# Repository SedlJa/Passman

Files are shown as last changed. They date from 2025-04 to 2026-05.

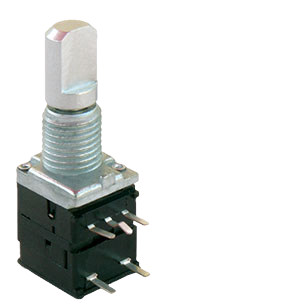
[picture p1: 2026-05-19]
_docs/pec09.png

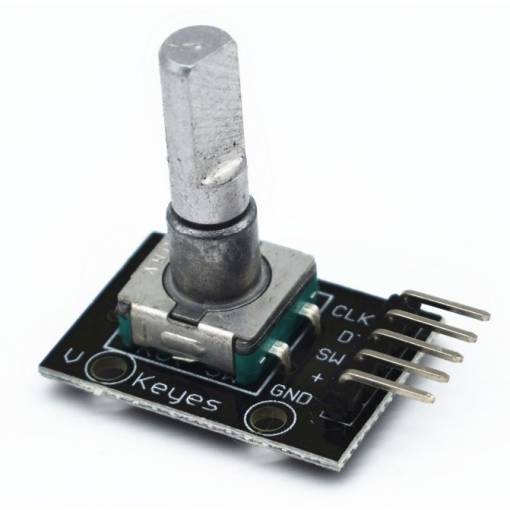
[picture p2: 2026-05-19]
_docs/ky040.jpg

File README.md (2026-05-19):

# Passman

Passman is an embedded password manager with a custom hardware device and a desktop companion application. The project is developed as part of a master's thesis at CTU FEE and combines an ESP32-S3 based device, biometric authentication, local password storage, USB serial communication, and a Python desktop GUI.

The goal is to create a portable hardware password manager that stores credentials locally on the device and allows the user to view, edit, upload, and download the password database through a dedicated desktop application.

## Repository Structure

```text
HW/                 Hardware design files
  pcb/              KiCad PCB project, schematics, BOM and assembly outputs
  Fusion/           3D enclosure models and exported STL files
  block_diagram.svg System block diagram
  PassMan_schematic_v2.1.pdf
  pcb_v2.png
  pcb_2v1.png

SW/
  firmware/         ESP32-S3 firmware built with PlatformIO
  app/              Python / PySide6 desktop application

_docs/              Project documentation and supporting materials
```

## Hardware

The hardware part contains the custom PCB and enclosure design for the Passman device.

Main components:

- ESP32-S3-WROOM-1 module
- 128x64 OLED display with SH1106 controller
- Fingerprint sensor connected over UART
- Rotary encoder with push button
- USB-C connector for power, flashing, and serial communication
- Li-Po battery input and charging circuit
- MCP73831 Li-Po charger
- STBB1-APUR voltage regulator
- User LEDs and reset / boot buttons

Hardware files include:

- KiCad schematic and PCB project
- PDF schematic export
- BOM
- Assembly output
- PCB preview images
- Fusion 360 enclosure exports
- STL files for 3D printing

## Firmware

Firmware is located in `SW/firmware` and is built with PlatformIO.

Target board:

```ini
esp32-s3-devkitm-1
```

Framework:

```ini
Arduino
```

Main firmware features:

- Fingerprint based unlock
- PIN fallback after failed fingerprint attempts
- OLED menu system
- Rotary encoder navigation
- Local password database stored in SPIFFS
- USB serial communication with the desktop app
- Device information reporting
- Password database load, upload, save, and delete actions

Used libraries:

- Ai Esp32 Rotary Encoder
- Adafruit SH110X
- Adafruit GFX
- Adafruit Fingerprint Sensor Library
- ArduinoJson

### Build and Upload Firmware

```bash
cd SW/firmware
pio run
pio run -t upload
pio run -t uploadfs
```

Serial monitor:

```bash
pio device monitor -b 115200
```

## Desktop Application

The desktop app is located in `SW/app`. It is written in Python using PySide6 and communicates with the Passman device over a serial port.

Main app features:

- COM port search and connection handling
- Device information display
- Load password database from device
- Add, edit, and delete password entries
- Upload database back to device
- Password visibility toggle
- Password generator
- Local clearing of displayed data after disconnect

### Run the App

```bash
cd SW/app
python3 -m venv env
source env/bin/activate
pip install -r requirements.txt
python app.py
```

Python dependencies are listed in `SW/app/requirements.txt`.

## Communication

The desktop application and firmware communicate over USB serial at `115200 baud`.

Supported commands include:

- `info` - read device information
- `load` - load database from the device
- `download` - send updated database to the device
- `disconnect` - close the app-device session

## Security Notice

This project is currently a prototype / thesis implementation. Before using it for real credentials, the security model should be reviewed and hardened.

## Author

- Author: Bc. Jan Sedlak
- Supervisor: Ing. Ondrej Nentvich, Ph.D.
- University: Czech Technical University in Prague
- Faculty: Faculty of Electrical Engineering
- Field: Internet of Things Technology
- Department: Department of Radioelectronics

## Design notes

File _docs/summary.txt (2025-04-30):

Diplomová práce 

Microcontroller 
- ESP32-C5 (nejspis tento)
- Nordic - nRF52 
- Raspberry Pi zero w

Memory
- SD karta
- Flash
- EEPROM

Security
- šifrování dat a komunikace
- otisk prstu - optional

Software
- webové UI
- desktop app (Qt?)

Realizace
Samostatné zařízení, které by sloužilo jako „trezor“ pro databázi hesel,
která bude na zařízení zároveň uložena. Uživatelská data budou uložena v zašifrované podobě.
Zařízení se bude dát připojit k PC, ve kterém poběží uživatelksé prostředí. 
To bude sloužit pro správu samotné databáze. 
Databáze bude ve soubor formátu sql, json nebo txt.
Ovládání menu v zařízení bude realizováno pomocí tlačítek/enkodéru.

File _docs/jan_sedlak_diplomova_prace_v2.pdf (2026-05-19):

### České

### vysoké

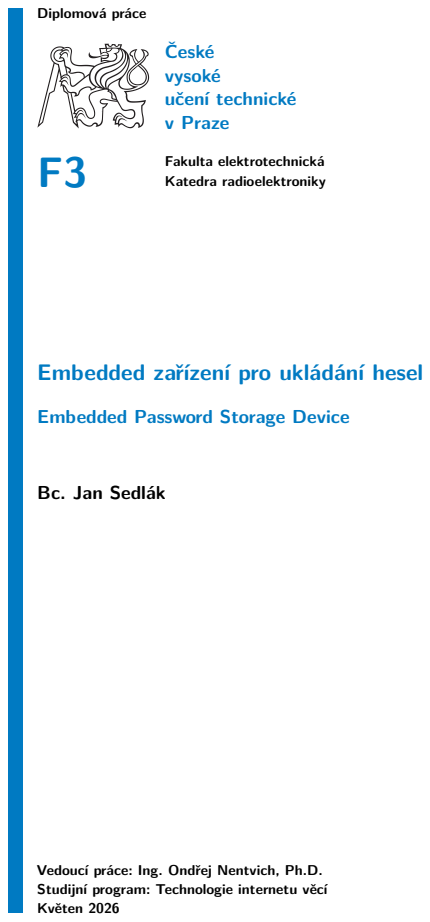
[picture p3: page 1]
Diplomová práce; učení technické v Praze; Fakulta elektrotechnická; Katedra radioelektroniky

Embedded zařízení pro ukládání hesel

Embedded Password Storage Device

Bc. Jan Sedlák

Vedoucí práce: Ing. Ondřej Nentvich, Ph.D.
Studijní program: Technologie internetu věcí
Květen 2026

ii

# ZADÁNÍ BAKALÁŘSKÉ PRÁCE

I. OSOBNÍ A STUDIJNÍ ÚDAJE
Příjmení: | Sedlák | Jméno: | Jan | Osobní číslo: | 507277
Fakulta/ústav: | Fakulta elektrotechnická

Zadávající katedra/ústav: Katedra radioelektroniky

Studijní program: Elektronika a komunikace

II. ÚDAJE K BAKALÁŘSKÉ PRÁCI

Název bakalářské práce:

Embedded zařízení pro ukládání hesel

Název bakalářské práce anglicky:

Embedded Password Storage Device

Pokyny pro vypracování:

Proveďte rešerši možných variant zařízení pro ukládání dat, zejména se poté orientujte na ukládání přístupových údajů a jejich šifrování. Následně navrhněte a realizujte elektronické zařízení pro správu hesel a klíčů s využitím mikrokontroléru. Pro autorizaci přístupu ke správě záznamů využijte zadání uživatelského přístupového hesla nebo otisk prstu. Zadávání a předávání hesel s mikrokontrolérem realizujte s pomocí grafické aplikace.

Seznam doporučené literatury:

[1] NOVIELLO, Carmine. Mastering STM32. 2nd. Leanpub, 2022.
[2] KLEIDERMACHER, David a Mike KLEIDERMACHER. Embedded Systems Security. Elsevier, 2012. ISBN 978-0-12-386886-2.
[3] MAREŠ, Martin a Tomáš VALLA. Průvodce labyrintem algoritmů. Praha: CZ.NIC, 2017. ISBN 978-80-88168-19-5.

Jméno a pracoviště vedoucí(ho) bakalářské práce:

Ing. Ondřej Nentvich, Ph.D. katedra radioelektroniky FEL

Jméno a pracoviště druhé(ho) vedoucí(ho) nebo konzultanta(ky) bakalářské práce:

Datum zadání bakalářské práce: 24.01.2024 | Termín odevzdání bakalářské práce: 24.05.2024

Platnost zadání bakalářské práce: 21.09.2025

___________________________ | ___________________________ | ___________________________ prof. Mgr. Petr Páta, Ph.D. podpis děkana(ky)
doc. Ing. Stanislav Vítek, Ph.D.
podpis vedoucí(ho) ústavu/katedry

Ing. Ondřej Nentvich, Ph.D.
podpis vedoucí(ho) práce
III. PŘEVZETÍ ZADÁNÍ

Student bere na vědomí, že je povinen vypracovat bakalářskou práci samostatně, bez cizí pomoci, s výjimkou poskytnutých konzultací. Seznam použité literatury, jiných pramenů a jmen konzultantů je třeba uvést v bakalářské práci.

Datum převzetí zadání | Podpis studenta
CVUT-CZ-ZBP-2015.1 | © VUT v Praze, Design: VUT v Praze, VIC

iv

## Poděkování

TBD

## Prohlášení

Prohlašuji, že jsem předloženou práci vypracoval samostatně a že jsem uvedl veškeré použité informační zdroje v souladu s Metodickým pokynem o dodržování etických principů při přípravě vysokoškolských závěrečných prací.

V Praze, 16. dubna 2026

v

## Abstrakt

TBD

Klíčová slova: embedded systém, heslo, otisk prstu, šifrování, mikrokontrolér, správce hesel

## Abstract

TBD

Keywords: embedded system, password, fingerprint, encryption, microcontroller, password manager

vi

## Obsah

Úvod | 1
1 Teoretická část | 3

1.1.2 Délka: První úroveň ochrany . 3

1.3 Problematika zabezpečení

1.3.2 HSM (Hardware Security Module) vs TPM (Trusted Platform

1.3.3 TEE (Trusted Execution

1.3.5 Ochrana paměti (MPU/MMU) 11 1.3.6 Bezpečné OTA aktualizace

1.6 Kybernetické útoky na embedded

2 Návrh hardwaru | 21

2.7 Konstrukční řešení a návrh

3 Firmware | 31

3.2.1 Návrh komunikačního

3.3 Bezpečnostní modul a ochrana dat 33

3.3.3 Distribuce a správa

3.5 Optimalizace a specifická

4 Desktopová aplikace | 39
4.1 Architektura a datový model . . . 39
5 Ověření funkčnosti | 45
6 Závěr | 47
Zkratky | 49
Literatura | 51

vii

## Obrázky

1.1 Mooltipass [22] | 7
1.2 Trust Zone diagram [9] | 10
2.1 Blokové schéma zapojení | 21
2.2 Vybraný kontrolér ESP32 S3
WROOM 1 | 23
2.3 Zapojení kontroléru ESP32 S3 . . 23 2.4 Vstupní část power managementu 25 2.5 Nabíjecí obvod Li-Pol baterie . . . 25 2.6 Navržený Buck-Boost zdroj . . . . 26
2.7 Vybrané komponenty | 28
2.8 Layout navrženého PCB | 29
2.9 Pohled shora | 30
3.1 Master-Slave architektura | 32
3.2 Otisk prstu | 34
3.3 UI: Přidání nového otisku prstu 34
3.4 UI: Database | 35
3.5 UI: Connect to Device | 36
3.6 UI: Save Database | 36
3.7 UI: Delete Database | 36
3.8 UI: Device Info | 37
3.9 Diagram logiky firmwaru | 37
4.1 Strktura aplikace | 40
4.2 Připojovací sekce aplikace | 41
4.3 Databáze hesel | 42
4.4 Nástroje | 43
4.5 Funkce generování hesla | 43
4.6 Uživatelské rozhraní aplikace . . . 44

## Tabulky

1.1 Příklady softwarových správců
hesel | 5
1.2 Přehled klíčových komponent
Secure bootu | 8
1.3 Porovnání HSM vs TPM | 10
1.4 Typické použítí TEE | 11
1.5 Porovnání MPU vs MMU | 13

2.1 Porovnání klíčových parametrů
jednotlivých kontrolérů | 24
2.2 Porovnání spínaného zdroje s
LDO | 26
2.3 Technické parametry vybraného
displeje | 27
2.4 Technické parametry senzoru
DY50 | 27
2.5 Technické parametry eknodéru
KY040 | 28
3.1 Placeholder Caption | 35

viii

## Úvod

Heslo. Pojem, který zná každý z nás. Dnes a denně jej používáme a vytváříme nové. Přesto často nedbáme na jeho dostatečnou sílu a způsob uložení. Stáváme se tak jednoduchým cílem kybernetických útoků, a to ve světě, kde je digitální identita naprosto klíčová, může mít často fatální následky. Jedním z řešení je využít správce hesel, tedy nástroj, který umožňuje vytvářet silná hesla, bezpečně je ukládat a minimalizovat šanci na jejich odcizení.

Práce zkoumá jak možnosti bezpečného ukládání hesel, šifrování i hardwarové zabezpečení, tak i vybrané způsoby autentizace uživatele. Cílem této práce je provést rešerši aktuální nabídky nástrojů pro správu hesel a jejich šifrování a následně zrealizovat elektronické zařízení pro správu přístupových údajů s desktopovou aplikací.

Tato práce přináší nejen vhled do problematiky dnešní digitální bezpečnosti, ale také praktickou implementaci v podobě samotného zařízení. Jejím cílem je přispět k lepší ochraně digitální identity prostřednictvím uživatelsky přívětivých nástrojů pro správu hesel.

1

2

## Kapitola 1

## Teoretická část

V úvodu teoretické části se zaměřím, jak by mělo vypadat kvalitní, silné a neprolomitelné heslo, které má parametry odpovídající dnešní době. Tyto informace využiji pro porovnání jednotlivých řešení správců hesel. Následně rozeberu závažnost správného výběru šifrování, které podrobně analyzuji. V poslední části se zaměřím na autentizaci uživatele, kde na základě provedené rešerše přiblízím čtenáři nejbezpečnější způsoby ověření uživatele.

### 1.1 Heslo

Heslo je řetězec znaků, který slouží k ověření identity uživatele během jeho autentizace. Hesla se obvykle používají společně s dalším bezpečnostním prvkem, uživatelským jménem; jsou navržena tak, aby je znal pouze uživatel, kterému umožňují získat přístup k zařízení, aplikaci nebo webové stránce [?].

### 1.1.1 Anatomie hesla

Vytvoření neprolomitelného hesla vyžaduje mnohem více než jen kombinaci písmen a číslic. Pokud k jeho tvorbě chceme přistoupit zodpovědně, musíme brát v úvahu několik faktorů, které definují jeho sílu. Mezi hlavní faktory patří délka, komplexnost a unikátnost.

### 1.1.2 Délka: První úroveň ochrany

V době, kdy procesory dosahují neuvěřitelných rychlostí, hraje délka hesla klíčovou roli při určování jeho síly. Čím delší heslo, tím více existuje možných kombinací, což hackerům výrazně snižuje šanci na jeho prolomení. Minimální bezpečná délka je dnes uváděna jako 12 znaků, za předpokladu, že jsou použita malá a velká písmena, číslice a speciální symboly [1].

### 1.1.3 Komplexnost

Komplexnost je dalším, neméně důležitým faktorem, který dokáže ovlivnit sílu hesla a učinit z něj doslova neprolomitelný klíč. Uživatel by se měl vyvarovat čemukoliv, co ho s heslem byť jen nepatrně spojuje, jako jsou jména, oblíbené

3

# 1. Teoretická část |

sportovní týmy, důležitá a snadno dohledatelná data. Místo toho je vhodné
použít zcela náhodná slova v kombinaci s čísly a symboly. Teprve tímto způsobem jsme schopni vytvořit neprolomitelné heslo [16].

### 1.1.4 Unikátnost

Používání stejného hesla pro několik různých přístupů je dnes nejčastější chybou, kterou dělá prakticky každý. Pramení z toho riziko, že pokud se útočníkovi podaří prolomit jedno vaše heslo, automaticky získá přístup i do ostatních účtů "chráněných"stejným heslem. Mít unikátní heslo pro každý jednotlivý účet se zdá být nemožným úkolem; přesto je však zásadním prvkem pro vaši bezpečnost. Přesně z tohoto důvodu je doporučeno používat správce hesel. Na trhu je jich nepřeberné množství a je tak pouze na uživateli, aby si vybral takového, který mu bude nejvíce vyhovovat [16].
PŘIDAT NĚJAKOU ZMÍNKU Z PRŮZKUMŮ, JAK LIDI PO-UŽÍVAJÍ HESLA KOLIK JICH MAJI ATD

### 1.2 Správci hesel

Správce hesel je softwarový nebo hardwarový nástroj primárně navržený ke generování, uchovávání a správě přístupových údajů. Základním bezpečnostním principem většiny správců hesel je šifrování databáze s využitím silných symetrických šifer (standardně AES-256). K odemčení této databáze používá uživatel hlavní heslo.

Hlavní heslo se nikdy neukládá v prostém textu; místo toho se z něj pomocí funkcí pro derivaci klíče (KDF – Key Derivation Function, typicky PBKDF2, Argon2 nebo bcrypt) vygeneruje šifrovací klíč. Národní institut standardů a technologie (NIST) ve svém doporučení SP 800-63B výslovně podporuje používání správců hesel, neboť eliminují nutnost pamatovat si velké množství komplexních hesel a minimalizují riziko jejich recyklace [6].

Moderní správci hesel se z prostých šifrovaných databází vyvinuli v komplexní nástroje pro správu digitální identity. Kromě samotného bezpečného uložení přihlašovacích údajů nabízejí sadu funkcí, které zvyšují jak bezpečnost, tak uživatelskou přívětivost:

. Generování kryptograficky silných hesel - Schopnost automaticky

vytvářet hesla s vysokou entropií.
. Automatické vyplňování - Nástroj detekuje doménu webové stránky

a automaticky vyplní přihlašovací údaje. Kromě pohodlí jde o klíčovou ochranu proti phishingu – pokud uživatel klikne na podvodný odkaz (např. g00gle.com), správce hesel pole nevyplní, protože doména neodpovídá uloženému záznamu.
. Bezpečné sdílení - Možnost asymetricky zašifrovat konkrétní záznam a

bezpečně jej sdílet s jiným uživatelem (např. v rámci rodiny nebo firmy),

4

# | 1.2. Správci hesel

aniž by heslo bylo odesláno přes nezabezpečené kanály, jako je e-mail nebo chat.
. Podpora vícefaktorové autentizace (MFA) a správa TOTP -

Většina správců hesel dnes umí generovat jednorázová hesla (Time-based One-Time Password), čímž nahrazuje dedikované aplikace jako Google Authenticator.
. Monitoring kompromitovaných hesel a Dark Webu - Nástroje

automaticky porovnávají hashe uložených hesel s databázemi uniklých přihlašovacích údajů (např. služba Have I Been Pwned) a aktivně uživatele upozorňují na nutnost změny.
. Nouzový přístup - Funkce umožňující delegovat přístup do trezoru

pověřené osobě po uplynutí předem stanovené čekací doby (např. v případě nehody či úmrtí).

### 1.2.1 Rozdělení Správců hesel

Správce hesel lze rozdělit z hlediska samotné implementace a způsobu úložení dat na dvě hlavní kategorie - softwarová a hardwarová řešení.

Softwarová řešení

Softwaroví správci hesel existují nejčastěji jako samostatné aplikace pro operační systémy nebo jako rozšíření pro webové prohlížeče. Dále se dělí na cloudové (data jsou synchronizována přes servery poskytovatele, např. Bitwarden, 1Password), lokální (data neopouštějí zařízení, např. KeePass) a správce v rámci prohlížečů (Google Chrome, Mozilla Firefox a další).

Typ | Název
Lokální Lokální Lokální Cloudový Cloudový Cloudový | KeePassXC Valutwarden Enpass Bitwarden Dashline Proton Pass

Tabulka 1.1: Příklady softwarových správců hesel

Lokální správci hesel
U lokálních správců (např. KeePassXC, Password Safe) je zašifrovaná databáze uložena výhradně na fyzickém úložišti uživatele a nikdy není automaticky přenášena přes internet. Mezi hlavní výhody patří naprostá kontrola nad daty. Tím, že data neopouštějí zařízení, útočník bez fyzického přístupu k zařízení nebo bez infikování stroje malwarem je nemůže získat. Nic není dokonalé a i lokální řešení přináší svá rizika:

5

# 1. Teoretická část |

. Ztráta a fragmentace dat - Pokud uživatel nebude svá data průběžně

zálohovat a dojde k selhání hardwaru, je ztráta dat nevratná. Synchronizace napříč zařízeními (např. přes USB nebo sdílený disk) často vede ke kolizím verzí databáze.
. Forenzní a paměťová zranitelnost - Jak ve své studii prokázali Gray

et al. (2016), lokální správci hesel mohou být zranitelní vůči analýze operační paměti (RAM). Výzkum ukázal, že po odemčení databáze nebo dokonce po uzavření aplikace mohou fragmenty hlavního hesla či dešifrovaných dat zůstat v paměťových stránkách, odkládacích souborech (pagefile) nebo dočasných složkách, odkud je může sofistikovaný malware extrahovat [7].

Cloudoví správci hesel
Tato řešení (např. Bitwarden, 1Password) ukládají zašifrované trezory na centrálních serverech poskytovatele. Využívají tzv. architekturu nulové znalosti (Zero-Knowledge architecture), což znamená, že veškeré šifrování a dešifrování probíhá lokálně na koncovém zařízení uživatele a na server se odesílá pouze zašifrovaný řetězec dat. Hlavní výhodou je dokonalá a okamžitá synchronizace napříč všemi platformami, na kterých je uživatel přihlášen, a automatické zálohování zajištěné poskytovatelem. Stejně jako lokální řešení, ani cloudoví správci se neobejdou bez rizik:
. Hromadné úniky dat ze strany poskytovatele - Servery poskytova-

telů představují vysoce atraktivní cíl (tzv. honeypot) pro kyberzločince. Pokud útočníci prolomí infrastrukturu poskytovatele, mohou zkopírovat zašifrované trezory všech uživatelů. Zde vzniká riziko offline dictionary útoku: pokud má uživatel slabé hlavní heslo, útočník jej může na vlastním výkonném hardwaru bez omezení počtu pokusů prolomit.
. Závislost na infrastruktuře třetí strany - Výpadek serverů může

dočasně zamezit přidávání či synchronizaci nových hesel.
. Útoky na dodavatelský řetězec (Supply Chain) - Zneužití aktuali-

začního mechanismu nebo zkompromitování webového klienta může vést k podvržení škodlivého kódu (např. JavaScriptu), který by hlavní heslo zachytil dříve, než dojde k lokálnímu zašifrování.

Správci hesel v prohlížečích
Prohlížeče jako Google Chrome, Mozilla Firefox nebo Microsoft Edge dnes obsahují nativní správce hesel. Jsou hluboce integrovány do webového rozhraní a spjaty s uživatelským profilem prohlížeče. Hlavní výhodou je jednoduchost vstupu pro běžného uživatele. Nevyžadují instalaci žádného dodatečného softwaru a fungují plynule z pohledu uživatelského zážitku (UX). Je tedy zcela na uživateli, zda se pro jeho užívání rozhodne. Oproti předchozím řešením mívají tito správci omezené funkce. Velkým rizikem použití mohou být podvržené webové stránky s neviditelným formulářem, který zneužívá funkci automatického vyplnění údajů.

6

| 1.3. Problematika zabezpečení embedded zařízení

### 1.2.2 Hardwarové řešení

Fyzická řešení představují oddělená hardwarová zařízení navržená tak, aby chránila šifrovací klíče a hesla mimo běžný operační systém. Patří sem specializovaní hardwaroví správci hesel a bezpečnostní tokeny (např. YubiKey, Trezor), které k autentizaci využívají protokoly FIDO2, WebAuthn nebo UWB (Ultra-Wideband) lokalizaci pro potvrzení fyzické přítomnosti [3]. Na trhu již existovalo několik typů embedded správců hesel, žádný z nich se však neuchytil v běžném každodenním používání.

Za zmínku stojí například PasswordFast a PasswordSafe, obě zařízení disponovala klávesnicí a displejem, nicméně pro každodenní používání byla nepraktická. Nejkomplexnějším řešením bylo zařízení Mooltipass, které bylo zabezpečeno hlavním heslem a šifrováním AES-256. Umožňovalo připojení k libovolnému zařízení pomocí bluetooth a následné doplňování údajů do přihlašovacích formulářů. Pozdější verze disponovala i rozšířením do prohlížeče.

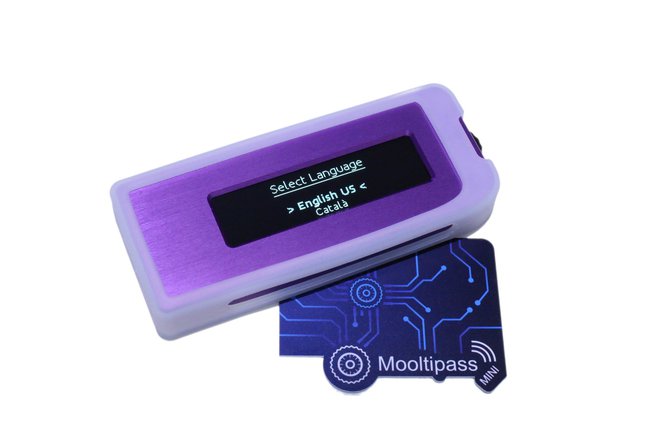
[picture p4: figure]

Obrázek 1.1: Mooltipass [22]

### 1.3 Problematika zabezpečení embedded zařízení

Zabezpečení embedded zařízení se v posledních letech stalo kritickou disciplínou, především kvůli masivnímu rozvoji Internetu věcí (IoT). Na rozdíl od běžných počítačů jsou embedded systémy často nasazeny v nekontrolovaném prostředí, což je vystavuje nejen síťovým, ale i přímým fyzickým útokům. Z tohoto důvodu je třeba myslet na zabezpečení systému již v samotném počátku jeho návrhu. V této sekci bude rozebráno několik softwarových i hardwarových způsobů ochrany, které se používají pro embedded systémy.

### 1.3.1 Secure boot

Secure Boot je kritický bezpečnostní mechanismus, který zajišťuje, aby se v zařízení spustil pouze software, který je autentický a nebyl nijak pozměněn. V prostředí embedded systémů se jedná o nejdůležitější prvek ochrany, protože tvoří tzv. Root of Trust, na kterém stojí veškeré další zabezpečení [11].

7

# 1. Teoretická část |

Princip Rooot of trust

Základní myšlenkou Secure Bootu je, že každá komponenta softwaru před svým spuštěním ověří integritu a autenticitu následující komponenty. Pokud je řetězec v kterémkoli bodě přerušen, nesedí podpis, systém se zastaví a odmítne pokračovat v bootování. Celkový řetězec může vypadat následovně:

.1. Hardware / Mask ROM - Neupravitelný kód vypálený přímo v

procesoru výrobcem. Obsahuje veřejný klíč výrobce.

.2. First Stage Bootloader (FSBL) - Kód ověřený pomocí Mask ROM.

.3. Main Bootloader - Ověřen předchozím bootloaderem.

.4. Operační systém (Kernel) - Ověřen bootloaderem.

.5. Aplikace / Souborový systém - Ověřeny kernelem.

Jak probíhá proces ověření?
Proces využívá asymetrickou kryptografii a hashovací funkce. Při výrobě výrobce vezme binární kód a vytvoří z něj hash, unikátní otisk. Tento hash poté zašifruje svým soukromým klíčem. Výsledkem je digitální podpis, který se přiloží k samotnému firmwaru. Při spuštění pak procesor vypočítá hash firmwaru a pomocí veřejného klíče, který je uložen v dedikované zabezpečené části hardwaru, dešifruje přiložený digitální podpis. Pokud se vypočítaný hash shoduje s dešifrovaným hashem z podpisu, je potvrzeno, že [17]:
. Kód pochází od držitele soukromého klíče - tím je dodržena Autenticita.

. Kód nebyl od okamžiku podpisu změněn ani o jediný bit - tím je zajištěna

Integrita.

Tabulka 1.2: Přehled klíčových komponent Secure bootu

Komponenta | Popis
Root of Trust (RoT) | Hardwarový základ (často ROM kód), který nelze změnit. Je to “první článek”, kterému systém věří implicitně.
Kryptografické klíče | Veřejné klíče jsou uloženy v zařízení (často v tzv. eFuses – jednorázově programovatelných pamětech), soukromé klíče má výrobce v přísně střeženém prostředí (HSM).
eFuses | Miniaturní elektronické pojistky v čipu. Jakmile se jednou “přepálí” (nastaví na 1), nelze je změnit zpět na 0. Slouží k trvalému uložení hashe veřejného klíče.
Revokační seznamy | Seznamy “zakázaných” klíčů nebo verzí softwaru. Pokud je zjištěna zranitelnost ve starší verzi, Secure Boot díky nim zabrání tzv. Rollback útoku (nucený návrat ke starší, zranitelné verzi).

Secure boot chrání před nasazením rootkitu a bootkitu, což jsou malware, které se snaží usadit v systému ještě před startem antiviru nebo samotného

8

| 1.3. Problematika zabezpečení embedded zařízení

operačního systému. Zároveň znemožňuje útočníkovi nahrát vlastní, upravený firmware či rovnou vyměnit flash paměť s kódem. V takovém případě by hash nesouhlasil.

Použití secure bootu přináší i svá úskalí v podobě ztráty klíčů. Pokud výrobce ztratí soukromé klíče, je nemožné vydat aktualizaci pro existující zařízení. V případě výskytu chyby v samotném RoT je chyba uložena v ROM paměti a daný hardware je tak trvale a neopravitelně kompromitován [21].

### 1.3.2 HSM (Hardware Security Module) vs TPM (Trusted

Platform Module)

Hardware Security Module

Zatímco TPM je zaměřen na integritu platformy, HSM je vysoce výkonné zařízení zaměřené na správu životního cyklu klíčů a masivní kryptografické operace. V embedded světě se často setkáváme s Hardware Security Engine (HSE) nebo Secure Hardware Extension (SHE), což jsou "lehčí"verze HSM integrované přímo v mikrokontrolérech (např. v automotive průmyslu) [14].

HSM jsou optimalizovány pro rychlé zpracování kryptografických operací, jako jsou AES, RSA nebo ECC, bez zatěžování hlavního procesoru.

Samotné HSM běží na vlastním kódu, který je zcela nezávislý na hlavním firmwaru zařízení. Při proniknutí útočníka do hlavního systému tak zůstává HSM neovládnut [4].

Trusted Platform Module

TPM je mezinárodní standard pro bezpečný kryptoprocesor. V embedded systémech se nejčastěji vyskytuje jako samostatný čip připojený přes sběrnici (SPI, I2C) nebo jako integrovaná součást SoC (System on Chip) [14].

TPM dokáže hashovat stav systému během bootování, a pokud dojde ke změně firmwaru nebo jeho konfigurace, hash v konfiguračních registrech nebude odpovídat a TPM odmítne vydat dešifrovací klíč.

Disponuje bezpečným uložištěm pro ukládání hesel, certifikátů a šifrovacích klíčů. Klíče jsou označeny jako neexportovatelné a nikdy neopustí čip v čitelné podobě. Pro dosažení silné kryptografie disponuje TPM také hardwarovým generátorem náhodných čísel [4].

### 1.3.3 TEE (Trusted Execution Environment)

Trusted Execution Environment (TEE) je bezpečné, izolované prostředí uvnitř hlavního procesoru, které běží paralelně s hlavním operačním systémem. Toto

9

# 1. Teoretická část |

Tabulka 1.3: Porovnání HSM vs TPM

Funkce | TPM (Trusted Platform Module) | HSM (Hardware Security Module)
Hlavní účel | Integrita zařízení a bezpečný boot. | Rychlá kryptografie a ochrana klíčů.
Výkon | Nižší (vhodné pro autentizaci). | Vysoký (vhodné pro šifrování streamů dat).
Typ klíčů | Často pevně vázané na hardware. | Flexibilní správa tisíců klíčů.
Standardy | TCG (Trusted Computing Group). | FIPS 140-2 (Level 3/4), Common Criteria.
Typické použití | Notebooky, průmyslová PC, brány. | Bankovní terminály, servery, řídicí jednotky aut.

prostředí je hardwarově odděleno od zbytku procesoru. Zatímco hlavní operační systém je optimalizován pro výkon a konektivitu, TEE je navržen s prioritou a optimalizací pro bezpečnost a integritu dat [15].

Nejrozšířenější implementací TEE je technologie ARM TrustZone. Ta rozděluje procesor na dvě virtuální domény:
. Normal World (Non-secure) - Zde běží běžný OS (např. Linux,

Android) a uživatelské aplikace. Přístup do Secure world je striktně omezen.
. Secure World - Zde běží veškerý Trusted OS a v něm izolované mikro-

aplikace, známé jako Trusted Applications.

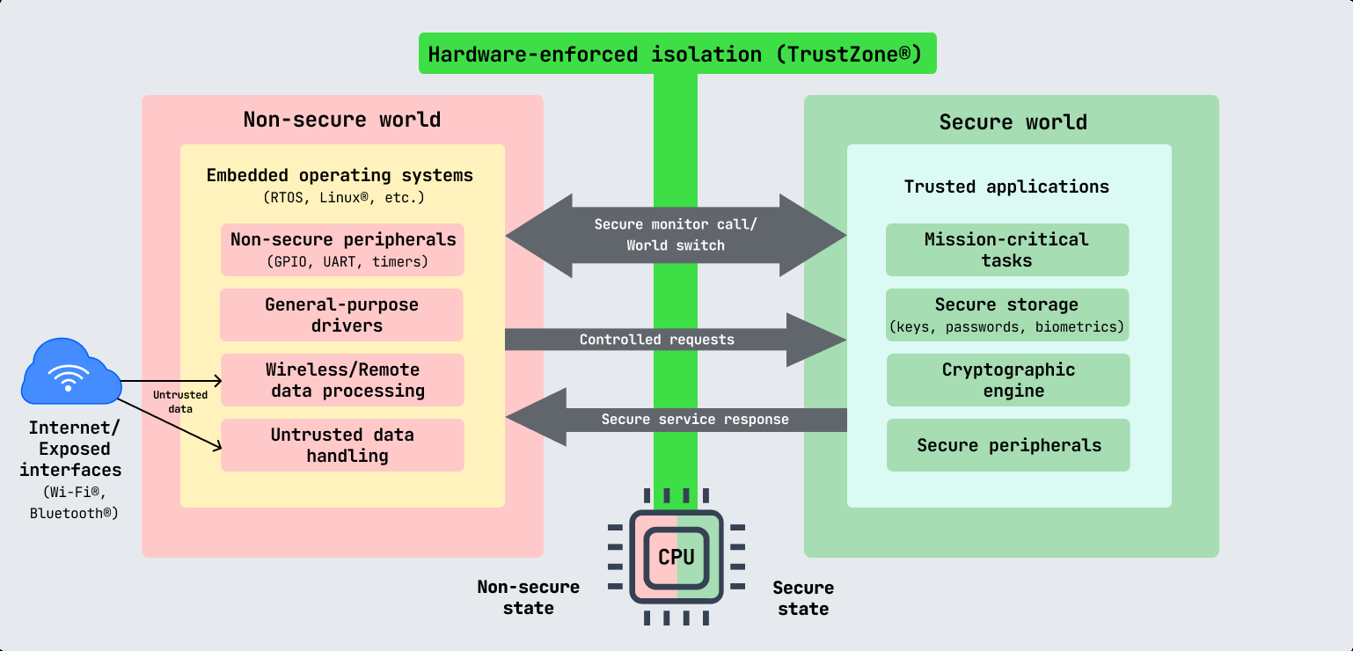
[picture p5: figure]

Obrázek 1.2: Trust Zone diagram [9]

Z obrázku 1.2 lze vidět, jakým způsobem probíhá komunikace mezi oběma částmi procesoru. Z nezabezpečeného světa vyšle operační systém kontrolo-

10

| 1.3. Problematika zabezpečení embedded zařízení

vaný dotaz, Controlled request, v tento okamžik je aktivován i Secure monitor, který dohlíží na veškerou komunikaci. Po zpracování požadavku odesílá Trusted aplikace odpověď, neboli Secure Service Response. S odesláním odpovědi se secure monitor opět vypíná.

TEE poskytuje tři základní pilíře ochrany. Prvním je izolace. Jak bylo již napsáno, hardwarová izolace v rámci samotného SoC zajistí, že ani při ovládnutí jádra operačního systému nemůže útočník číst paměť TEE nebo do ní zapisovat. Druhým pilířem je důvěryhodné uložiště, Trusted storage, kdy TEE má přístup do zašifrované části paměti, kam se ukládají citlivá data, jako jsou otisky prstů či privátní klíče. Posledním piliřem je vzdálená atestace, což je schopnost prokázat vzdálené protistraně, že zařízení běží v autentickém a bezpečném stavu. V následující tabulce 1.4 naleznete přehled typického použití TEE.

Tabulka 1.4: Typické použítí TEE

Oblast | Využití v TEE
Biometrika | Zpracování a porovnávání otisků prstů nebo skenů obličeje (data nikdy nevidí Android/Li-nux).
Finanční transakce | Bezpečné potvrzení platby a ochrana PINu při zadávání na obrazovce (Trusted UI).
DRM (Digital Rights Management) | Dešifrování prémiového obsahu (např. Netflix v 4K) přímo v bezpečném prostředí, aby nebylo možné stream zachytit.
Kryptografické ope-race | Podepisování transakcí pomocí klíčů, které nejsou přístupné hlavnímu procesoru.

### 1.3.4 Code Signing

Code Signing slouží v embedded systémech jako ochranná pečeť pro samotný zdrojový kód. Je používán jako nástroj pro samotný Secure Boot mechanismus zaručující autenticitu a integritu firmwaru [11].

### 1.3.5 Ochrana paměti (MPU/MMU)

V systémech s omezenými zdroji je paměť často sdíleným prostředkem. Bez hardwarové ochrany může jediná chyba v aplikaci vést ke zhroucení celého systému nebo jeho zneužití útočníkem pro injekci malwaru. Mezi nejčastější chyby patří například přetečení bufferu paměti nebo chybný ukazatel proměnné. K eliminaci těchto rizik slouží dedikované hardwarové jednotky integrované v procesoru.

11

# 1. Teoretická část |

Memory Protection unit (MPU)

Memory protection unit je zjednodušená verze ochrany paměti, která se nachází především v mikrokontrolérech, například ARM Cortex-M. MPU nepracuje s virtuální pamětí, ale přímo s fyzickými adresami.

Paměť je rozdělena do několika fixních částí, typicky 8 až 16. Každá část má programátorem definovanou počáteční adresu, velikost a přístupová práva. Každá část může disponovat různými režimy přístupu.
. Read-Only (RO)

. Read-Write (RW)

. Execute-Never (XN)

Režim Execute-Never je kritickým režimem pro zabezpečení paměti, jelikož zabraňuje procesoru vykonávat kód z datových oblastí, jako je zásobník/stack. Tento režim funguje jako primární obrana proti útokům typu Stack Overflow [23].

V případě, že se kód pokusí přistoupit do nepovoleného regionu paměti, MPU vyvolá hardwarovou výjimků, která okamžitě zastaví proces a umožní systému bezpečně zareagovat.

Memory Management Unit (MMU)

Memory Management Unit je pokročilejší jednotka využívaná v aplikačních procesorech, například ARM Cortex-A, které provozují komplexní operační systémy, jako jsou Linux nebo QNX.

Hlavním rozdílem oproti MPU je podpora virtuálního adresního prostoru. Každý proces má pocit, že vlastní celý paměťový prostor, zatímco MMU mapuje tyto virtuální adresy na reálné fyzické adresy pomocí stránkování (paging) [19]. Díky MMU jsou jednotlivé procesy dokonale izolované a jeden proces fyzicky nemůže vidět do paměti druhého procesu, pokud není nastavená sdílená paměť.

MMU úzce spolupracuje s úrovňemi oprávnění procesoru, user vs. kernel mode. To zajišťuje, že aplikace v uživatelském rozhraní nemohou měnit nastavení hardwaru nebo přistupovat k paměti jádra [11].

### 1.3.6 Bezpečné OTA aktualizace (Over-The-Air)

U moderních IoT zařízení je kritickou funkcí Over the Air (OTA) aktualizace. V praxi to znamená, že zařízení je možné bezpečně aktualizovat bez nutnosti fyzického připojení. Aktualizace je považována za bezpečnou, je-li zdrojový kód opatřen výše zmiňovaným Code signignem, v případě jeho absence by útočník mohl podvrhnout vlastní škodlivý firmware, například pomocí útoku

12

# | 1.4. Autentizace

Tabulka 1.5: Porovnání MPU vs MMU

Funkce | MPU | MMU
Typ zařízení | Mikrokontroléry (RTOS) | Aplikační procesory (Linux/Android)
Adresování | Pouze fyzické adresy | Virtuální adresování
Granularita | Velké regiony | Malé stránky (typicky 4 KB)
Hlavní přínos | Prevence chyb (Safety) | Plná izolace procesů (Security)

Man in the Middle, který by mu zajistil plnou kontrolu nad zařízením a volný přístup do celého systému. Standardy jako NIST SP 800-147 ¹ striktně
vyžadují, aby každý update prošel verifikací dříve, než dojde k jeho zápisu do flash paměti zařízení [5].

### 1.4 Autentizace

Autentizace je jedním ze základních pilířů informační bezpečnosti. Jedná se o proces ověření deklarované identity subjektu (typicky uživatele), který žádá o přístup k chráněným zdrojům nebo systémům. Na rozdíl od identifikace, která pouze určuje, o koho se jedná, autentizace prokazuje, že daný subjekt je skutečně tím, za koho se vydává[20].

V moderních informačních systémech se autentizační metody dělí primárně do tří kategorií (tzv. autentizačních faktorů)[13]:
. Znalostní faktor - Něco, co uživatel zná - heslo, pin.

. Faktor vlastnictví - Něco, co uživatel vlastní - hardwarový token,

čipová karta, mobilní telefon.
. Biometrický faktor - Něco, čím uživatel skutečně je - otisk prstu,

geometrie obličeje.

Tato kapitola se zaměřuje na detailní rozbor vybraných znalostních a biometrických metod, konkrétně na využití hlavního hesla, PIN kódu a na autentizaci pomocí otisku prstu, s důrazem na princip fungování optického senzoru, který byl využit pro zhotovení prototypu embedded správce hesel. Znalostní metody autentizace Znalostní faktory jsou historicky nejstarším a nejrozšířenějším způsobem ověřování identity. Jejich princip spočívá v tom, že autentizační systém i uživatel sdílejí určité tajemství.

Hlavní heslo

Heslo je řetězec znaků, který slouží k přístupu do systému. V kontextu centralizovaných nebo komplexních systémů se často využívá koncept tzv. hlavního hesla (Master Password), které odemyká přístup k dalším dílčím heslům nebo kryptografickým klíčům (např. u správců hesel)[2]. Jak se tvoří neprolomitelné

1https://nvlpubs.nist.gov/nistpubs/legacy/sp/nistspecialpublication800-147.pdf

13

# 1. Teoretická část |

heslo, bylo již popsáno v sekci 1.1.

Bezpečnost hesla závisí na jeho entropii (délce a složitosti) a na způsobu, jakým je uchováváno na straně serveru či zařízení. Z bezpečnostních důvodů se hesla nikdy nesmí ukládat v otevřené (plaintext) podobě. Standardem je využití jednosměrných kryptografických hašovacích funkcí (např. SHA-256, Argon2, bcrypt) v kombinaci s tzv. solí (salt) – náhodným řetězcem dat přidaným k heslu před hašováním. Tím se systém chrání proti útokům hrubou silou, slovníkovým útokům a využití předpočítaných duhových tabulek (rainbow tables)[18].

PIN (Personal Identification Number)

PIN plní podobnou funkci jako heslo, avšak s několika klíčovými rozdíly. Typicky se jedná o kratší, čistě numerický řetězec (nejčastěji 4 až 8 číslic). Vzhledem k výrazně nižší entropii ve srovnání s alfanumerickými hesly by byl PIN v online prostředí snadno překonatelný útokem hrubou silou.

Z tohoto důvodu je PIN zpravidla vázán na konkrétní fyzické zařízení (např. mobilní telefon, čipová karta, bankomat), čímž v podstatě vytváří dvoufaktorovou autentizaci (vlastnictví zařízení + znalost PINu). Zařízení samo pak implementuje ochranné mechanismy proti hádání, nejčastěji v podobě progresivního časového zpoždění nebo trvalého zablokování po určitém počtu neúspěšných pokusů (typicky třech).

Biometrická autentizace

Biometrie představuje moderní přístup k autentizaci, který eliminuje nutnost pamatovat si tajemství. Identifikace probíhá na základě jedinečných fyziologických nebo behaviorálních charakteristik uživatele[8].
newline

Autentizace otiskem prstu

Autentizace pomocí otisku prstu (daktyloskopie) je jednou z nejprozkoumanějších a komerčně nejúspěšnějších biometrických metod. Využívá jedinečnosti papilárních linií na bříškách prstů, které se formují již během fetálního vývoje a zůstávají neměnné po celý život.

Při digitalizaci otisku moderní systémy zpravidla neukládají kompletní obraz prstu. Místo toho algoritmy extrahují tzv. markanty (minutiae) – specifické body, jako jsou ukončení papilární linie, její rozdvojení (bifurkace), očka či háčky. Z těchto bodů se vytvoří matematická šablona (biometric template), která je zašifrována a uložena. Při každém dalším přiložení prstu senzor vytvoří novou šablonu a porovná ji s tou uloženou. Pokud míra shody (match score) překročí definovanou prahovou hodnotu, je uživatel autentizován[12].

14

# | 1.4. Autentizace

Princip fungování optického senzoru
Pro sejmutí obrazu otisku prstu se využívá několik technologií (kapacitní, ultrazvukové, optické). Optické senzory patří k nejstarším, avšak díky inovacím (např. integraci pod displeje mobilních telefonů) zůstávají stále velmi aktuálními technologiemi.

Optický senzor funguje v zásadě jako specializovaný digitální fotoaparát. Skládá se ze tří hlavních komponent:
. Zdroj světla, typicky pole LED diod.

. Dotyková plocha / hranol, kam se přikládá prst.

. Snímací čip

Fyzikální princip snímání (FTIR) Většina moderních optických senzorů využívá fyzikální jev zvaný narušený úplný vnitřní odraz (FTIR – Frustrated Total Internal Reflection). Když světlo ze zdroje vstoupí do skleněného hranolu pod určitým úhlem, dojde na rozhraní skla a vzduchu (kde není přiložen prst) k úplnému vnitřnímu odrazu. Světlo se odrazí zpět do nitra hranolu a dopadne na snímací čip.

Když uživatel přiloží prst na sklo, nedotýká se plochy celou kůží, ale pouze hřebeny papilárních linií. V místech, kde se hřebeny (ridges) dotýkají skla, se změní index lomu světla na rozhraní. Úplný vnitřní odraz je v těchto bodech "narušen"– světlo je absorbováno nebo rozptýleno do kůže prstu. Naopak v místech údolí (valleys) mezi papilárními liniemi zůstává mezi sklem a kůží mikroskopická vrstva vzduchu, a proto zde k úplnému vnitřnímu odrazu nadále dochází[12].

Výsledkem je, že snímací CMOS/CCD čip zaznamená vysoce kontrastní 2D obraz:
. Tmavé oblasti - Představují hřebeny papilárních linií (světlo se rozptý-

lilo do prstu).
. Světlé oblasti - Představují údolí a místa bez kontaktu (světlo se

odrazilo do senzoru).

Tento obraz je následně převeden do digitální podoby, vyčištěn od šumu, zvýrazněn a předán softwarovým algoritmům k extrakci výše zmíněných markantů. Nevýhodou základních optických senzorů je jejich náchylnost k oklamání pomocí kvalitních 2D fotografií nebo 3D odlitků prstů, proto jsou dnešní systémy často doplňovány o techniky detekce živosti (liveness detection), jako je měření pulsu nebo prokrvení tkáně.

15

# 1. Teoretická část |

### 1.5 Šifrování

### 1.6 Kybernetické útoky na embedded systémy

Dnešní svět je plný věstavěných systémů, od jednoduchých spotřebičů, jako jsou mikrovlnné trouby, až po chytrá auta. Embedded systémy do značné míry ulehčují naše životy; na druhou stranu však přidávají další možnosti pro útočníky, jak se zmocnit našeho soukromí.

Kybernetická bezpečnost je i v tomto odvětví velice důležitá. Valná většina chytrých systémů dnes generuje, přenáší a zpracovává signifikantní množství dat, která jsou pro hackery lákadlem.

Embedded systémy jsou náchylné na kybernetické útoky hned z několika důvodů. Prvním z nich je existence dvou zranitelných oblastí, a to jak na hardwarové, tak na softwarové úrovni. Dalším důvodem je, že přeplnění malého vestavěného systému mnoha funkcemi vede k nedostatečné bezpečnostní koncepci. Navíc integrace vestavěných systémů do internetu věcí (IoT) zvyšuje počet útočných vektorů, které by se mohly zaměřit právě na tyto systémy[10].

### 1.6.1 Softwarové útoky

.1. Útoky na paměť (Memory Corruption)

Většina embedded systémů je psána v jazycích C nebo C++, které poskytují přímý přístup k paměti, ale postrádají automatickou ochranu. . Buffer Overflow (Přetečení zásobníku/haldy) - Útočník odešle

více dat, než kolik dokáže přidělená paměť pojmout. Přetečená data mohou přepsat návratovou adresu funkce, čímž útočník získá kontrolu nad tokem programu.

. Arbitrary Code Execution (ACE) - Cíl útoku na paměť. Útoč-

ník do systému "podstrčí"vlastní kód (shellcode) a donutí procesor, aby jej vykonal.

. Return-Oriented Programming (ROP) - Moderní technika,

která obchází ochranu proti spuštění kódu v datových segmentech tím, že skládá útok z malých částí legitimního kódu (gadgets) již přítomného v paměti.

.2. Zranitelnost komunikačních protokolů

. Injekce (Injection Attacks) - Pokud systém nedostatečně filtruje

vstup, může útočník vložit škodlivé příkazy (např. SQL injection u bran, nebo Command Injection v CLI rozhraní).

16

| 1.6. Kybernetické útoky na embedded systémy

. Replay Attack (Útok opakováním) - Útočník zachytí legitimní

zprávu (např. signál k odemknutí chytrého zámku) a později ji znovu odešle bez nutnosti znát šifrovací klíč.

. Man-in-the-Middle (MitM) - Útočník se vloží mezi zařízení a

cloud/bránu. Pokud chybí autentizace certifikátů, může data číst i měnit.

.3. Útoky na firmware a bootloader

. Firmware Downgrade - Útočník donutí zařízení nainstalovat

starší verzi firmwaru, která obsahuje známé a již dříve opravené bezpečnostní chyby.

. Úprava Update balíčků - Pokud firmware není kryptograficky

podepsán, může útočník nahrát upravenou verzi (backdoor), která mu zajistí trvalý přístup.

. Secure Boot Bypass - Softwarová chyba v bootloaderu, která

umožní spustit nepodepsaný kód hned při startu systému.

Prevence a obrana
Obrana proti těmto útokům zahrnuje techniky, jako jsou Secure Boot, použití ASLR (Address Space Layout Randomization), pravidelné podepsané aktualizace (OTA) a statickou analýzu kódu během vývoje.

### 1.6.2 Síťové útoky

.1. Útoky na komunikační protokoly

Mnoho embedded zařízení používá protokoly, které byly navrženy pro efektivitu, nikoliv pro bezpečnost (např. MQTT, CoAP, Modbus).
. Replay Attack - Útočník zachytí platný síťový paket (např. příkaz

"odemknout zámek") a později jej odešle znovu. Pokud systém nemá implementované sekvenční číslování nebo časová razítka, příkaz provede znovu.

. Protocol Fuzzing - Odesílání neočekávaných nebo poškozených

datových paketů do síťového stacku zařízení s cílem vyvolat pád systému (DoS) nebo odhalit zranitelnosti typu přetečení zásobníku (buffer overflow)

.2. Denial of Service (DoS) a Resource Exhaustion

Embedded systémy mají často velmi limitovanou RAM a procesorový výkon.
. Flooding - I malý objem provozu (např. ICMP/Ping flood) může

zahltit síťové rozhraní mikrokontroléru, který nestíhá pakety zahazovat.

17

# 1. Teoretická část |

. Sleep Deprivation Attack - Cílí na bateriově napájená zařízení

(IoT). Útočník neustále posílá drobné síťové požadavky, které nutí zařízení zůstat v "probuzeném"stavu, čímž dojde k rychlému vybití baterie.

.3. Útoky na webová rozhraní a API

Většina moderních embedded zařízení nabízí webovou administraci pro snadnou konfiguraci.
. Default Credentials - Útočníci skenují síť a zkouší tovární hesla

(admin/admin). U embedded systémů uživatelé tato hesla mění mnohem méně často než u e-mailů.

. Command Injection - Pokud webové rozhraní špatně ošetřuje

vstupy, útočník může skrze formulář odeslat příkaz pro operační systém zařízení (např. spustit shell).

. Insecure Over-the-Air (OTA) Updates - Pokud se firmware

stahuje přes nešifrované HTTP bez digitálního podpisu, útočník může podvrhnout upravený, škodlivý firmware.

Bezpečnostní doporučení proti síťovým typům útoků
Pro dosažení robustnosti a odolnosti systému je vhodné implementovat: . Šifrování - pro veškerou externí komunikaci.

. Secure boot - Pro ověření integrity firmwaru při startu zařízení.

.Watchdog timer - Pro automatický restart zařízení pri zahlcení či pádu

po DoS útoku.
. Certifikace zařízení - Přiřadit unikátní klíč pro každé zařízení.

### 1.6.3 Útok postraními kanály

Zatímco moderní kryptografické algoritmy (jako AES nebo RSA) jsou matematicky vysoce odolné proti přímému prolomení, jejich fyzická implementace v hardwaru může unikat informace o probíhajících výpočtech. Útoky využívající tyto neúmyslné úniky informací se nazývají útoky postranními kanály (Side-Channel Attacks).

Na rozdíl od klasické kryptoanalýzy, která hledá slabiny v samotném matematickém návrhu algoritmu, útoky postranními kanály obcházejí teoretickou bezpečnost tím, že sledují fyzické projevy zařízení během kryptografických operací.

Klasifikace útoků postranními kanály
Tyto útoky lze rozdělit podle sledované veličiny, kterou útočník měří. Níže jsou vypsány nejčastější druhy útoků na vestavěné systémy.

18

| 1.6. Kybernetické útoky na embedded systémy

.1. Časová analýza

Časová analýza zkoumá dobu potřebnou k provedení určitých kryptografických operací. Pokud doba zpracování závisí na vstupních datech nebo na tajném klíči, může útočník tyto citlivé údaje odvodit.
. Příklad: Pokud algoritmus ověřující heslo (nebo PIN) kontroluje

znaky postupně a při první neshodě proces ukončí, zabere zamítnutí hesla s chybným prvním znakem méně času než zamítnutí hesla, kde je chyba až ve třetím znaku. Útočník tak může uhodnout správné heslo znak po znaku.

.2. Odběrová analýza (Power Analysis)

Každá operace prováděná mikroprocesorem nebo mikrokontrolérem spotřebovává určité množství elektrické energie. Spotřeba se mění v závislosti na tom, jaké instrukce se právě vykonávají a jaká data jsou zpracovávána (např. přepínání bitů z 0 na 1 vyžaduje více energie).
. Simple Power Analysis - Spočívá v přímém vizuálním zkoumání

grafu spotřeby energie v čase. Umožňuje identifikovat hrubé rysy algoritmu, například rozeznat podmíněné skoky, které závisí na hodnotách tajného klíče.

. Differential Power Analysis - Mnohem sofistikovanější a nebezpeč-

nější metoda. Využívá statistickou analýzu velkého množství měření (tisíce až miliony vzorků) spotřeby energie. DPA dokáže odhalit korelaci mezi spotřebovanou energií a manipulovanými daty, čímž útočník získá tajný klíč i v případě, že je signál silně zarušen.

.3. Elektromagnetická analýza (Electromagnetic Analysis)

Místo spotřeby elektrického proudu útočník měří elektromagnetické vyzařování, které zařízení generuje během provozu.
. Výhoda pro útočníka - Pomocí citlivých mikrosond může útočník

měřit vyzařování lokálně – přímo nad konkrétní částí čipu (například nad kryptografickým koprocesorem), čímž se vyhne šumu z ostatních komponent zařízení. Metody analýzy (SEMA, DEMA) jsou analogické k analýze spotřeby (SPA, DPA).

.4. Akustická a optická analýza

Ačkoliv jsou tyto útoky u běžných mikrokontrolérů vzácnější, některé elektronické součástky (např. kondenzátory nebo cívky) mohou při zátěži vydávat vysokofrekvenční zvuky. Měřením tohoto akustického signálu lze teoreticky odvodit informace o prováděných instrukcích. Podobně může vyzařování fotonů z polovodičových přechodů (optický kanál) prozradit stavy tranzistorů, to však vyžaduje speciální vybavení a odkrytý čip.

Obrana proti útokům postranními kanály
Návrh vestavěných systémů odolných proti SCA vyžaduje kombinaci hardwarových a softwarových protiopatření. Cílem je buď eliminovat závislost

19

# 1. Teoretická část |

fyzických projevů na zpracovávaných datech, nebo snížit odstup signálu od
šumu (SNR) natolik, aby útok přestal být proveditelný.
. Constant-time algoritmy - Zajišťují, že provádění kódu trvá vždy naprosto

stejně dlouho, bez ohledu na hodnotu klíče či vstupu. Striktně se vyhýbají instrukcím podmíněného skoku na základě tajných dat.
. Maskování - Citlivá data se před výpočtem logicky zkombinují (obvykle

operací XOR) s náhodně vygenerovanou hodnotou (maskou). Výpočet pak probíhá nad těmito náhodnými daty a maska je odstraněna až na samém konci.
. Hardwarová ochrana - Zařazení generátorů hardwarového šumu, které

ztěžují zjištění užitečného signálu. Náhodné vkládání prázdných cyklů (dummy instructions) nebo změn taktu hodin (clock jitter), což narušuje synchronizaci měření útočníka. Fyzické stínění čipu proti únikům elektromagnetického záření.

20

## Kapitola 2

## Návrh hardwaru

Tato kapitola se zabývá praktickým návrhem hardwarové části mé diplomové práce. Samotný návrh vychází z teoretických poznatků a specifikace požadavků, které byly definovány v teoretické části této práce 1. Cílem této části je vytvořit funkční prototyp, který bude splňovat požadavky na kompaktní rozměry, nízkou spotřebu a vlastní napájení.

Ještě před samotným návrhem jsem sestrojil funkční prototyp z jednotlivých vývojových kitů, které mi pomohly při prvotním návrhu.

### 2.1 Schéma zapojení

Na následujícím obrázku 2.1 je blokové schéma navrženého prototypu zařízení. Samotné schéma se skládá ze tří částí: kontrolér(žlutá), power management(modrá) a periferie(zelená).

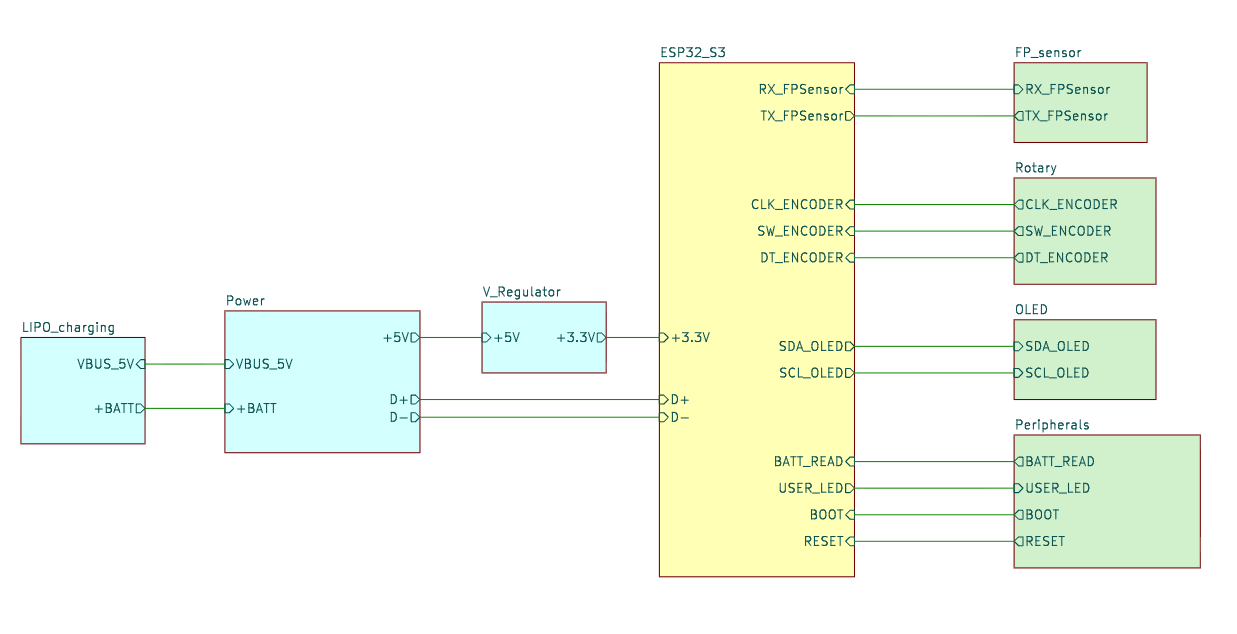
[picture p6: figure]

Obrázek 2.1: Blokové schéma zapojení

21

# 2. Návrh hardwaru |

### 2.2 Výběr kontroléru

Při výběru se rozhodovalo mezi třemi mikrokontroléry od různých výrobců. Prvním byl ESP32 S3 od společnosti Espressif Systems, druhým nRF52840 od společnosti Nordic a STM32H5xx od společnosti STMicroelectronics. Před samotným výběrem byly definovány požadavky:
. Nízká spotřeba

. Dostatečný grafický výkon

. Hardwarové zabezpečení

. Dostatečná frekvence mikrokontroléru,

Tabulka 2.1 poskytuje srovnání klíčových technických parametrů vybraných kontrolérů. Ačkoliv všechny analyzované mikrokontroléry disponují nativním rozhraním USB 2.0 Full Speed, dedikovanými kryptografickými akcelerátory a mechanismy ochrany paměti, pro finální realizaci byl zvolen modul ESP32-S3-WROOM-1U od společnosti Espressif Systems.

Hlavním argumentem pro volbu tohoto čipu je jeho vysoká taktovací frekvence až 240 MHz v kombinaci s dostačujícím grafickým výkonem. To umožňuje plynulou obsluhu zvoleného zobrazovacího modulu a responzivní uživatelské rozhraní. Významným benefitem je rovněž integrovaná podpora bezdrátových standardů Wi-Fi a Bluetooth 5 (Low Energy), které rozšiřují budoucí modularitu konektivity k aplikaci.

Z hlediska bezpečnosti představuje použití externí Flash paměti určitou nevýhodu. Toto řešení je náchylnější k útokům na fyzické vrstvě (např. odposlech sběrnice).

Vyšší proudový odběr v aktivním režimu je v kontextu aplikace přípustný, neboť zařízení je primárně napájeno z USB sběrnice uživatelského PC. Rozhodujícími faktory pro finální výběr byly kromě příznivých nákladů také široká nativní podpora periferií a existence robustních softwarových knihoven. Zapojení mikrokontroléru je znázorněno na obrázku 2.3.

### 2.3 Power management

Druhou částí, modře podbarvenou na schématu 2.1, je řízení napájení. Celý napájecí systém byl navržen tak, aby umožnil plynulý přechod mezi napájením z USB-C a interní Li-Pol baterie s kapacitou 650 mAh. Díky navrženému zdroji je poskytováno stabilní napětí pro celou digitální část zařízení.

22

# | 2.3. Power management

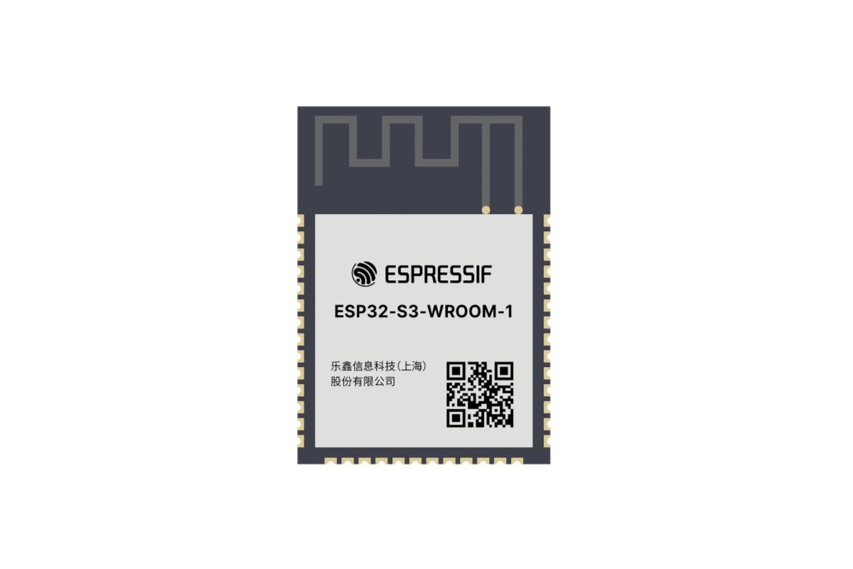
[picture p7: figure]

Obrázek 2.2: Vybraný kontrolér ESP32 S3 WROOM 1

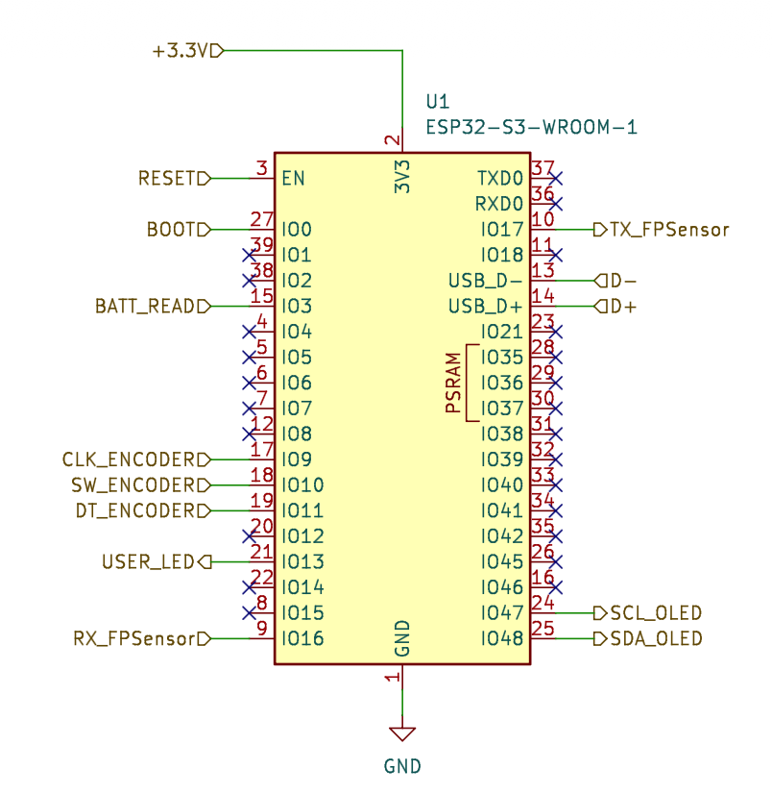
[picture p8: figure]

Obrázek 2.3: Zapojení kontroléru ESP32 S3

### 2.3.1 Vstupní část

Vstupní napájecí rozhraní tvoří konektor USB-C 2.0. Pro identifikaci napájecího zdroje jsou na pinech CC1 a CC2 připojeny rezistory 5,1 kΩ. Automatická volba zdroje je zaručena použitím P-kanálového MOSFET tranzistoru (Q1) v kombinaci se Schottkyho diodou(D3).
. USB: Napětí na hradle uzavře tranzistor Q1, čímž odpojí baterii a napájí

se přes diodu D3.
. Baterie: Po odpojení USB rezistor R14 stáhne hradlo k zemi, tranzistor

Q1 se otevře a zařízení se začne napájet z baterie.

### 2.3.2 Nabíjení baterie

Pro správu nabíjení bateriového článku byl zvolen specializovaný lineární kontrolér MCP73831T-2ACI/OT. Obvod zajišťuje nabíjecí cyklus typu CC/CV (Constant Current / Constant Voltage). Nabíjecí proud je definován hodnotou odporu R16 = 4, 7kΩ pripojeného k pinu PROG. Hodnota proudu odpovídá

23

# 2. Návrh hardwaru |

Tabulka 2.1: Porovnání klíčových parametrů jednotlivých kontrolérů

Parameter | Espressif ESP32-S3 | Nordic Semi nRF52840 | STMicro STM32H3 (např. H563)
Frekvence | 240 MHz | 64 MHz | 250 MHz
Paměť Flash | Externí (SPI/QSPI) | Interní | Interní
USB Rozhraní | Nativní USB Serial/JTAG + OTG | Nativní USB 2.0 (Full Speed) | Nativní USB 2.0 (Full Speed)
Bezpečnostní HW | AES-XTS (Flash Encl.), RSA, HMAC, Digital Signature | ARM CryptoCell-310 (AES, ECC, SHA) | TRUSTZone, AES, PKA, Hash, True RNG
Ochrana paměti | Secure Boot v2, Flash Encryption | Readback Protection | TrustZone
Grafický výkon | Vysoký (LCD rozhraní) | Nízký (SPI displeje, pomalé GUI) | Vysoký (Chrom-ART akcelerátor, paralelní LCD)
Bezdrátové služby | Wi-Fi + Bluetooth 5 (LE/Mesh) | Bluetooth 5 (LE/Mesh, NFC, Thread) | Žádná (Air-gapped device)
Spotřeba | Vysoká (<100 mA) | Velmi nízká ( 5 mA) | Střední/vyšší (dle modelu)
Cena čipu (USD) | $2 – $3 | $4 – $6 | $6 – $9

212 mA, což zajišťuje šetrné nabíjení zvoleného článku. Stav nabíjení je indikován červenou LED diodou (D4) připojenou na pin STAT. Při dosažení plného nabití dioda zhasne.

### 2.3.3 Návrh zdroje

Při návrhu zdroje bylo zapotřebí vyřešit změnu úrovně napětí z původních 5 V USB konektoru na pracovní úroveň mikrokontroléru ESP32 (3,3 V ). To lze vyřešit dvěma způsoby, použitím LDO regulátoru nebo spínaným zdrojem.

24

# | 2.3. Power management

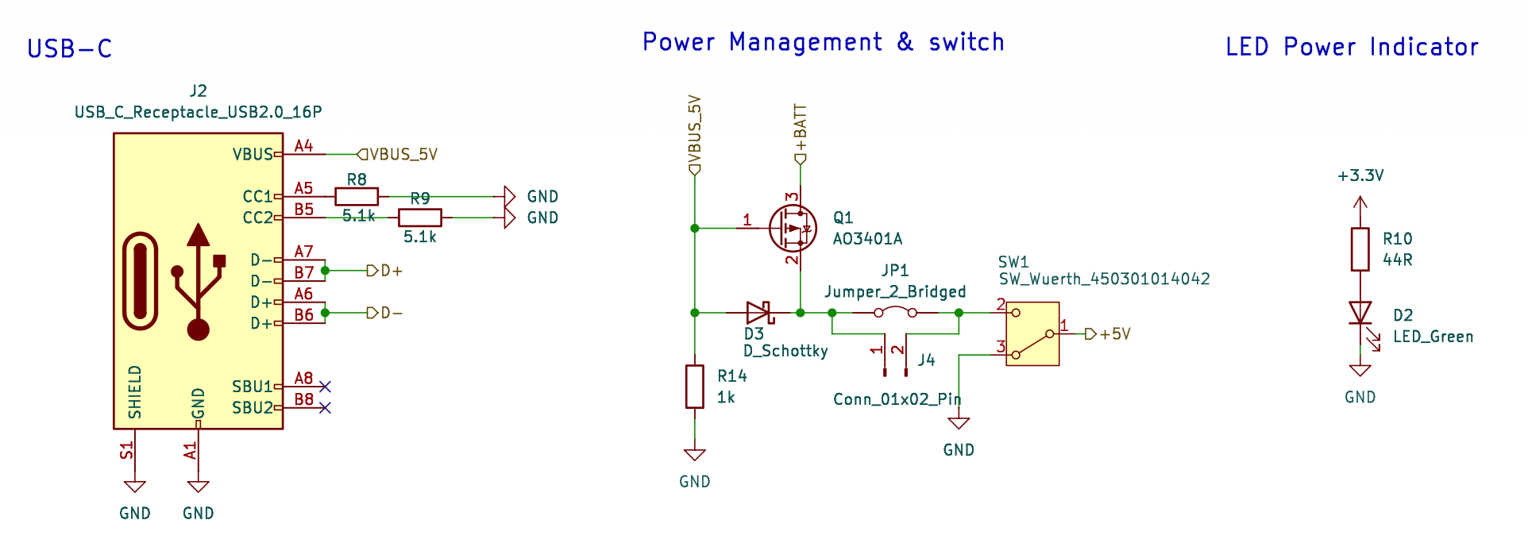
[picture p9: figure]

Obrázek 2.4: Vstupní část power managementu

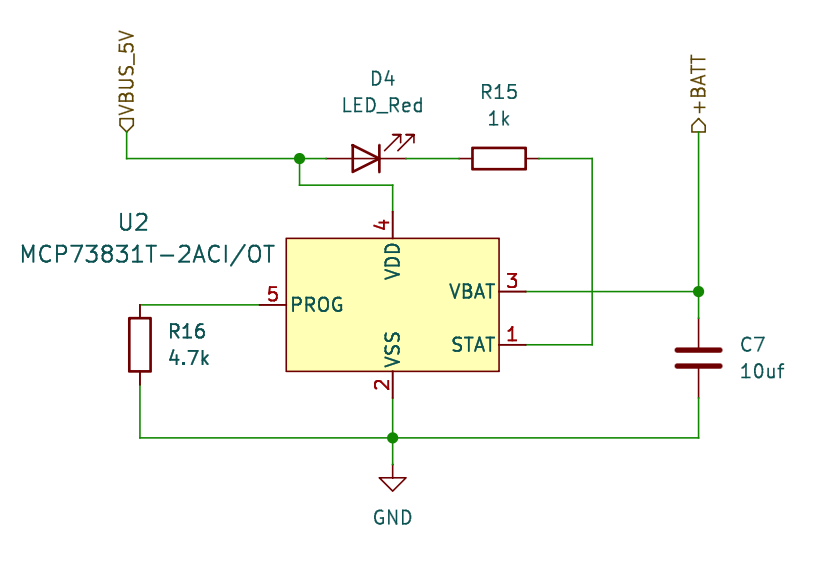
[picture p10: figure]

Obrázek 2.5: Nabíjecí obvod Li-Pol baterie

Low-dropout regulátor

LDO je lineární stabilizátor napětí, který dokáže udržovat konstantní úroveň napětí i v případě, že je vstupní napětí pouze velmi mírně vyšší než výstupní. LDO mění přebytečnou energii na teplo, tím se snižuje i celková výsledná účinnost regulátoru. Výhodou tohoto zdroje je jeho jednoduchost, základními komponenty jsou vstupní a výstupní kondenzátory spolu s integrovaným obvodem.

Spínaný zdroj

Na rozdíl od LDO regulátoru spínaný zdroj funguje na principu rychlého přepínání výkonového prvku, MOSFET tranzistoru. Spínaný zdroj tranzistor spíná v řádech desítek kHz až MHz, proto se doporučuje jeho umístění do oddělené části PCB, aby se zabránílo rušení. Spínaný zdroj doshauje oproti LDO vyšší účinnosti. Nevýhodou spínaného zdroje je jeho robustnost. Vyžaduje více základních komponentů a stává se tak dražší volbou.

V následující tabulce 2.2 je porovnání mezi vybraným zdrojem STBB1 od společnosti STMicroelectronics a LDO regulátorem AMS1117, který se velmi často používá pro návrh mikrokontrolérů ESP32.

25

# 2. Návrh hardwaru |

Tabulka 2.2: Porovnání spínaného zdroje s LDO

Vlastnost | Spínaný zdroj (STBB1) | Lineární regulátor (AMS1117)
Účinnost | Vysoká (typ. 85–95 %) | Nízká (66 %)
Tepelné ztráty | Minimální | Vysoké
Využití baterie | Úplné | Částečné
Šum a rušení | Vyšší | Velmi nízké

Z výše uvedených informací je zdánlivé, že použití spínaného zdroje bude výhodnější.

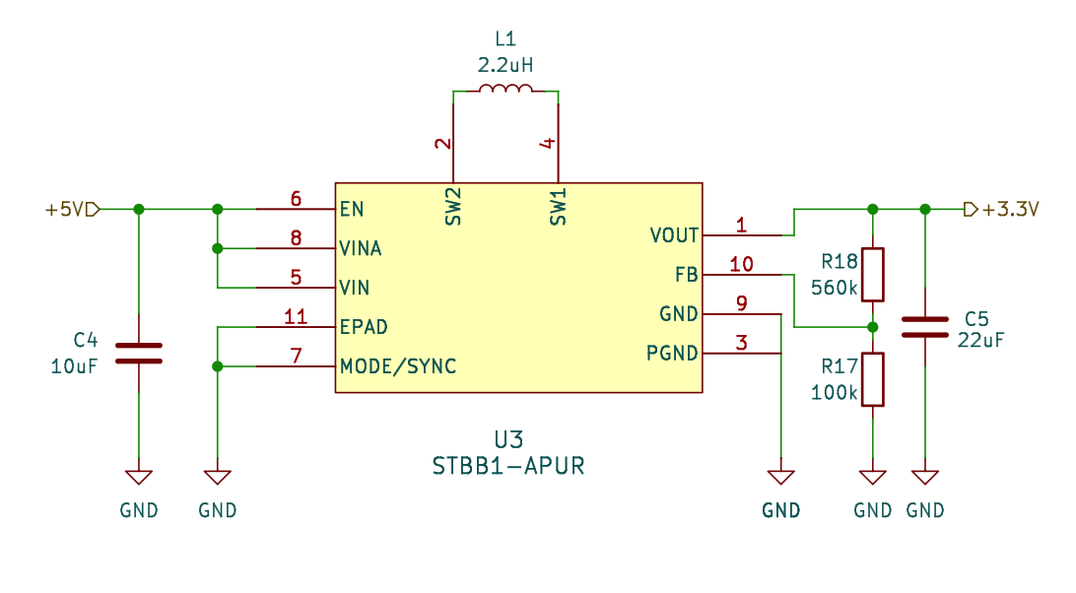
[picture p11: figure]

Obrázek 2.6: Navržený Buck-Boost zdroj

### 2.4 Výběr periferií

Na základě sestavení prvotního prototypu a výběru mikrokontroléru ESP32-S3 se tato sekce věnuje výběru jednotlivých hardwarových periferií. Hlavním kritériem při procesu selekce byla vzájemná napěťová kompatibilita na úrovni 3,3 V logiky a kompatibilita s dostupnými softwarovými knihovnami.

V následujících podsekcích jsou detailně popsány klíčové periferie, včetně odůvodnění jejich volby.

### 2.4.1 Displej

Pro uživatelské rozhraní byl zvolen OLED displej s úhlopříčkou 1,3"a rozlišením 128 × 64 pixelů, který je založen na řadiči SH1106. Hlavním důvodem volby technologie OLED je jeho vysoký kontrastní poměr. Jelikož displej nevyžaduje podsvícení, výrazně se tak snižuje jeho energetická náročnost.

26

# | 2.4. Výběr periferií

Komunikace s mikrokontrolérem probíhá přes sběrnici I2C, což minimalizuje počet potřebných pinů kontroléru a zjednodušuje návrh plošného spoje.

Tabulka 2.3: Technické parametry vybraného displeje

Parametr | Hodnota
Typ displeje | OLED
Řadič (Driver) | SH1106
Rozlišení | 128 × 64 px
Úhlopříčka | 1,3” (33,02 mm)
Vnitřní RAM řadiče | 132 × 64 bit
Komunikační rozhraní | I2C
Napájecí napětí | 3,3 – 5,0 V DC

### 2.4.2 Senzor otisků prstů

Jako biometrický bezpečnostní prvek byl vybrán otisk prstu. Pro jednoduchost byl vybrán senzor DY50, který je jedním z mála dostupných modelů za přijatelnou cenu. Jedná se o senzor s integrovaným optickým snímacím prvkem s pamětí až na 162 otisků. Přestože může být napájen až 5 V, datové piny jsou na 3,3V logice a jsou tak plně kompatibilní s mikrokontrolérem, se kterým komunikuje pomocí sběrnice UART.

Bezpečnostní parametr False Acceptance Rate (FAR) se vyjadřuje jako poměr počtu falešných akceptací k počtu pokusů o identifikaci, což udává podíl ověřovacích transakcí, při nichž jsou omylem potvrzeny nesprávné údaje totožnosti. FAR je klíčovým měřítkem pro hodnocení přesnosti a účinnosti biometrických bezpečnostních systémů, jako je software pro rozpoznávání obličeje nebo skenery otisků prstů. Nižší hodnota FAR znamená spolehlivější systém, zatímco vyšší hodnota FAR naznačuje vyšší riziko neoprávněného přístupu. Vybraný senzor DY50 dosahuje hodnoty < 0.001 %, díky této hodnotě lze senzor považovat za bezpečný.

Tabulka 2.4: Technické parametry senzoru DY50

Parametr | Hodnota
Napájecí napětí | 3,6 – 6,0 V DC
Provozní proud | 120 mA (max. 150 mA)
Komunikační rozhraní | UART
Kapacita úložiště | 162 šablon
Doba snímání | < 1,0 s
Chybovost (FAR) | < 0,001 %
Pracovní teploty | -20 °C až +50 °C

27

# 2. Návrh hardwaru |

### 2.4.3 Rotační eknodér

Pro interakci uživatele s grafickým rozhraním byl zvolen inkrementální rotační enkoder typu KY-040. Tento mechanický senzor převádí rotační pohyb hřídele na sérii digitálních pulsů, které jsou následně dekódovány mikrokontrolérem.

Princip funkce a zapojení

Modul KY-040 pracuje na principu kvadraturního kódování. Obsahuje dva spínače, které při otáčení generují dva fázově posunuté signály (označované jako CLK a DT). Sledováním fázového posuvu lze určit směr otáčení, zatímco počet pulzů určuje velikost úhlového posunutí. Enkodér také disponuje spínacím tlačítkem v ose hřídele. Toto umožňuje ovládat zařízení pomocí jednoho ovládacího prvku.

Tabulka 2.5: Technické parametry eknodéru KY040

Parametr | Hodnota
Pracovní napětí | 3,6 – 5,25 V DC
Počet pulzů na otáčku | 20
Životnost | 30 000 otáček

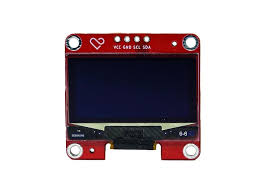
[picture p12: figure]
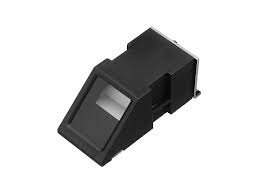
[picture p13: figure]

(a) : OLED displej 1,3" | (b) : Senzor otisků prstů DY50


(c) : Rotační enkodér s integrovaným tlačítkem KY-040

Obrázek 2.7: Vybrané komponenty

28

# | 2.5. Návrh layoutu

### 2.5 Návrh layoutu

Po vytvoření schématu zapojení, výběru vhodných komponent a ověření funkčnosti obvodu pomocí prototypu sestaveného z evaluačních desek bylo přistoupeno k návrhu vlastní desky plošných spojů (PCB). Tento krok umožnil optimalizovat výsledné řešení z hlediska rozměrů, elektrických vlastností i mechanické integrace do finálního zařízení.

Při návrhu layoutu byl kladen důraz na dosažení kompaktních rozměrů desky, které vycházely z požadavku na snadnou manipulaci se zařízením a jeho ovládání. Návrh obrysu desky byl proveden s ohledem na umístění hlavních funkčních bloků, přičemž byly respektovány technologické limity výroby plošných spojů.

Mikrokontrolér s anténou byl umístěn na opačném konci oproti spínanému zdroji, aby se předešlo rušení spínanou frekvencí zdroje. Zároveň byla snaha, aby všechny napájecí komponenty byly v blízkosti a nebylo nutné vést napájecí cesty přes celé PCB. Rotační enkodér spolu s posuvným spínačem byl umístěn na pravé straně, aby odpovídal přirozenému úchopu zařízení a umožnil intuitivní ovládání bez nutnosti změny polohy ruky.

Zvláštní důraz byl kladen na umístění poměrně rozměrného senzoru otisků prstů. Jeho konektor byl umístěn na spodní straně desky vedle USB konektoru, avšak pro samotný senzor byl určen výkus PCB v horní části. Toto umístění zaručuje ergonomičnost a usnadňuje jeho používání. Samotné usazení je vidět v sekci 2.7.

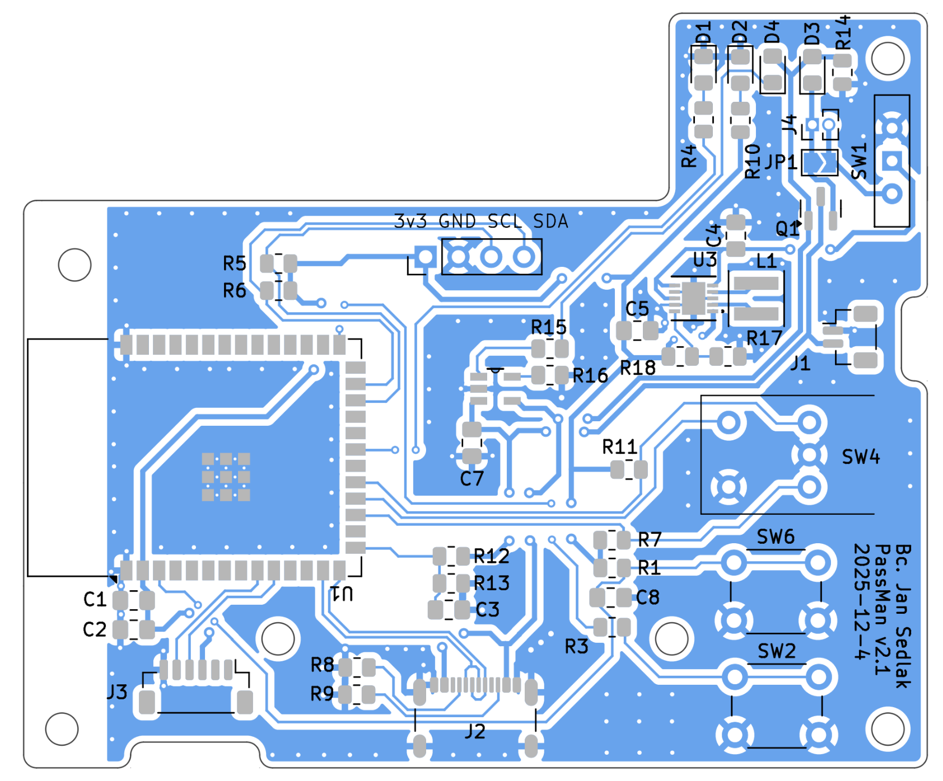
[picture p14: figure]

Obrázek 2.8: Layout navrženého PCB

29

# 2. Návrh hardwaru |

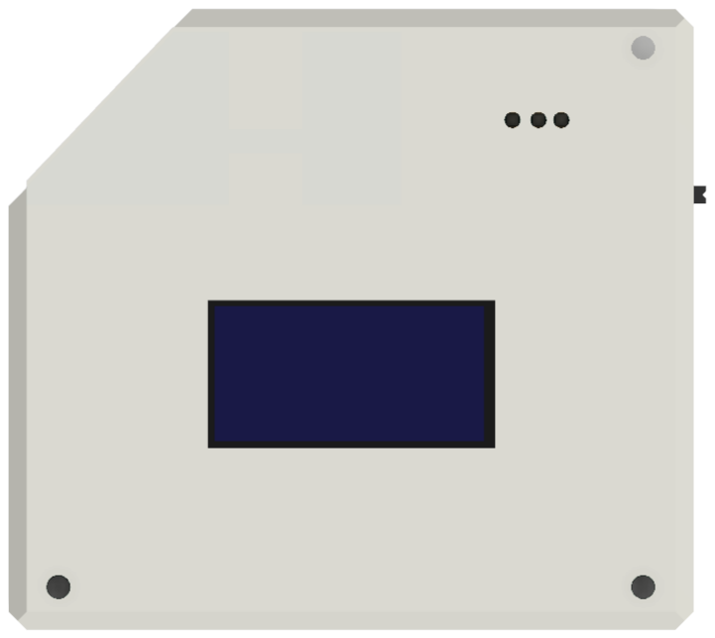
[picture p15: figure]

Obrázek 2.9: Pohled shora

### 2.6 Výpočet spotřeby zařízení

### 2.7 Konstrukční řešení a návrh krabičky

Cílem mechanického návrhu bylo vytvořit kompaktní a ergonomické řešení, které zajistí ochranu vnitřní elektroniky, fixaci komponent a komfortní ovládání zařízení jednou rukou. Jako výrobní technologie byl zvolen 3D tisk.

### 2.7.1 Postup návrhu

Samotné řešení vycházelo z navrženého PCB popsaného v sekci 2.5.

### 2.7.2 Vizualizace

30

## Kapitola 3

## Firmware

Tato kapitola se detailně věnuje návrhu a samotné implementaci firmwaru pro vyvinutého hardwarového správce hesel. Cílem bylo vytvořit stabilní a bezpečné prostředí, které zajišťuje veškerou logiku zařízení, od základní obsluhy databáze až po komunikaci s desktopovou aplikací.

Zvolený mikrokontrolér ESP32-S3 WROOM-1 disponuje vysokým výkonem a dostatečnou kapacitou paměti (SRAM i Flash) a integrovaným hardwarovým šifrovacím akcelerátorem, který byl pro vývoj bezpečnostního zařízení klíčový.

Vývoj firmwaru probíhal v programovacím jazyce C++. Využití tohoto jazyka umožnilo aplikovat objektivně orientovaný přístup (OOP), což přispělo k modularitě, čitelnosti a snadnější údržbě vysledného kódu. Projekt byl kompilován a spravován s využitím ekosystému PlatformIO pro MacOS.

Architektura firmwaru
Z hlediska softwarové architektury je firmware rozdělen do čtyř hlavních, na sobě nezávislých částí, což usnadňuje možnost úpravy a testování systému. Architektura se skládá z vrstvy správy dat, bezpečnostní vrstvy, komunikační vrstvy a uživatelského rozhraní.

### 3.1 Modul správy databáze

Jádrem firmwaru je systém obsluhující databázi hesel. Tento modul je zodpovědný za formátování dat, jejich bezpečné uložení do flash paměti zařízení a jejich následné načtení. Primárními operacemi jsou:
. Načtení databáze - Vždy po zapnutí zařízení automaticky, v rámci pr-

votního nastavení, načte databázi z flash paměti do operační paměti kontroléru pro potřeby zobrazení na displeji nebo pro odeslání do desktopové aplikace.
. Uložení databáze - Databáze je uložena pomocí souborového systému

SPIFFS do flash paměti kontroléru.

31

# 3. Firmware |

. Smazání databáze - Funkce pro bezpečné odstranění celé databáze ze

zařízení.

### 3.2 Komunikační rozhraní

Pro zajištění komunikace mezi hardwarovým správcem a desktopovou aplikací byl implementován vlastní komunikační protokol, viz sekce ??. Ke komunikaci je využíván sériový COM port.

Komunikační modul běží ve smyčce, kdy naslouchá příkazům z aplikace. Tyto požadavky jsou parsovány a na základě instrukcí (např. požadavek na načtení databáze ze zařízení, příkaz load) firmware provede příslušnou operaci v databázovém modulu a odešle zpět odpověď v podobě dat ze zařízení.

### 3.2.1 Návrh komunikačního protokolu

Komunikační protokol byl navržen pro zajištění komunikace mezi hardwarovým zařízením a desktopovou aplikací. Jedná se o textově orientovaný protokol fungující nad sériovým rozhraním. Po připojení k hostitelskému počítači se zařízení enumeruje jako sériový port (COM port). Komunikace probíhá asynchronně s přenosovou rychlostí 115200 baudů.

Inicializace relace (Handshake)
Protokol je navržen tak, aby po připojení obou komunikujících stran navázal spojení a přenesl informace o připojeném zařízení, jako je název zařízení, firmwarová verze, verze hardwaru a sériové číslo.

Tento krok slouží jako handshake, díky němu dokáže aplikace poznat, zda na komunikačním portu opravdu komunikuje kompatibilní zařízení.

Řízení toku dat
Po inicializačním procesu se z aplikace stává řídící uzel (Master) a zařízení pasivně naslouchá na sériové lince a čeká na příchozí instrukce. V rámci naslouchání byla definována již výše zmíněná sada instrukcí.

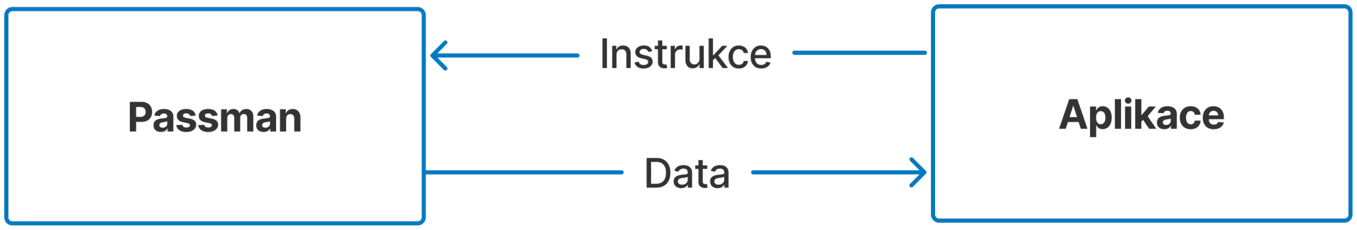
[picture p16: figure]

Obrázek 3.1: Master-Slave architektura

Instrukce: info
Tok dat: Zařízení → Aplikace
Popis operace: Identifikace zařízení: Zařízení opětovně vyšle své identifikační informace.

32

| 3.3. Bezpečnostní modul a ochrana dat

Instrukce: load
Tok dat: Zařízení → Aplikace
Popis operace: Export databáze: Zařízení vyšle zašifrovanou databázi hesel.

Instrukce: download
Tok dat: Aplikace → Zařízení
Popis operace: Import databáze: Aplikace vyšle databázi do zařízení, které na základě instrukcí ukládá dešifrovaná data.

Instrukce: end
Tok dat: lokální akce
Popis operace: Ukončení relace: Přijetím této instrukce se aplikace odpojí z komunikačního portu zařízení a zařízení se vrátí do hlavní nabídky.

### 3.3 Bezpečnostní modul a ochrana dat

Bezpečnostní modul, vzhledem k primárnímu účelu zařízení, je gró celého firmwaru. Tento modul nese zodpovědnost za autorizaci uživatele a integritu dat. Bezpečnostní systém je rozdělen na dvě hlavní oblasti: autentizaci uživatele a kryptografické operace.

### 3.3.1 Autentizace uživatele

Zařízení je zabezpečeno dvěma způsoby autentizace: otiskem prstu a čtyřmístným číselným pinem. Ihned po spuštění zařízení je uživatel požádán o přiložení otisku prstu. V případě třetího zamítnutí přístupu má uživatel možnost provést autentifikaci pomocí pinu, na který jsou další dva pokusy. Proti útokům hrubou silou (Brute-force) je systém chráněn zablokováním po pátem, respektive druhém neúspěšném pokusu o zadání PIN kódu. V tomto případě se zařízení zablokuje na dobu třiceti sekund.

Proces odemknutí zařízení je implementován jako stavový automat sledující unlockHandler. Výchozí hodnota po spuštění je nastavena na 0, tedy uzamčený stav. Přechod do odemčeného stavu je podmíněn úspěšnou validací uživatele otiskem prstu či zadáním správného pin kódu. Po úspěšné autentizaci je zařízení uživateli odemčeno.

V rámci autentizace uživatele byla implementována podpora uložení až 10 unikátních otisků prstů v rámci jednoho zařízení. Tato možnost zvyšuje komfort i flexibilitu používání zařízení. Databáze otisků prsů je uložena v paměti samotného senzoru.

. Obouruční ovládání - Umožňuje odemknout zařízení palcem i uka-

zováčkem obou rukou, což oceníte v situacích, kdy máte jednu ruku plnou.

33

# 3. Firmware |

Obrázek 3.2: Otisk prstu

Obrázek 3.3: UI: Přidání nového otisku prstu . Sdílený přístup - V rámci rodinného nebo firemního použití lze udělit

přístup více důvěryhodným osobám bez nutnosti sdílet PIN kód.

### 3.3.2 Šifrování

K ochraně samotné databáze hesel ve flash paměti byla použita symetrická kryptografie AES-128. Použití vybraného kontroléru v tomto ohledu přínáší významnou výhodu ve formě hardwarové akcelerace kryptografických funkcí. Díky tomu šifrování a dešifrování nezatěžuje hlavní procesor a je sníženo riziko úniku či ztráty citlivých dat přes postranní kanály (side-channel attacks). Klíč pro šifrování je uložen v paměti eFuse, která je dedikovaná k ukládání šifrovacích klíčů.

### 3.3.3 Distribuce a správa bezpečnostního klíče

Vzhledem k implementaci symetrického šifrování je zapotřebí přenést symetrický šifrovací klíč mezi aplikací a zařízením. Přenos klíče probíhá při prvotní inicializaci zařízení. Níže je popsán celý proces od generování symetrického klíče až po jeho přenos do zařízení.

Generování šifrovacího klíče

Celý proces začíná v terminálu počítače. Uživatel si vygeneruje symetrický klíč, který si uloží do svého počítače. Pro generování lze využít například program openssl a příkaz openssl rand 128 > symkeyfile.key.

34

# | 3.4. Řídící algoritmus

Načtení klíče do aplikace a jeho přenos

Při každém spuštění aplikace je klíč nahrán z uživatelského počítače do proměnné secretKey v aplikaci. V rámci prvotní inicializace zařízení je klíč přenesen do zařízení, kde je následně uložen do dedikované paměti eFuse. V tuto chvíli disponují obě strany stejným klíčem a komunikace může probíhat šifrovaně.

Tabulka 3.1: Placeholder Caption

Fáze | Entita | Akce
Generování Terminál (PC) | Vygenerování Ks (Secret Key) a
| | uložení na disk.
Inicializace | Aplikace → Zařízení Jednorázový export klíče do paměti
| | zařízení.
Provoz | Zařízení | Trvalé uložení v bezpečné oblasti
| | paměti.
Runtime | Obě strany | Použití klíče pro šifrování relace (AES-GCM/CBC).

### 3.4 Řídící algoritmus

Hlavní řídící logika programu je strukturována jako stavový automat (FSM). Tato implementace zajišťuje deterministické chování a zaručuje, že se zařízení nedostane do nedefinovaného stavu. Přechody mezi jednotlivými stavy jsou iniciovány na základě stavu ovládacího prvku, rotačního enkodéru. Díky stavovému automatu je možné snáze rozšířit chování v případě potřeby o další stav.

Po úspěšné autentizaci uživatele přivítá hlavní nabídka. Hlavní menu slouží jako rozcestník stavového automatu, na základě kterého zařízení přechází do následujících operačních režimů:
. Database - Zobrazí databázi hesel uložených na zařízení.

Obrázek 3.4: UI: Database
. Connect to App - Po úspěšné inicializaci relace s aplikací se přepne

do režimu slave a naslouchá instrukcím z aplikace.

35

# 3. Firmware |

Obrázek 3.5: UI: Connect to Device . Save Database - Uloží aktuální stav databáze do paměti zařízení.

Obrázek 3.6: UI: Save Database . Delete Database - Vymaže databázi z paměti zařízení.

Obrázek 3.7: UI: Delete Database . Device Info - Zobrazí základní informace o zařízení a jeho verzi.

Celou logiku programu lze vidět na obrázku 3.9.

### 3.5 Optimalizace a specifická řešení???

36

| 3.5. Optimalizace a specifická řešení???

Obrázek 3.8: UI: Device Info

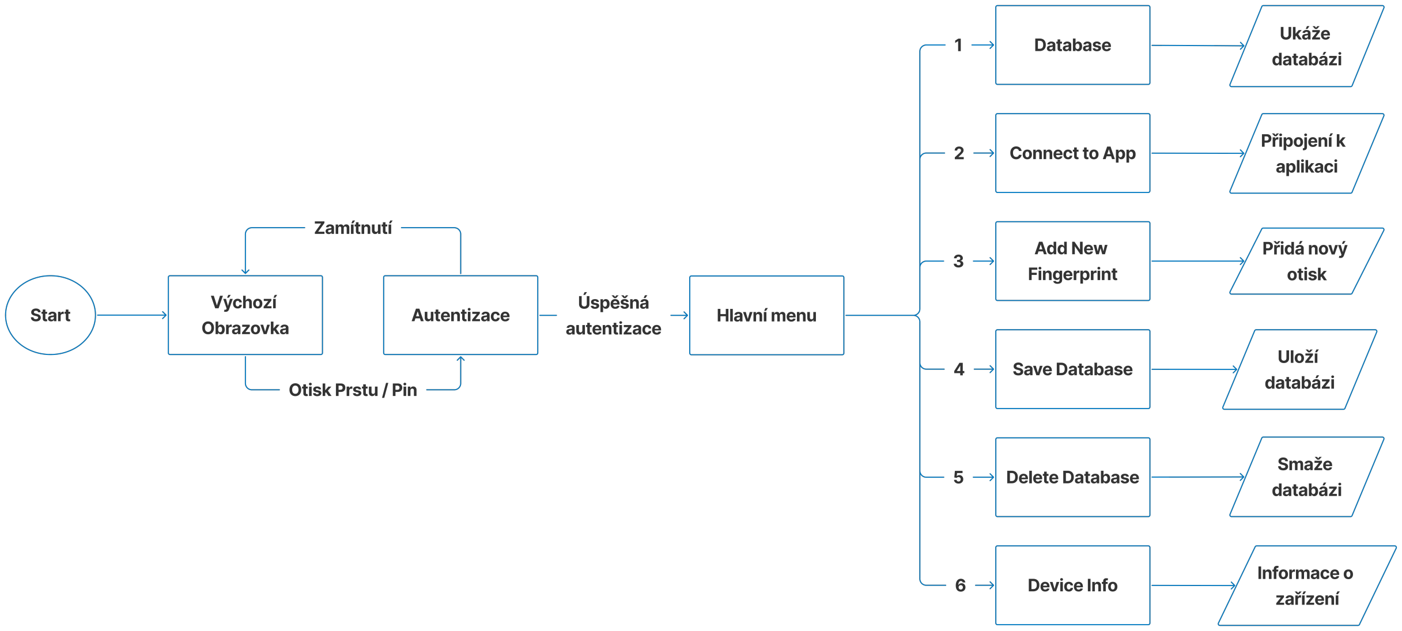
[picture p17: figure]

Obrázek 3.9: Diagram logiky firmwaru

37

38

## Kapitola 4

## Desktopová aplikace

Tato kapitola se zabývá vývojem desktopové aplikace, která slouží jako rozhraní mezi zařízením a uživatelem. Jejím hlavním účelem je zprostředkovat bezpečnou komunikaci se zařízením a umožnit správu uložených dat na zařízení.

Před samotným návrhem byly definovány základní pilíře, na kterých byl postaven vývoj aplikace. Jedná se o následující body:
. Bezpečnost - Komunikace mezi zařízením a aplikací musí být šifrovaná.

. Jednoduchost - Aplikace by měla být přehledná a jednoduchá na použí-

vání.
. Kompatibilita - Program je přenosný na operační systémy MacOS, Linux

a Windows.

Aplikace byla implementována v jazyce Python s využitím frameworku PySide6. Cílovou platformou je operační systém MacOS (Tahoe 26.2), na kterém byla aplikace vyvíjena.

### 4.1 Architektura a datový model

Aplikace je postavena na monolitické architektuře bez separace do vrstev. Řešení uživatelského rozhraní, logiky aplikace, vstupy a výstupy jsou převážně řešeny v jedné třídě MainWindow v hlavním souboru app.py. Na obrázku 4.1 je znázorněna struktura projektu pro aplikaci.
Jak lze vidět na obrázku struktury, aplikace se skládá ze dvou skriptů: hlavního app.py, který řeší veškerou vizuální a funkční stránku aplikace, kromě šifrování, kdy encryption.py zajišťuje veškerou problematiku týkající se kryptografie.

Datový model pro ukládání bezpečnostních údajů z připojeného zařízení je řešen za pomocí tří paralelních seznamů (entryID, entryUSRNAME, entryPSW). Zobrazení je realizováno třemi widgety QListWidget, které korespondují s

39

# 4. Desktopová aplikace |

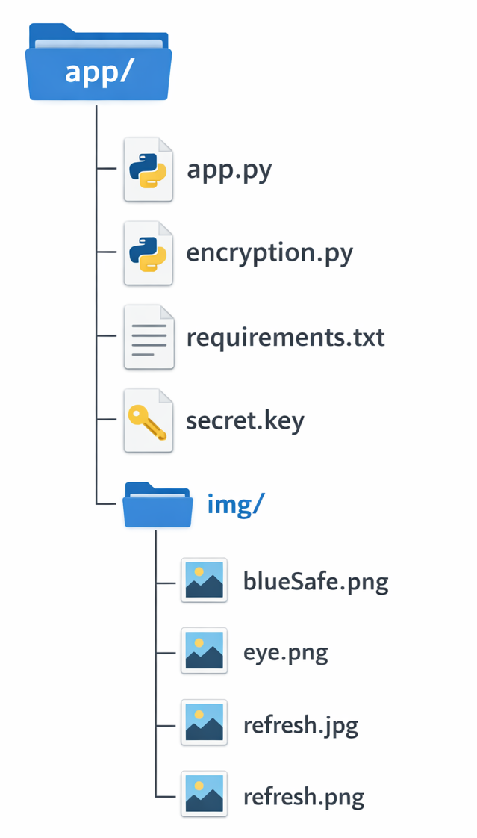
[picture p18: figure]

Obrázek 4.1: Strktura aplikace

názvy seznamů, tedy ID, username a password. Synchronizace je indexová, tj. položky jsou svázány stejnou pozicí v jednotlivých seznamech. Tento přístup je jednoduchý a odpadá nutnost vytvářet externí databázi; je však citlivý na desynchronizaci při chybných operacích. Před nahráním jednotlivých seznamů do zařízení je databáze přeindexována počínaje ID = 1 až ID = DBlen, aby indexy korespondovaly s indexy v zařízení.

Informace o připojeném zařízení jsou ukládány ve formě stringu(deviceName, fwVersion, hwVersion, serialNumber). Údaje jsou následně zobrazovány ve widgetu s informacemi o připojeném zařízení.

### 4.2 Kybernetická bezpečnost

Přenos citlivých uživatelských dat je šifrován pomocí AES-128 v režimu CBC se samostatným IV (16 B). IV je prependovaný k šifrovanému textu a výsledek je ve formátu Base64. Šifrování je detailně popsáno v sekci 1.5 teoretické části.
Vzhledem k principu použité komunikace se dešifrování provádi při načítání databáze ze zařízení; v opačném případě aplikace provádí šifrování. Pro

40

# | 4.3. Uživatelské rozhraní

vytvoření obou funkcí byl použit modul Crypto.Cipher, ze kterého bylo importováno AES. Implementaci funkcí pro zašifrování a dešifrování lze najít ve skriptu encryption.py.

### 4.3 Uživatelské rozhraní

Jak již bylo zmíněno v úvodu této kapitoly, k vytvoření aplikace byl použit framework PySide6, díky kterému je možné vytvořit uživatelsky přívětivé rozhraní.

Hlavní okno je v aktuální verzi fixováno na velikost 1050 x 520 pixelů a je rozděleno do tří hlavních bloků:

### 4.3.1 Connection tab

První sekcí uživatelského rozhraní je connection tab, který slouží k obsluze připojení zařízení k aplikaci pomocí COM portu. Uživatel má k dispozici seznam dostupných portů. Pokud je aplikace spuštěna dříve, než je fyzicky připojeno externí zařízení, je možné pomocí tlačítka Search COMs znovu vyhledat nově dostupné porty, které se objeví na konci seznamu. Pro připojení a odpojení slouží tlačítko Connect, resp. Disconnect. Baud rate pro komunikaci je nastaven na 115200 Bd. Posledním elementem je tlačítko s ikonou oka, které slouží pro zakrytí nebo odkrytí hesel v databázi.

(a) : Připojovací sekce - nepřipojené zařízení
(b) : Připojovací sekce - připojené zařízení

Obrázek 4.2: Připojovací sekce aplikace

### 4.3.2 Databáze

Hlavním prvkem celé aplikace je samotná databáze, která zabírá většinu okna. Databáze je v aplikaci uložena, jak již bylo zmíněno v sekci 4.1, do tří seznamů: id, username, password. Pro každý seznam je v aplikaci samostatný widget, jehož název koresponduje s názvy seznamů. Stejně jako databáze je řazena podle ID, je i zobrazení řazeno vzestupně od nejmenšího dostupného ID. Identifikátor není možné libovolně přepisovat.

### 4.3.3 Database tools tab

Poslední sekcí aplikace jsou dostupné uživatelské nástroje pro správu databáze. Widget Device information zobrazuje načtené informace o připojeném

41

# 4. Desktopová aplikace |

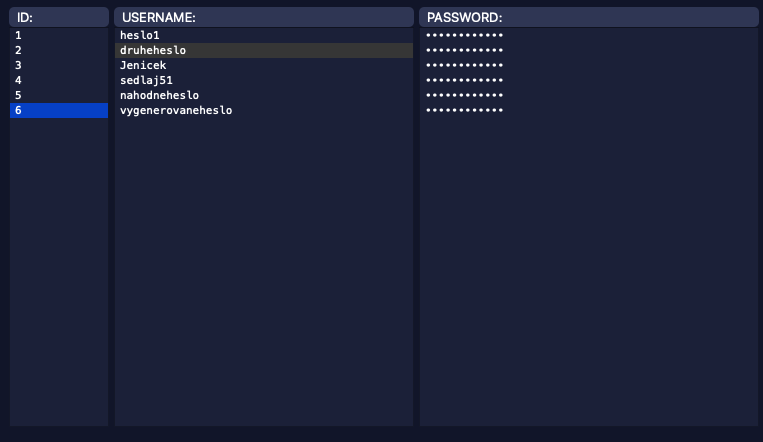
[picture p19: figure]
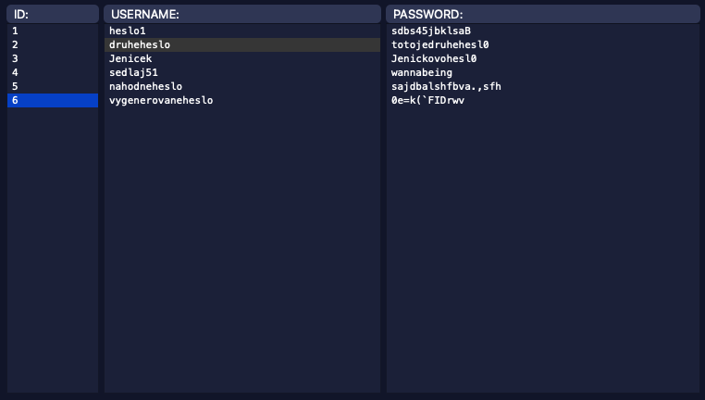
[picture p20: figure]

(a) : Odkrytá hesla | (b) : Skrytá hesla

Obrázek 4.3: Databáze hesel

zařízení, které jsou přenášeny při inicializaci spojení se zařízením. Jedná se o informace, jako jsou název zařízení, verze firmwaru a hardwaru, jeho sériové číslo a status připojení - connected/disconnected. V případě potřeby lze informace o zařízení aktualizovat pomocí příslušného tlačítka se šipkami.

V sekci Database jsou k dispozici následující nástroje:
. Add Entry – Slouží k přidání nového hesla do databáze.

. Load DB – Dvojklikem načte data ze zařízení do databáze v aplikaci.

. Upload DB – Slouží k nahrání upravené databáze do zařízení.

. Edit Entry – Po vybrání záznamu z databáze umožní změnit username

a password.
. Generate PSW – Generátor náhodného hesla.

Posledním widgetem je Danger Zone, který obsahuje dvě tlačítka: Delete Entry pro smazání vybraného záznamu a Delete ALL, které smaže celou databázi. Po smazání celé databáze se hesla smaží pouze v aplikaci. Nahrát je zpět do aplikace lze použitím tlačítka Load DB. Pro definitivní smazání databáze i ze zařízení je třeba nahrát prázdnou databázi nebo provést smazání přímo v zařízení.

Generate PSW

Databáze má vlastní nástroj pro generování náhodného hesla, který je nastaven dle zásad pro generování neprolomitelného hesla, viz sekce 1.1. Po kliknutí je uživatel vyzván k zadání délky generovaného hesla, poté nástroj heslo vygeneruje a v rámci pop-up zprávy zobrazí výsledek. Uživatel má možnost heslo zkopírovat do schránky nebo vygenerovat nové.

42

# | 4.3. Uživatelské rozhraní

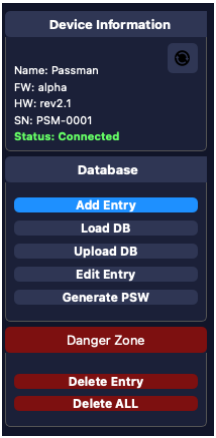
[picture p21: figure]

Obrázek 4.4: Nástroje

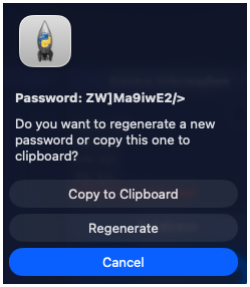
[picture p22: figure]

Obrázek 4.5: Funkce generování hesla

43

# 4. Desktopová aplikace |

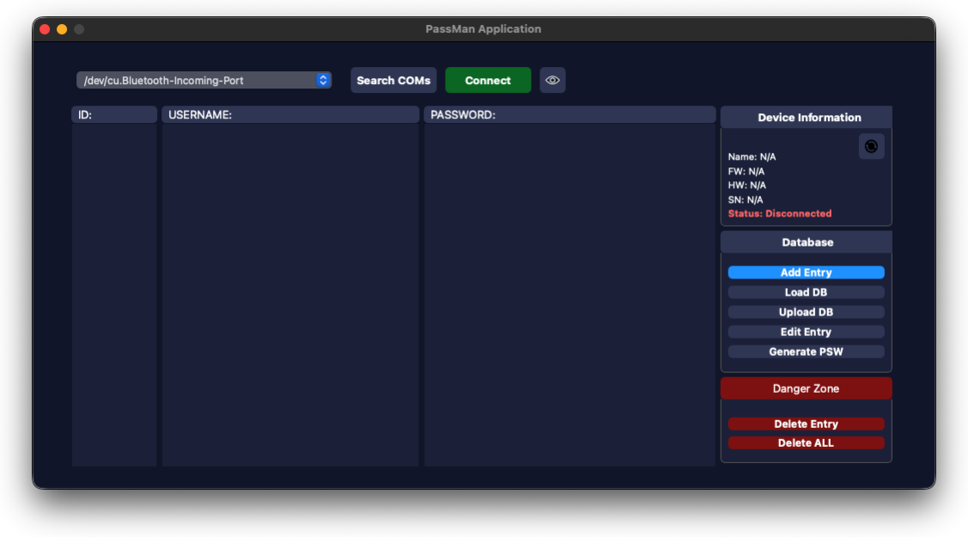
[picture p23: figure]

Obrázek 4.6: Uživatelské rozhraní aplikace

44

## Kapitola 5

## Ověření funkčnosti

45

46

## Kapitola 6

## Závěr

47

48

## Zkratky

AES Advanced Encryption Standard. 9

ECC Error Checking and Correcting. 9

FAR False Acceptance Rate. 27

FSM Finite State Machine. 35

HSM Hardware Security Module. viii, 9, 10

I2C Inter-Integrated Circuit. 27

IoT Internet of Things. 12, 16

LDO Low Dropout Regulator. 24, 25

MFA Multi-Factor Authentication. 5

MMU Memory Management Unit. 12

MPU Memory Protection Unit. 12

OOP Object-Oriented Programming. 31

OTA Over the Air. 12

PCB Printed Circuit Board. 25, 29, 30

ROM Read-Only Memory. 9

RoT Root of Trust. 9

RSA Rivest–Shamir–Adleman. 9

SoC System on Chip. 11

TEE Trusted Execution Environment. viii, 10, 11

49

# 6. Závěr |

TOTP Time-based One-Time Password. 5

TPM Trusted Platform Module. viii, 9, 10

UART Universal Asynchronous Receiver-Transmitter. 27

USB Universal Serial Bus. 22, 23, 29

UX User Experience. 6

50

## Literatura

[1] How secure is my password?
[2] Ross Anderson. Security Engineering: A Guide to Building Dependable Distributed Systems. John Wiley & Sons, 3rd edition, 2020.
[3] Yifeng Cao, Ashutosh Dhekne, and Mostafa Ammar. Uwb-auth: A uwb-based two factor authentication platform. In Proceedings of the 17th ACM Conference on Security and Privacy in Wireless and Mobile Networks (WiSec ’24), pages 27–38. ACM, 2024.
[4] David Challener, Kent Yoder, Ryan Catherman, David Safford, and Leendert Van Doorn. A Practical Guide to Trusted Computing. IBM Press, 2008. Detailní rozbor TPM architektury.
[5] David Cooper, William Polk, Andrew Regenscheid, and Murugiah Souppaya. Bios integrity measurement guidelines. Technical Report NIST SP 800-147, National Institute of Standards and Technology (NIST), 2011.
[6] Paul A Grassi, Michael E Garcia, and James L Fenton. Digital identity guidelines: Authentication and lifecycle management. Technical Report Special Publication (SP) 800-63B, National Institute of Standards and Technology (NIST), 2017.
[7] Joshua Gray, Virginia NL Franqueira, and Yijun Yu. Forensicallysound analysis of security risks of using local password managers. In 2016 IEEE 24th International Requirements Engineering Conference Workshops (REW), pages 114–121. IEEE, 2016.
[8] Anil K Jain, Karthik Nandakumar, and Arun Ross. 50 years of biometric research: Accomplishments, challenges, and opportunities. Pattern Recognition Letters, 79:80–105, 2016.
[9] JetBrains. Working with STM32 ARM TrustZone in CLion. JetBrains Blog, March 2026. [Online; navštíveno 10. 4. 2026].
[10] Praveen Joshi. Common attacks on embedded systems and how to prevent them.

51

# 6. Závěr |

[11] David Kleidermacher and Mark Kleidermacher. Embedded Systems Security: Practical Methods for Safe and Secure Software and Communication Development. Elsevier Science, Amsterdam, 2012.
[12] Davide Maltoni, Dario Maio, Anil K Jain, and Salil Prabhakar. Handbook of Fingerprint Recognition. Springer Science & Business Media, 2nd edition, 2009.
[13] National Institute of Standards and Technology. Digital identity guidelines: Authentication and lifecycle management. Technical report, NIST Special Publication 800-63B, Gaithersburg, MD, 2017.
[14] National Institute of Standards and Technology. Fips pub 140-3: Security requirements for cryptographic modules. Technical report, U.S. Department of Commerce, 2019. Standard pro ochranu klíčů v HSM.
[15] Sandro Pinto and Nuno Oliveira. Demystifying arm trustzone: A comprehensive survey. ACM Computing Surveys (CSUR), 51(6):1–36, 2019.
[16] Ariel Piper. Unbreakable passwords hackers can’t crack.
[17] Srivaths Ravi, Anand Raghunathan, Paul Kocher, and Sunil Hattangady. Security in embedded systems: Design challenges. In ACM Transactions on Embedded Computing Systems (TECS), volume 3, pages 461–491. ACM, 2004.
[18] Bruce Schneier. Applied Cryptography: Protocols, Algorithms, and Source Code in C. John Wiley & Sons, 20th anniversary edition edition, 2015.
[19] Abraham Silberschatz, Peter B. Galvin, and Greg Gagne. Operating System Concepts. John Wiley & Sons, 10th edition, 2018. Teoretický základ pro MMU a virtuální paměť.
[20] William Stallings. Cryptography and Network Security: Principles and Practice. Pearson, 7th edition, 2017.
[21] William Stallings and Lawrie Brown. Computer Security: Principles and Practice. Pearson, 4th edition, 2018. Kapitoly zaměřené na Hardware Security a Trusted Computing.
[22] Stephan Electronics. Tindie: Mooltipass mini ble authenticator, 2024. Online; citováno 2024-05-01.
[23] Joseph Yiu. The Definitive Guide to ARM Cortex-M3 and Cortex-M4 Processors. Newnes, 3rd edition, 2013. Klíčový zdroj pro pochopení mechanismů MPU u ARM procesorů.

52

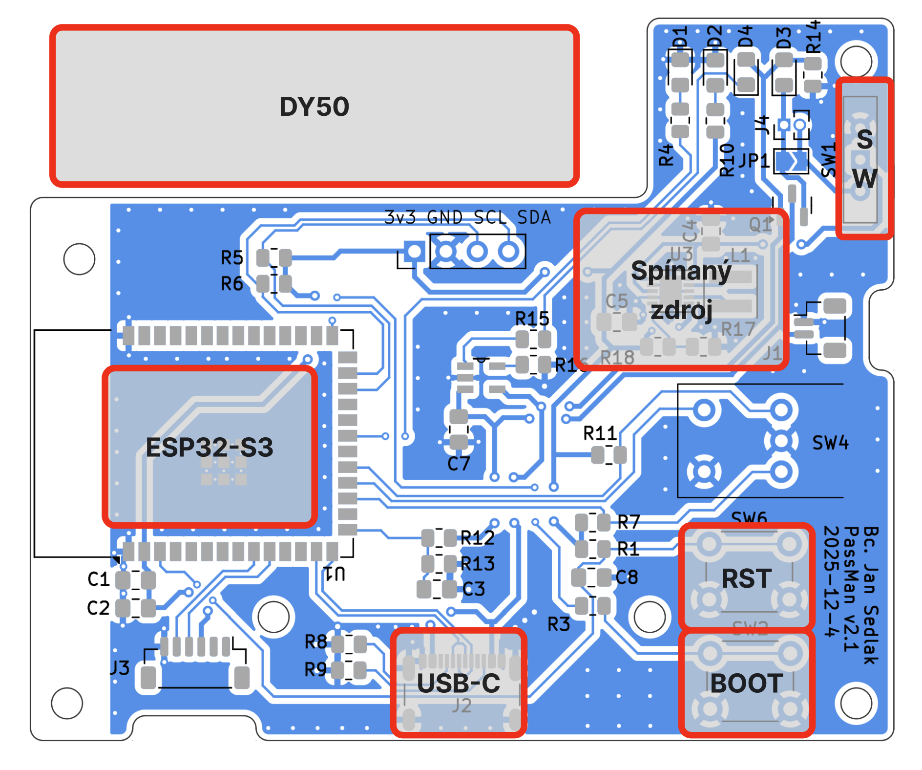
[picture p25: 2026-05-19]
_docs/layout_v2.png

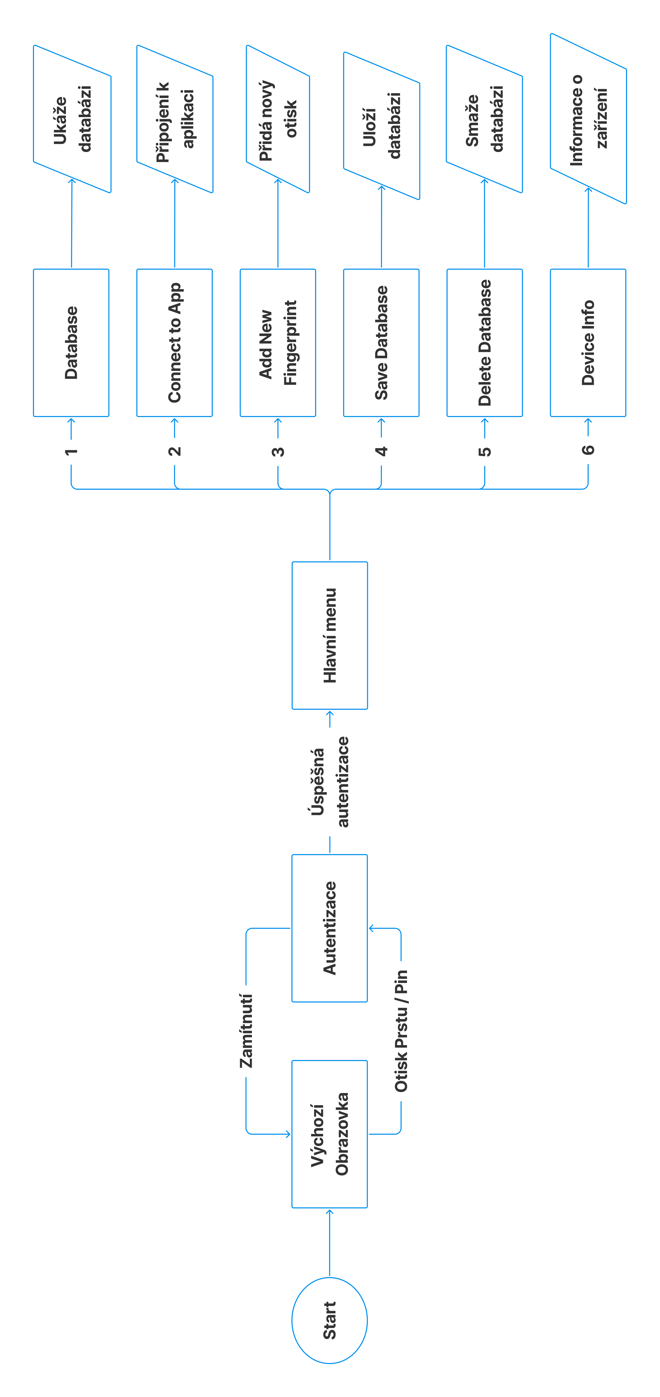
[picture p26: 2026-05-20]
_docs/fw_diagram_extra_bold.png

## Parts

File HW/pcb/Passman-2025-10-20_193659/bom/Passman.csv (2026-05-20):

Id | Designator | Footprint | Quantity | Designation | Supplier and ref
1 | J1 | JST_SH_BM02B-SRSS-TB_1x02-1MP_P1.00mm_Vertical | 1 | Conn_01x02_Pin
2 | SW2 | SW_PUSH_6mm_H5mm | 1 | SW_Boot
3 | R1,R11,R7 | R_0805_2012Metric | 3 | 10k
4 | C1 | C_0805_2012Metric_Pad1.18x1.45mm_HandSolder | 1 | 22uf
5 | D4 | LED_0805_2012Metric_Pad1.15x1.40mm_HandSolder | 1 | LED_Red
6 | SW6 | SW_PUSH_6mm_H5mm | 1 | SW_Reset
7 | D2 | LED_0805_2012Metric_Pad1.15x1.40mm_HandSolder | 1 | LED_Green
8 | R4 | R_0805_2012Metric | 1 | 12R
9 | L1 | L_Coilcraft_XxL4020 | 1 | 2.2uH
10 | R3 | R_0805_2012Metric | 1 | 100R
11 | JP1 | SolderJumper-2_P1.3mm_Open_TrianglePad1.0x1.5mm | 1 | Jumper_2_Bridged
12 | R17 | R_0805_2012Metric | 1 | 100k
13 | C8,C2,C3 | C_0805_2012Metric_Pad1.18x1.45mm_HandSolder | 3 | 100nf
14 | R18 | R_0805_2012Metric | 1 | 560k
15 | C5 | C_0805_2012Metric_Pad1.18x1.45mm_HandSolder | 1 | 22uF
16 | SW1 | SW_Slide-03_Wuerth-WS-SLTV_10x2.5x6.4_P2.54mm | 1 | SW_Wuerth_450301014042
17 | J3 | JST_SH_BM06B-SRSS-TB_1x06-1MP_P1.00mm_Vertical | 1 | Conn_01x06_Pin
18 | R6,R5 | R_0805_2012Metric | 2 | 4k7
19 | Q1 | SOT-23 | 1 | AO3401A
20 | R15,R14 | R_0805_2012Metric | 2 | 1k
21 | R12,R13 | R_0805_2012Metric | 2 | 1M
22 | SW4 | RotaryEncoder_Bourns_Horizontal_PEC09-2xxxF-Sxxxx | 1 | RotaryEncoder_Switch
23 | U2 | SOT95P280X145-5N | 1 | MCP73831T-2ACI/OT
24 | D3 | D_0805_2012Metric_Pad1.15x1.40mm_HandSolder | 1 | D_Schottky
25 | D1 | LED_0805_2012Metric_Pad1.15x1.40mm_HandSolder | 1 | LED_Blue
26 | R16 | R_0805_2012Metric | 1 | 4.7k
27 | J2 | USB_C_Receptacle_GCT_USB4105-xx-A_16P_TopMnt_Horizontal | 1 | USB_C_Receptacle_USB2.0_16P
28 | U1 | ESP32-S3-WROOM-1 | 1 | ESP32-S3-WROOM-1
29 | R8,R9 | R_0805_2012Metric | 2 | 5.1k
30 | J4 | PinHeader_1x02_P1.27mm_Vertical | 1 | Conn_01x02_Pin
31 | 128x64_OLED_pins2 | PinHeader_1x04_P2.54mm_Vertical | 1 | ~
32 | R10 | R_0805_2012Metric | 1 | 44R
33 | U3 | SON_B1-APUR_STM | 1 | STBB1-APUR
34 | C4 | C_0805_2012Metric_Pad1.18x1.45mm_HandSolder | 1 | 10uF
35 | C7 | C_0805_2012Metric_Pad1.18x1.45mm_HandSolder | 1 | 10uf

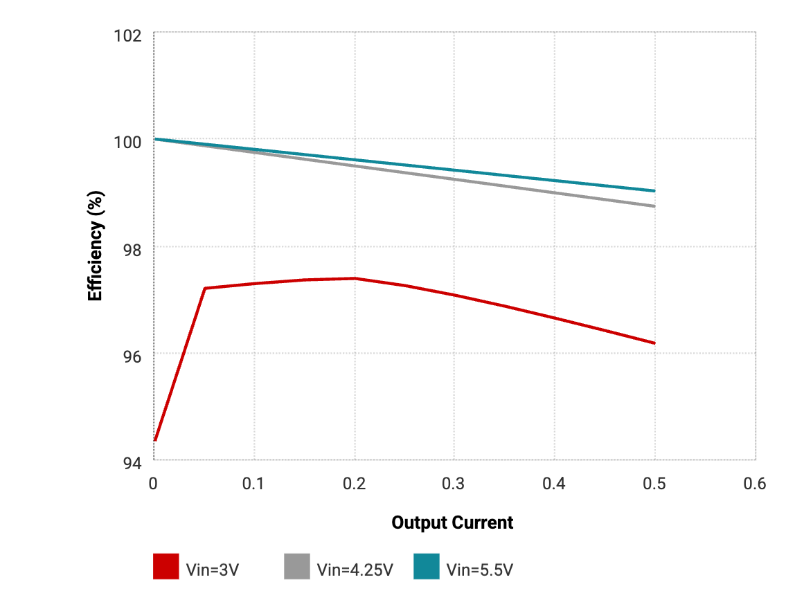
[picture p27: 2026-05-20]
HW/pcb/Components/switching_regulator/efficiency.png

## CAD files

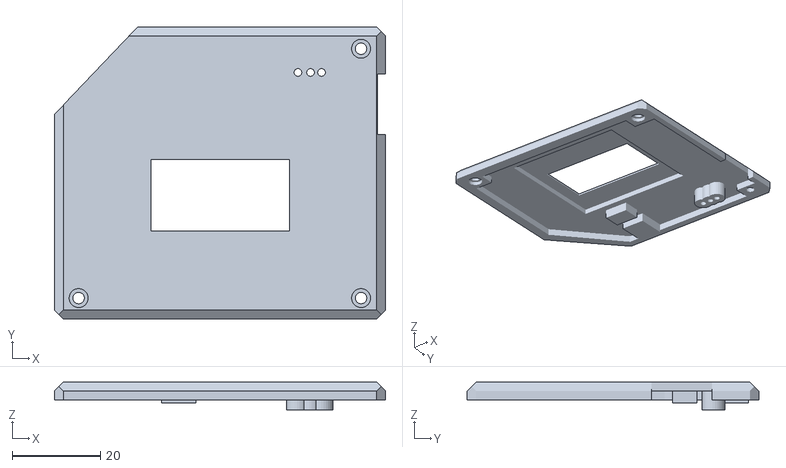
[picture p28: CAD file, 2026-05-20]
HW/Fusion/vrchni_v5.stl
75.0 x 66.1 x 6.30

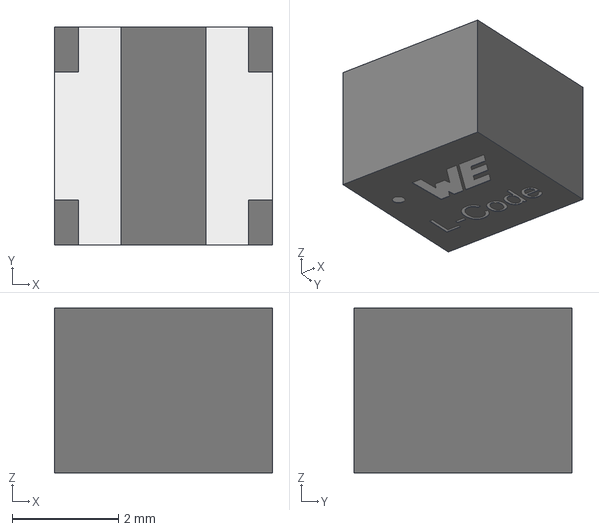
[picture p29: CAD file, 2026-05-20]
HW/pcb/Components/L_wurthE_74438357010/74438357010/WE-MAPI_4030.step
4.10 x 4.10 x 3.10 mm
body_SSMC_4030
land_pattern_SSMC_4020 x 2

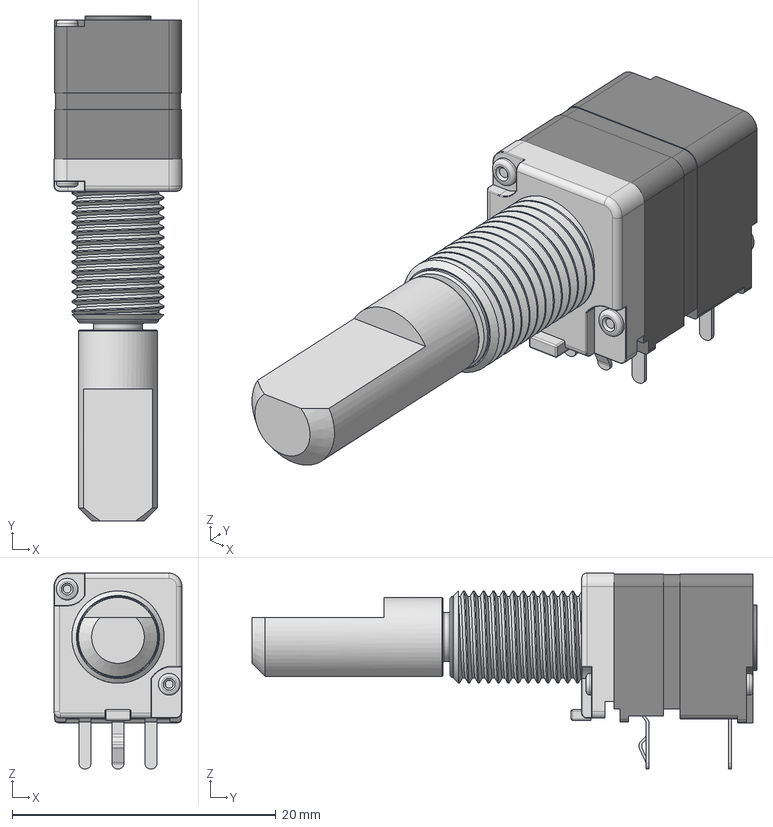
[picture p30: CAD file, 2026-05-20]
HW/pcb/Components/LIB_PEC09-2325F-S0015/PEC09-2325F-S0015/3D/PEC09-2325F-S0015.stp
9.70 x 38.3 x 14.9 mm

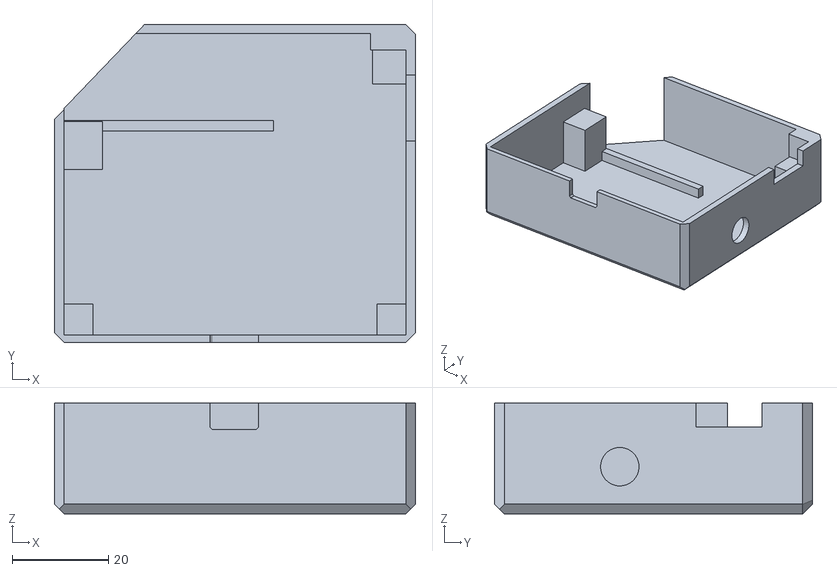
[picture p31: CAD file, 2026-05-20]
HW/Fusion/spodni_v5.stl
75.0 x 66.0 x 23.0

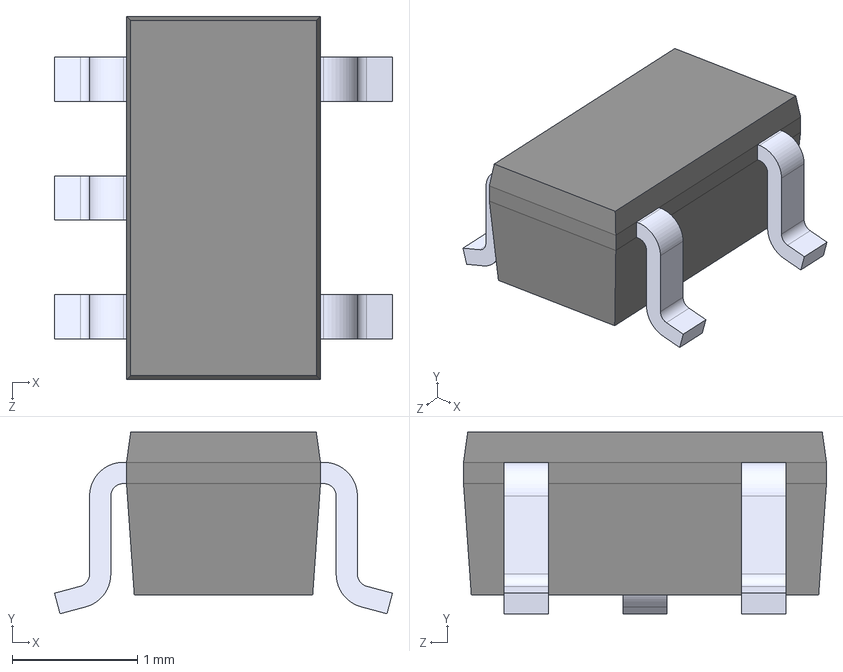
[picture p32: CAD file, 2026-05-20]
HW/pcb/Components/MCP73831T_2ACI_OT/MCP73831T-2ACI_OT.step
2.70 x 1.45 x 2.90 mm

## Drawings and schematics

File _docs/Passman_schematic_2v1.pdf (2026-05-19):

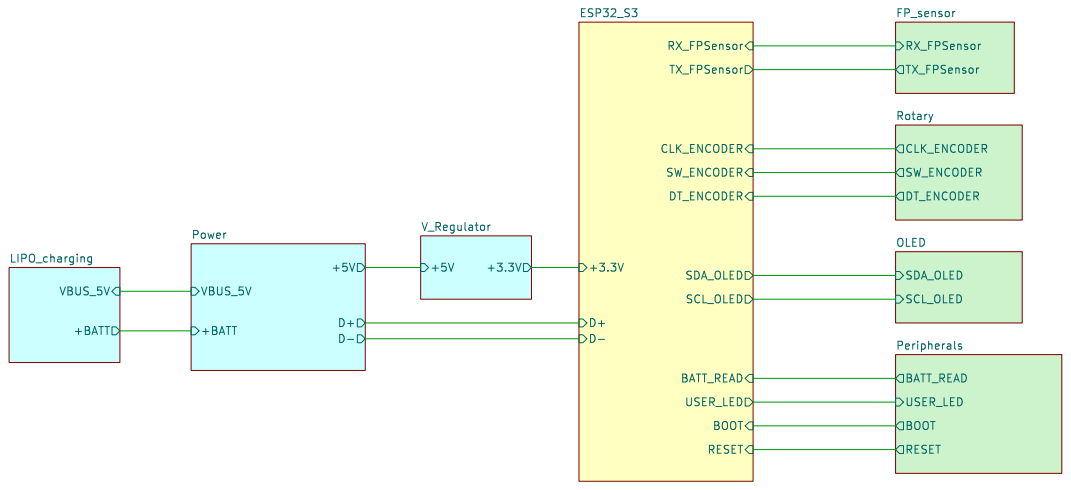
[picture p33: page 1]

File: Passman.kicad_sch Sheet: /
Id: 1/9 Title: PassMan - BLOCK DIAGRAM

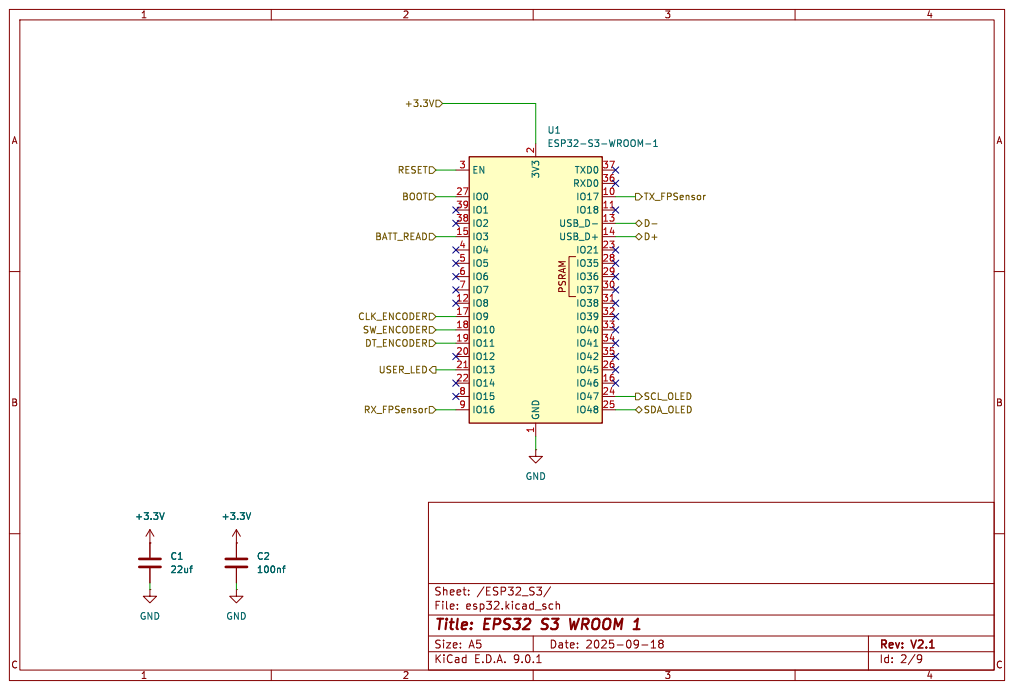
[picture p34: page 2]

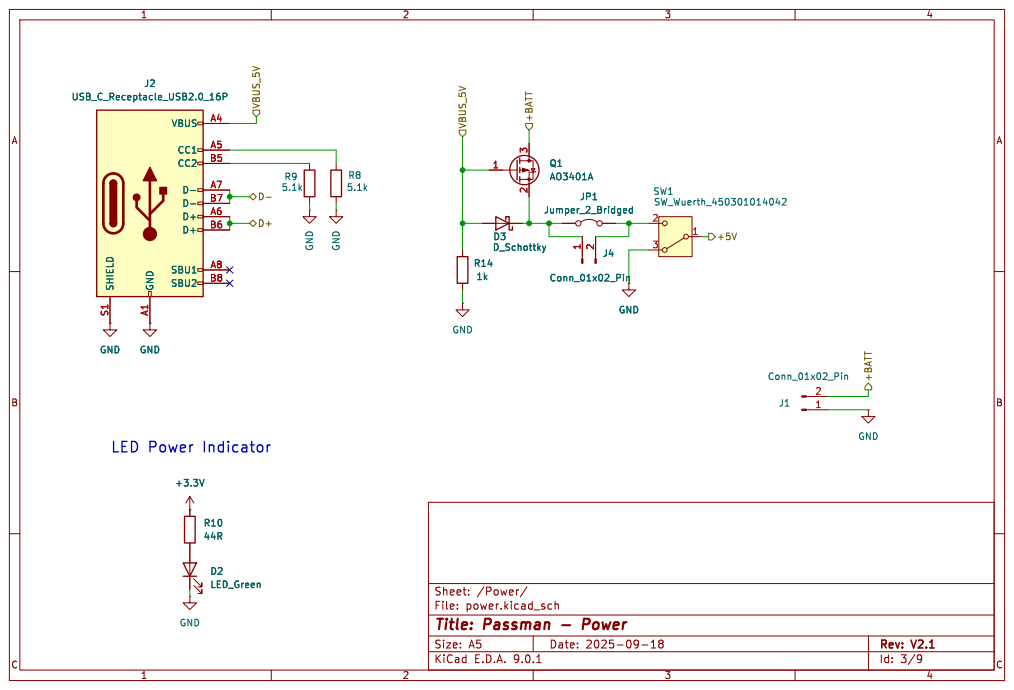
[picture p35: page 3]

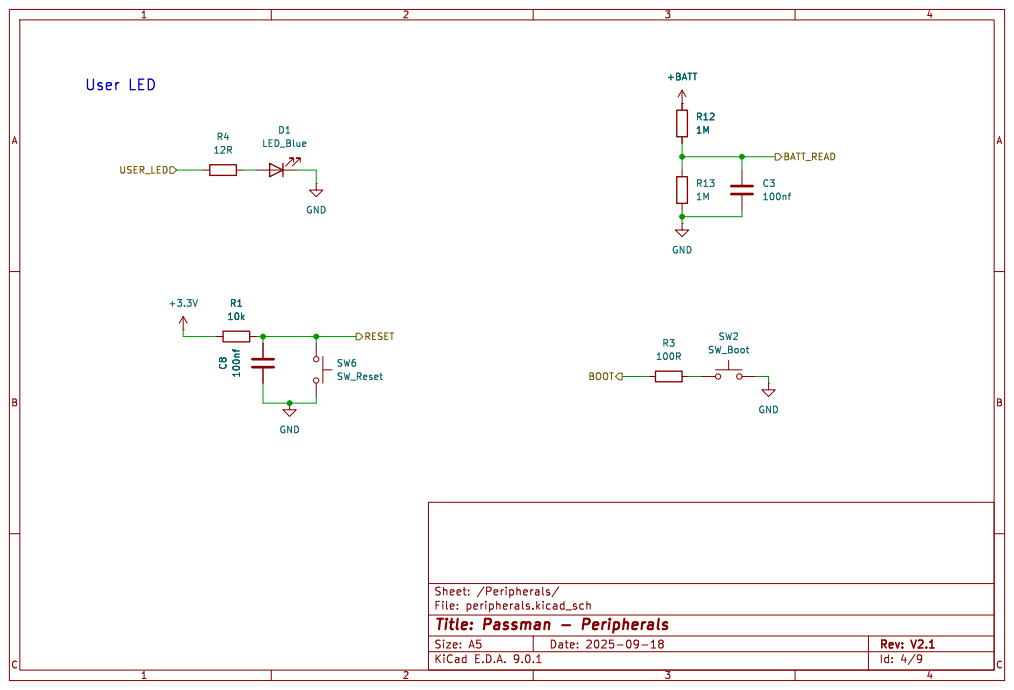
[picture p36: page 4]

BOOT RESET User LED

Id: 4/9 Title: Passman - Peripherals

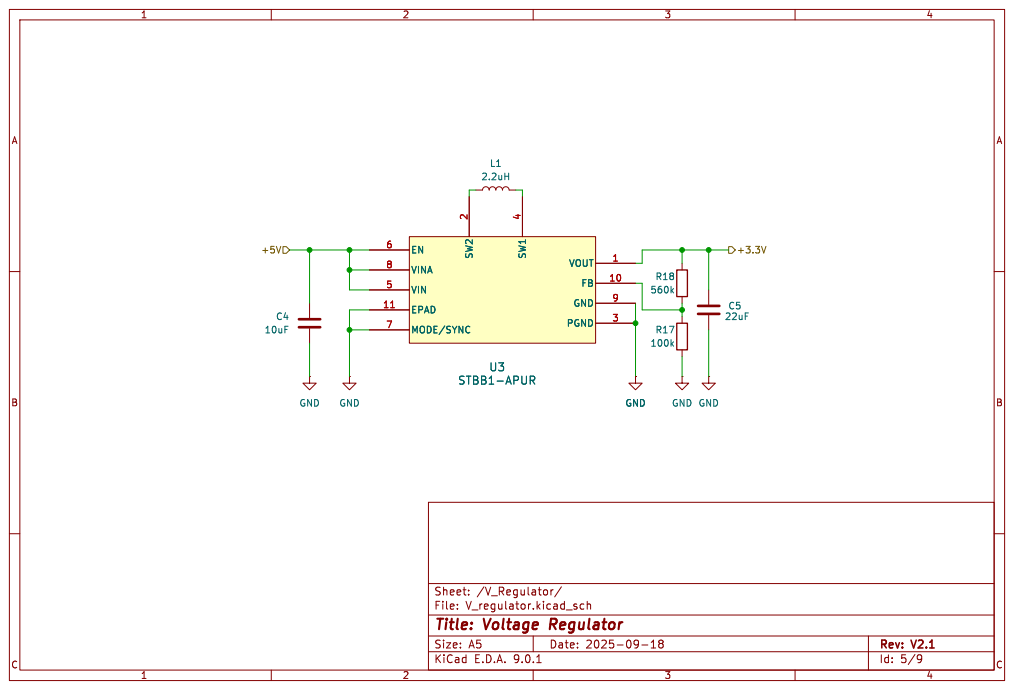
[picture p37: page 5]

2 EN 6 VINA 8 VIN 5 MODE/SYNC 7 GND 9 PGND 3 EPAD 11 U3 STBB1-APUR

2 EN 6 VINA 8 VIN 5 MODE/SYNC 7 GND 9 PGND 3 EPAD 11 GND

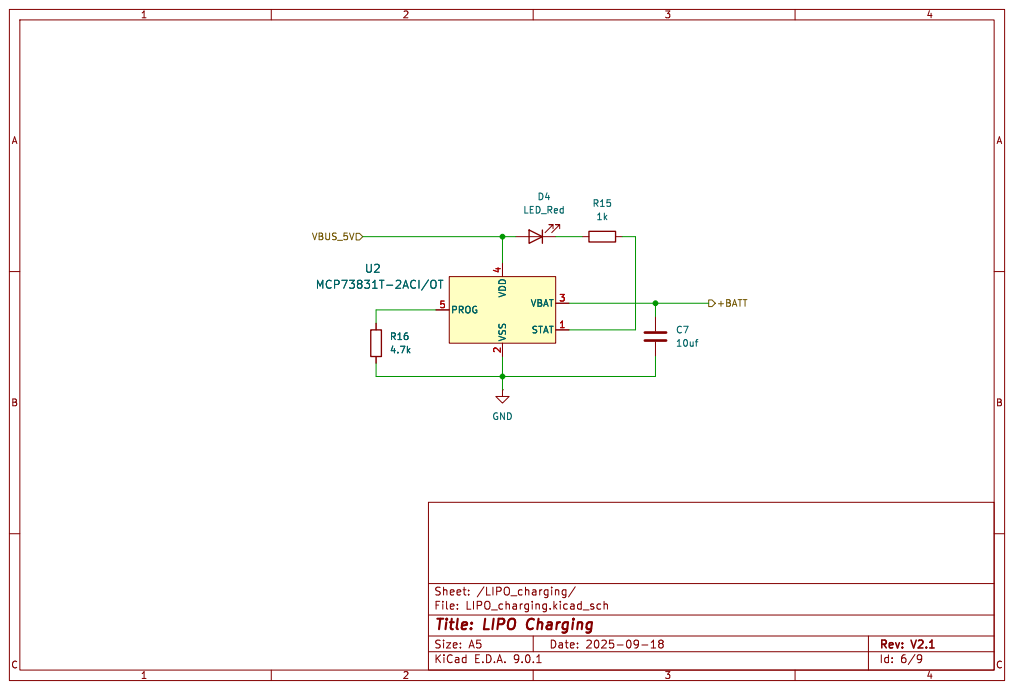
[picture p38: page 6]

Id: 6/9 Title: LIPO Charging

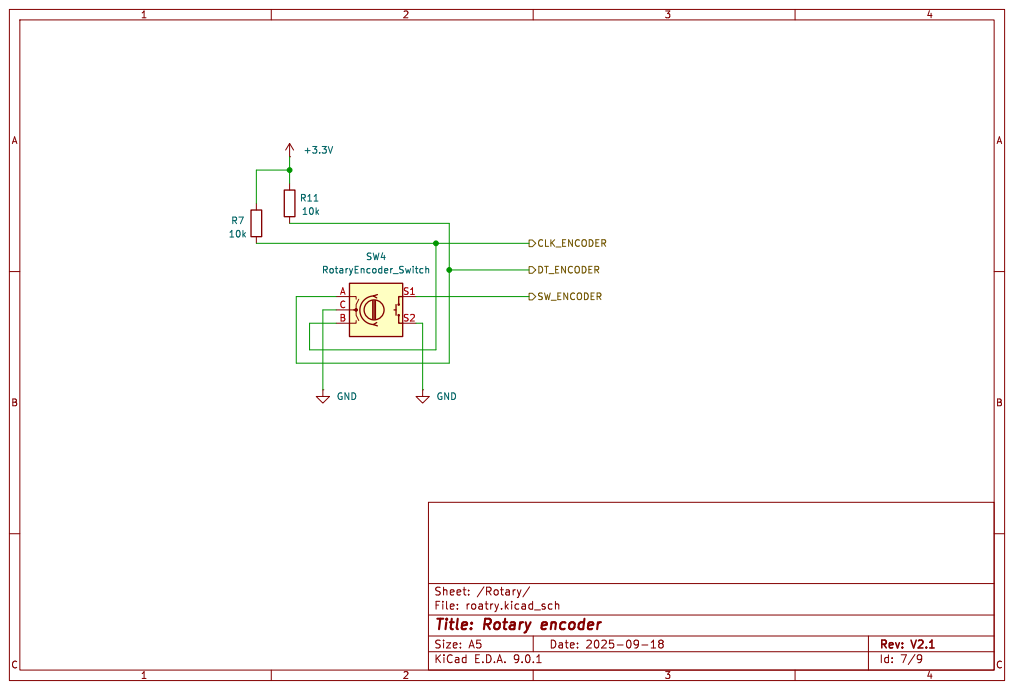
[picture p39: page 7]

Id: 7/9 Title: Rotary encoder File: roatry.kicad_sch Sheet: /Rotary/ R11

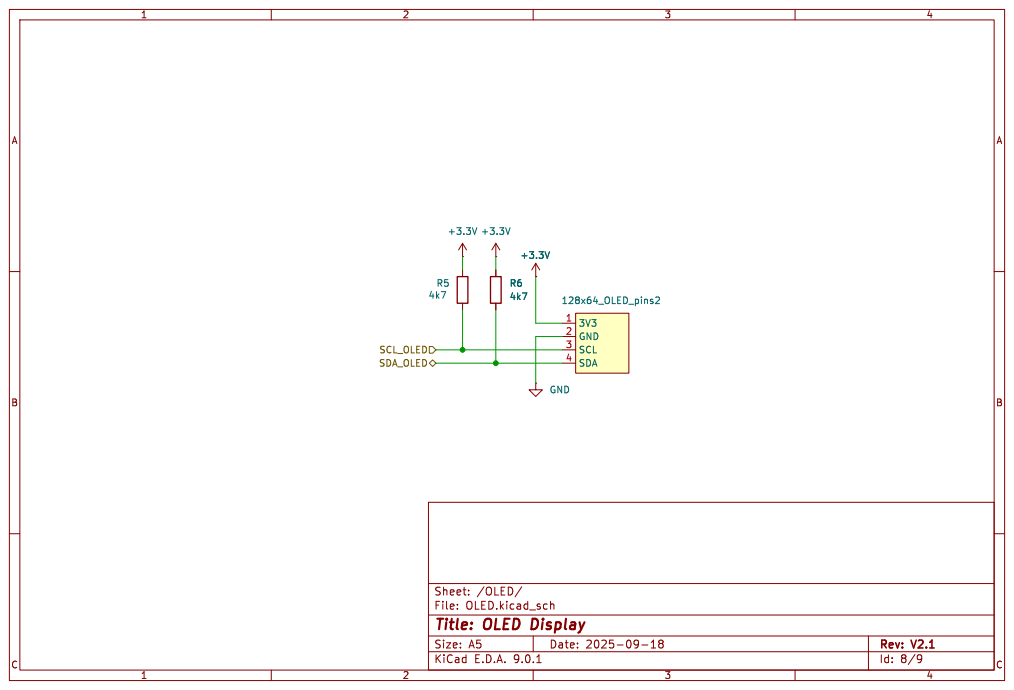
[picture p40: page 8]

File: OLED.kicad_sch Sheet: /OLED/R6

Id: 8/9 Title: OLED Display

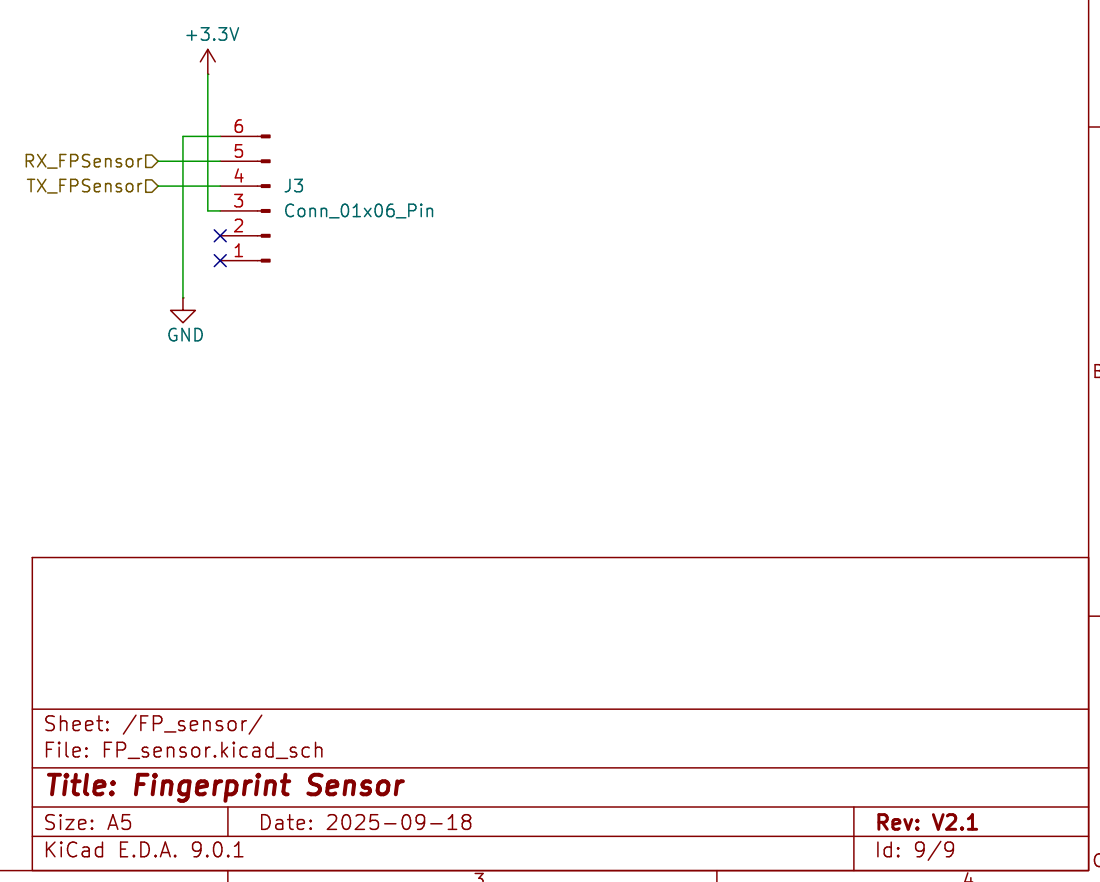
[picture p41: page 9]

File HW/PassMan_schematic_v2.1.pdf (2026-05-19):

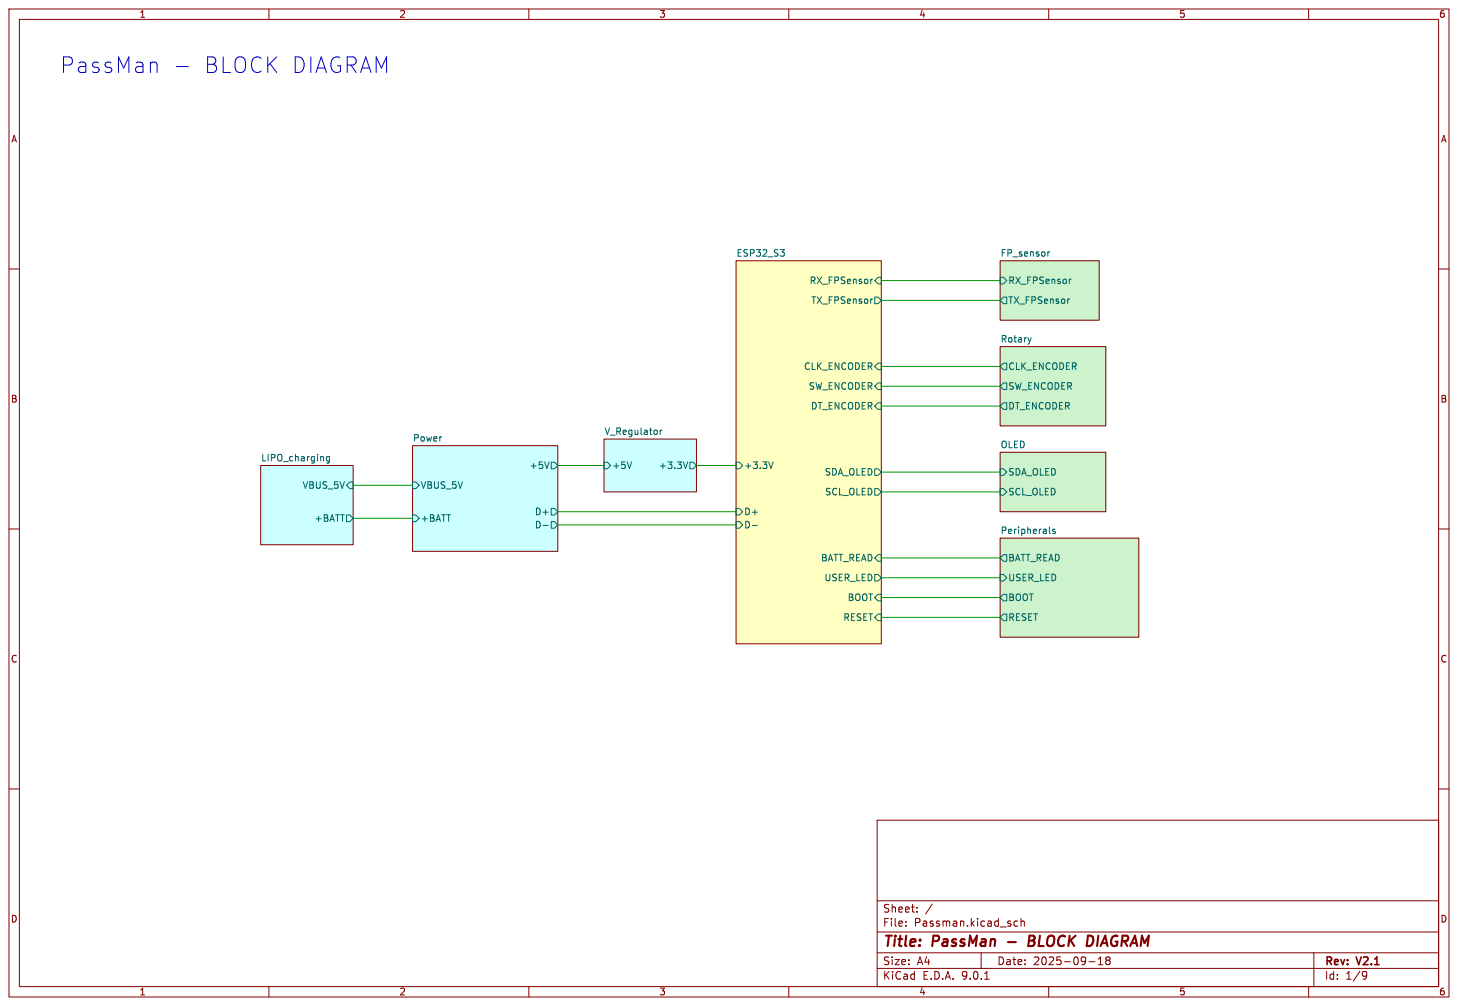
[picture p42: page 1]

Id: 1/9 Title: PassMan - BLOCK DIAGRAM

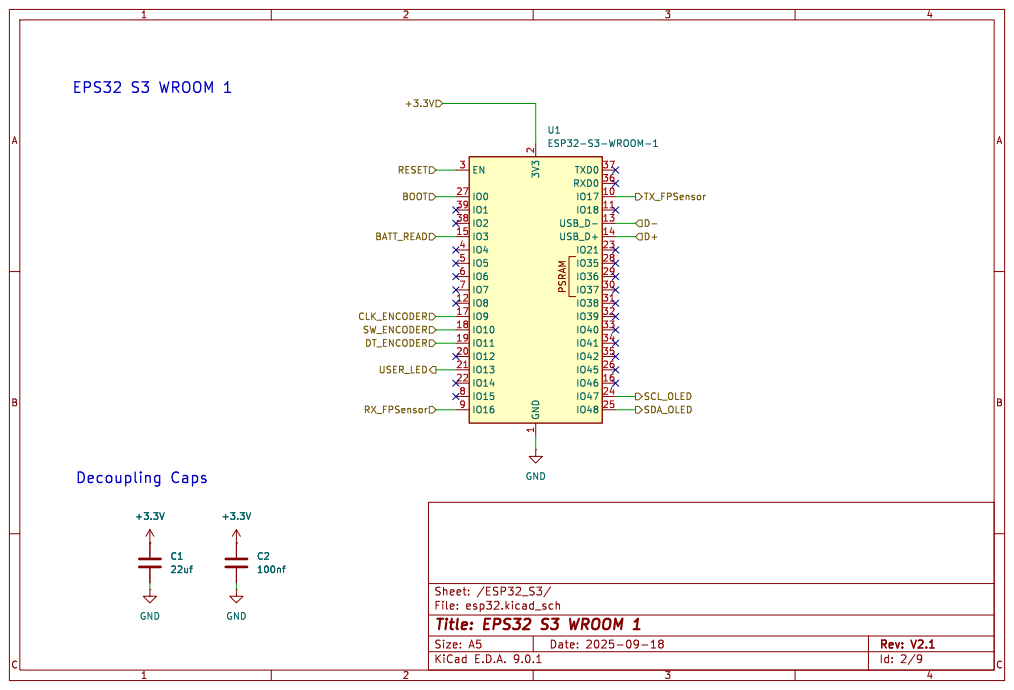
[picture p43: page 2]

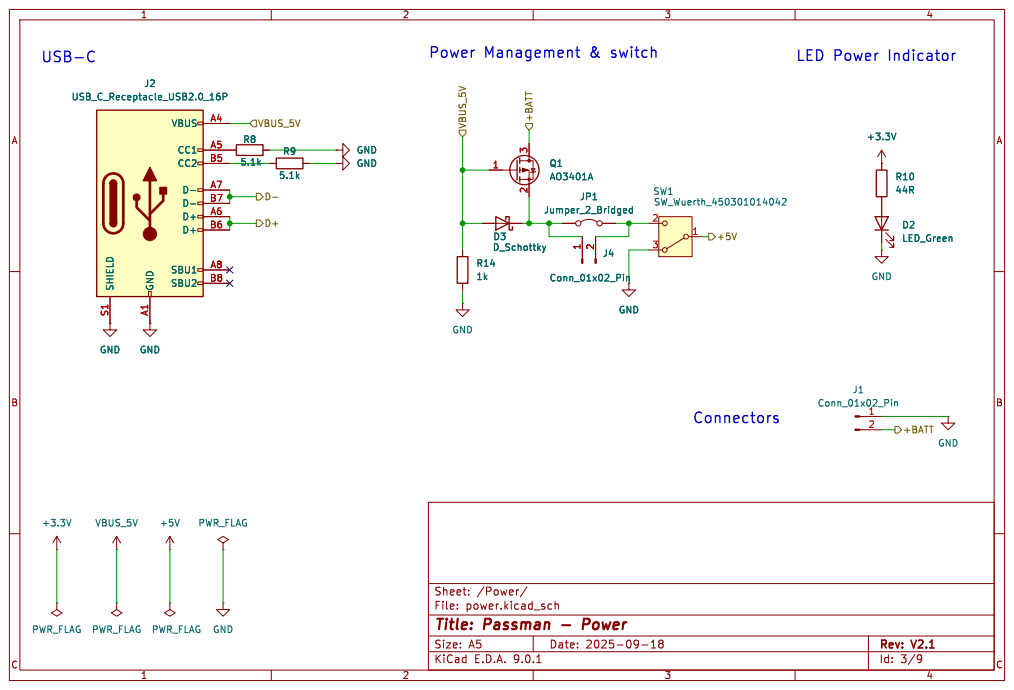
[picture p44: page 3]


Battery read User LED

Id: 4/9 Title: Passman - Peripherals


2 EN 6 VINA 8 VIN 5 MODE/SYNC 7 GND 9 PGND 3 EPAD 11 U3 STBB1-APUR

2 EN 6 VINA 8 VIN 5 MODE/SYNC 7 GND 9 PGND 3 EPAD 11 GND

Id: 5/9 Title: Voltage Regulator File: V_regulator.kicad_sch Sheet: /V_Regulator/ GND


Id: 6/9 Title: LIPO Charging


Id: 7/9 Title: Rotary encoder File: roatry.kicad_sch Sheet: /Rotary/ R7


128x64_OLED_pins2 SCL_OLED
File: OLED.kicad_sch Sheet: /OLED/ +3.3V GND

Id: 8/9 Title: OLED Display


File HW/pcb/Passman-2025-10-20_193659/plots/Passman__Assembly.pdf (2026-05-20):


D Date: 2025-09-30 KiCad; E.D.A. 9.0.1 Size: A4; Rev: 2v0; Id: /1 Title: PassMan PCB Layout File: Passman.kicad_pcb Sheet: Black; And; White; BOT Bc. Jan Sedlak Board2Pdf:; Black; BOT -; Page 2/2

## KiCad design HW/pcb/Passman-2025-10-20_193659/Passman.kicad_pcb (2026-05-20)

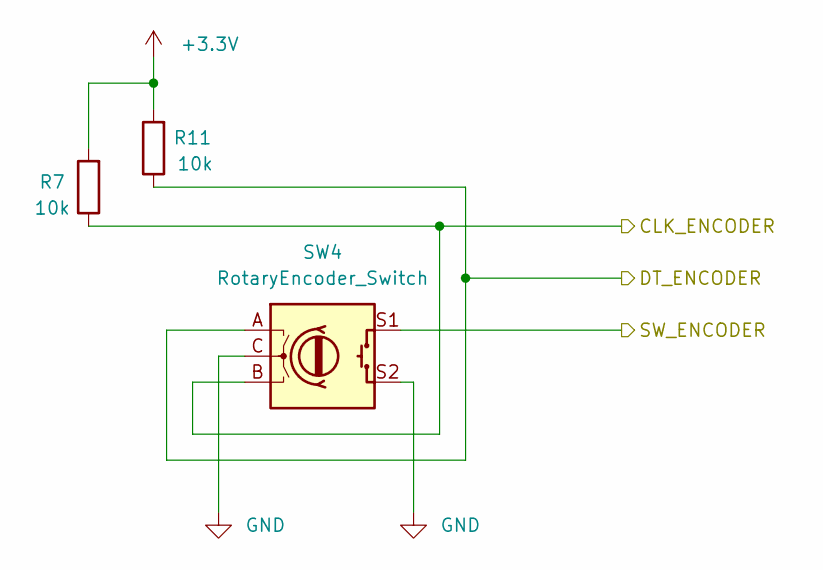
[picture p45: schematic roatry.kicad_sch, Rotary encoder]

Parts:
R7, R11: 10k; R_0805_2012Metric
SW4: RotaryEncoder_Switch; RotaryEncoder_Bourns_Horizontal_PEC09-2xxxF-Sxxxx

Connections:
+3.3V: R7.2, R11.2; also elsewhere on the board
/ESP32_S3/CLK_ENCODER: R7.1, SW4.B; also elsewhere on the board
/ESP32_S3/DT_ENCODER: R11.1, SW4.A; also elsewhere on the board
/ESP32_S3/SW_ENCODER: SW4.S1; also elsewhere on the board

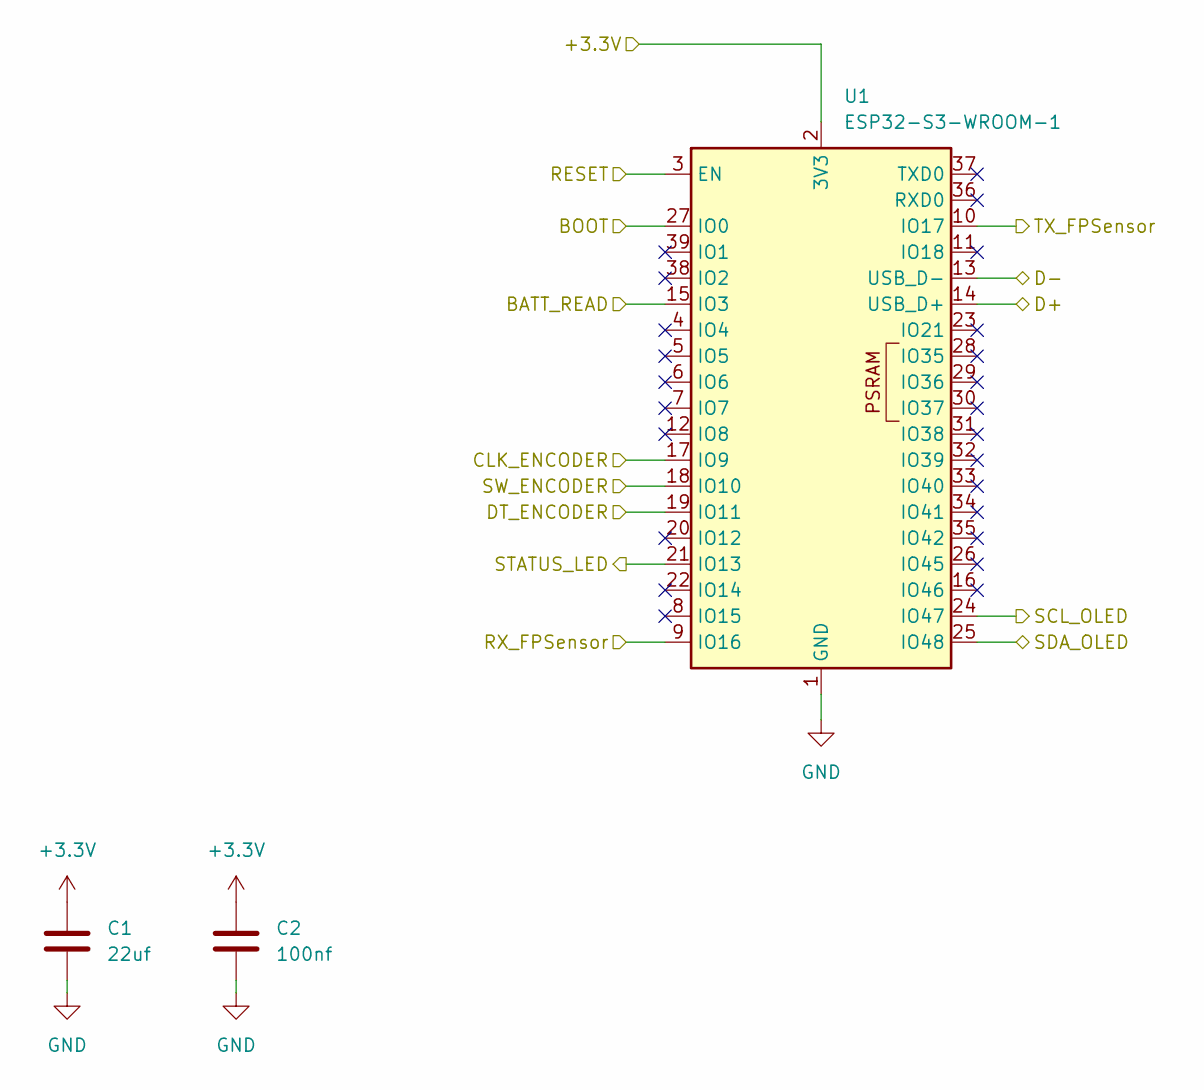
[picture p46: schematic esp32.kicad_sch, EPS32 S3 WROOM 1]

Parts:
C1: 22uf; C_0805_2012Metric_Pad1.18x1.45mm_HandSolder
C2: 100nf; C_0805_2012Metric_Pad1.18x1.45mm_HandSolder
U1: ESP32-S3-WROOM-1

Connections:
+3.3V: C1.1, C2.1, U1.2 (3V3); also elsewhere on the board
/ESP32_S3/BATT_READ: U1.15 (IO3); also elsewhere on the board
/ESP32_S3/BOOT: U1.27 (IO0); also elsewhere on the board
/ESP32_S3/CLK_ENCODER: U1.17 (IO9); also elsewhere on the board
/ESP32_S3/D+: U1.14 (USB_D+); also elsewhere on the board
/ESP32_S3/D-: U1.13 (USB_D-); also elsewhere on the board
/ESP32_S3/DT_ENCODER: U1.19 (IO11); also elsewhere on the board
/ESP32_S3/RESET: U1.3 (EN); also elsewhere on the board
/ESP32_S3/RX_FPSensor: U1.9 (IO16); also elsewhere on the board
/ESP32_S3/SCL_OLED: U1.24 (IO47); also elsewhere on the board
/ESP32_S3/SDA_OLED: U1.25 (IO48); also elsewhere on the board
/ESP32_S3/SW_ENCODER: U1.18 (IO10); also elsewhere on the board
/ESP32_S3/TX_FPSensor: U1.10 (IO17); also elsewhere on the board
/ESP32_S3/USER_LED: U1.21 (IO13); also elsewhere on the board

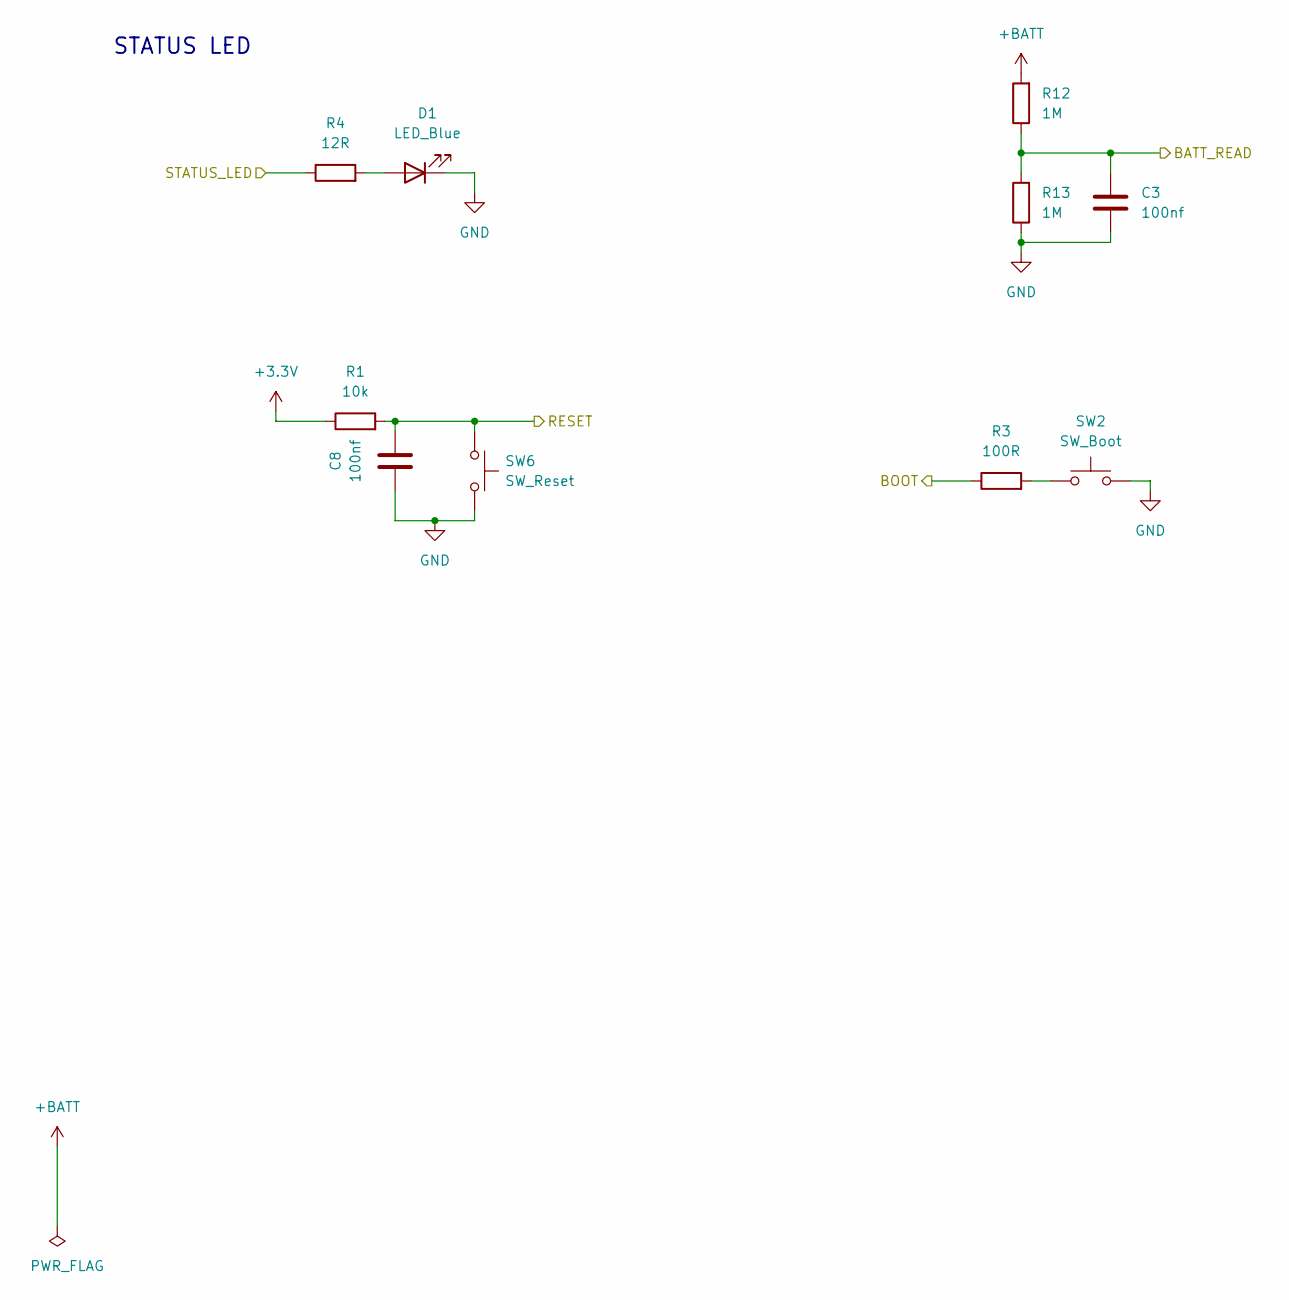
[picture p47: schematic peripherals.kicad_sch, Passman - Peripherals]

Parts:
C3, C8: 100nf; C_0805_2012Metric_Pad1.18x1.45mm_HandSolder
D1: LED_Blue; LED_0805_2012Metric_Pad1.15x1.40mm_HandSolder
R1: 10k; R_0805_2012Metric
R3: 100R; R_0805_2012Metric
R4: 12R; R_0805_2012Metric
R12, R13: 1M; R_0805_2012Metric
SW2: SW_Boot; SW_PUSH_6mm_H5mm
SW6: SW_Reset; SW_PUSH_6mm_H5mm

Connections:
+3.3V: R1.1; also elsewhere on the board
+BATT: R12.2; also elsewhere on the board
/ESP32_S3/BATT_READ: C3.1, R12.1, R13.2; also elsewhere on the board
/ESP32_S3/BOOT: R3.1; also elsewhere on the board
/ESP32_S3/RESET: C8.2, R1.2, SW6.1; also elsewhere on the board
/ESP32_S3/USER_LED: R4.1; also elsewhere on the board
unnamed: D1.2 (A), R4.2
unnamed: R3.2, SW2.1

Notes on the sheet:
STATUS LED

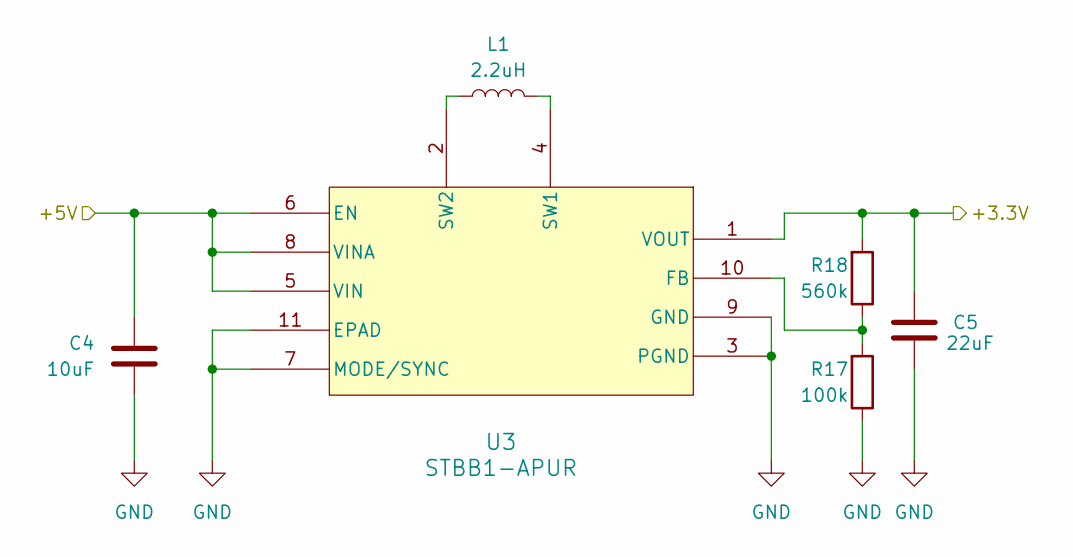
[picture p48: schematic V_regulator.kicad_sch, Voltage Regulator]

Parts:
C4: 10uF; C_0805_2012Metric_Pad1.18x1.45mm_HandSolder
C5: 22uF; C_0805_2012Metric_Pad1.18x1.45mm_HandSolder
L1: 2.2uH; L_Coilcraft_XxL4020
R17: 100k; R_0805_2012Metric
R18: 560k; R_0805_2012Metric
U3: STBB1-APUR; SON_B1-APUR_STM

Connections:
+3.3V: C5.1, R18.2, U3.1 (VOUT); also elsewhere on the board
+5V: C4.1, U3.5 (VIN), U3.6 (EN), U3.8 (VINA); also elsewhere on the board
unnamed: R17.2, R18.1, U3.10 (FB)
unnamed: L1.1, U3.4 (SW1)
unnamed: L1.2, U3.2 (SW2)

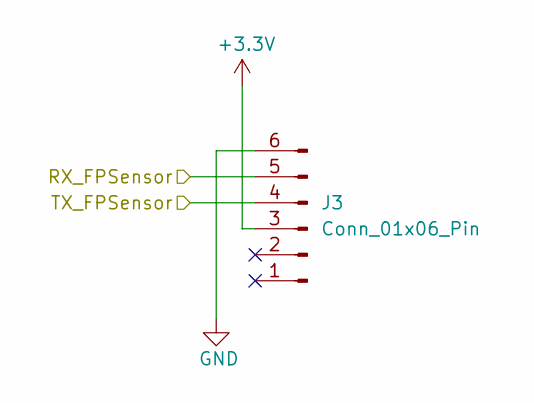
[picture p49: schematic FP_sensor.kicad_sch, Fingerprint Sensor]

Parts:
J3: Conn_01x06_Pin; JST_SH_BM06B-SRSS-TB_1x06-1MP_P1.00mm_Vertical

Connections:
+3.3V: J3.3; also elsewhere on the board
/ESP32_S3/RX_FPSensor: J3.5; also elsewhere on the board
/ESP32_S3/TX_FPSensor: J3.4; also elsewhere on the board

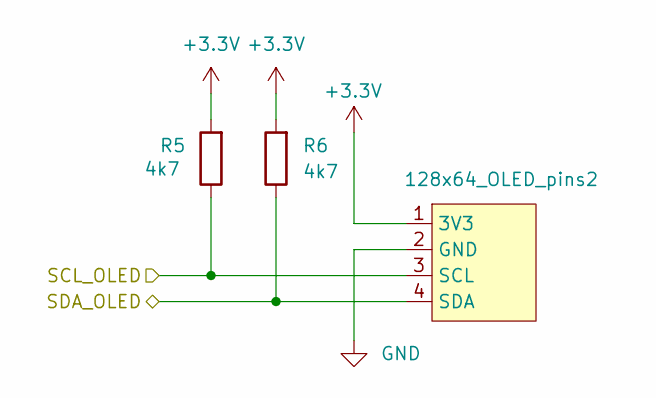
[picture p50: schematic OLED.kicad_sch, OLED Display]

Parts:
128x64_OLED_pins2: PinHeader_1x04_P2.54mm_Vertical
R5, R6: 4k7; R_0805_2012Metric

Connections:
+3.3V: 128x64_OLED_pins2.1 (3V3), R5.2, R6.2; also elsewhere on the board
/ESP32_S3/SCL_OLED: 128x64_OLED_pins2.3 (SCL), R5.1; also elsewhere on the board
/ESP32_S3/SDA_OLED: 128x64_OLED_pins2.4 (SDA), R6.1; also elsewhere on the board

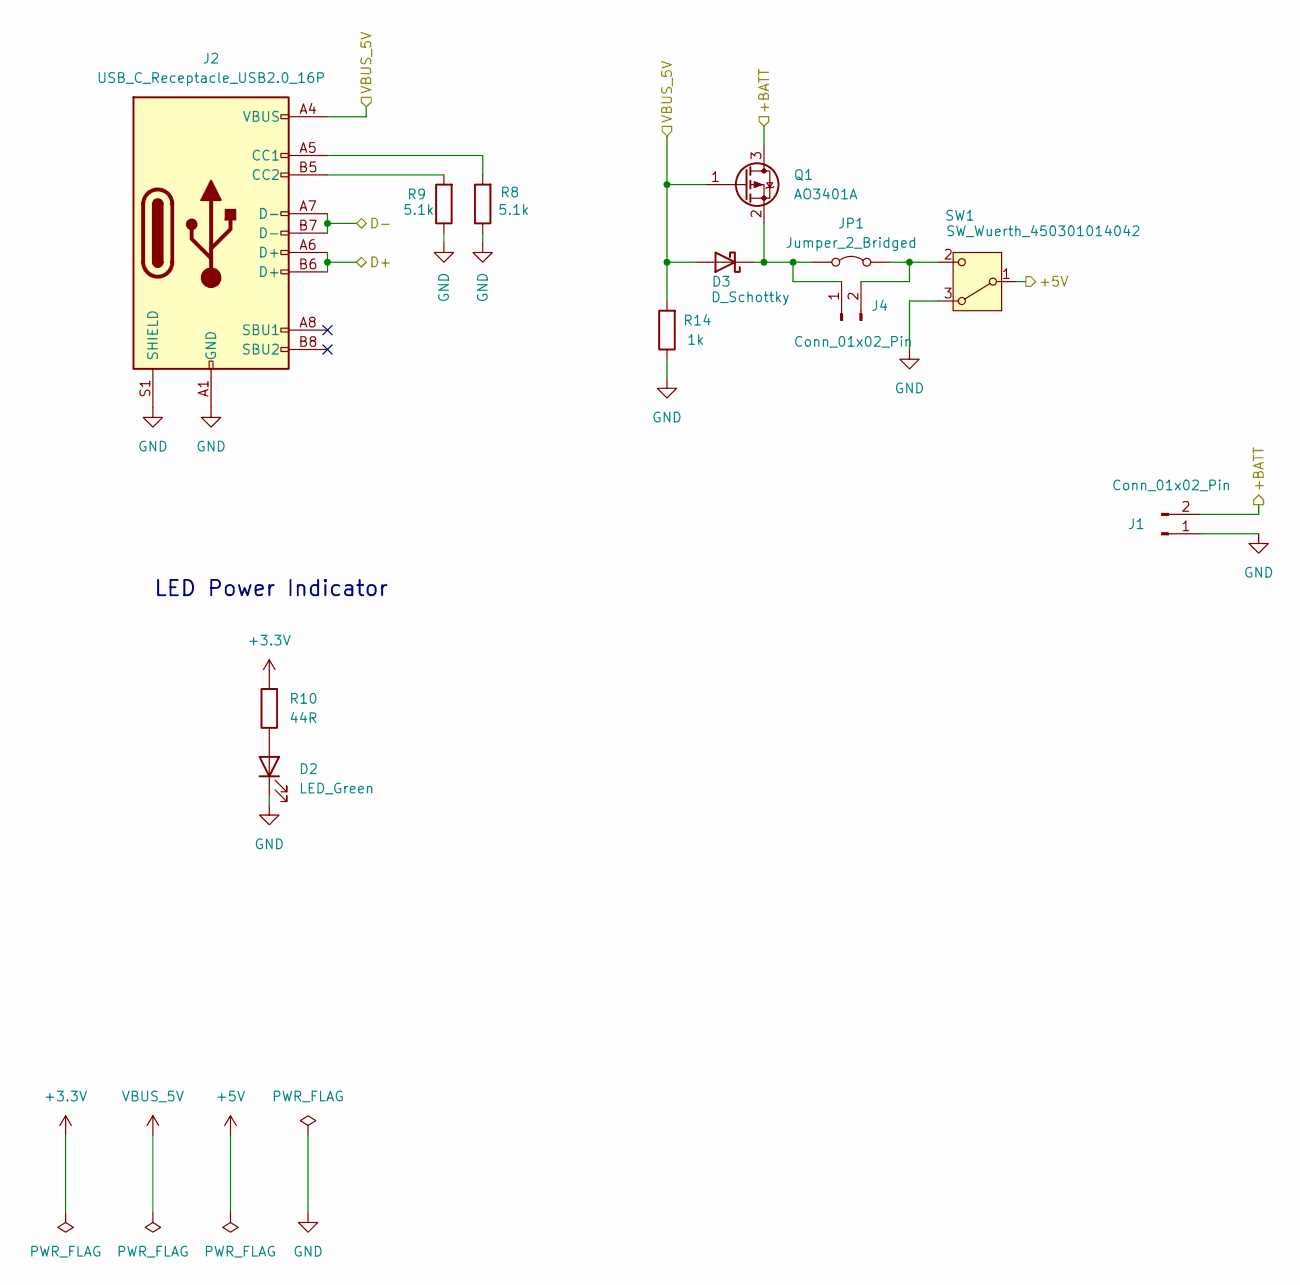
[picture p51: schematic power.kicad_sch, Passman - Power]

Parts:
D2: LED_Green; LED_0805_2012Metric_Pad1.15x1.40mm_HandSolder
D3: D_Schottky; D_0805_2012Metric_Pad1.15x1.40mm_HandSolder
J1: Conn_01x02_Pin; JST_SH_BM02B-SRSS-TB_1x02-1MP_P1.00mm_Vertical
J2: USB_C_Receptacle_USB2.0_16P; USB_C_Receptacle_GCT_USB4105-xx-A_16P_TopMnt_Horizontal
J4: Conn_01x02_Pin; PinHeader_1x02_P1.27mm_Vertical
JP1: Jumper_2_Bridged; SolderJumper-2_P1.3mm_Open_TrianglePad1.0x1.5mm
Q1: AO3401A; SOT-23
R8, R9: 5.1k; R_0805_2012Metric
R10: 44R; R_0805_2012Metric
R14: 1k; R_0805_2012Metric
SW1: SW_Wuerth_450301014042; SW_Slide-03_Wuerth-WS-SLTV_10x2.5x6.4_P2.54mm

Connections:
+3.3V: R10.2; also elsewhere on the board
+5V: SW1.1 (B); also elsewhere on the board
+BATT: J1.2, Q1.3 (D); also elsewhere on the board
/ESP32_S3/D+: J2.A6 (D+), J2.B6 (D+); also elsewhere on the board
/ESP32_S3/D-: J2.A7 (D-), J2.B7 (D-); also elsewhere on the board
unnamed: D2.2 (A), R10.1
unnamed: D3.1 (K), J4.1, JP1.1 (A), Q1.2 (S)
unnamed: J4.2, JP1.2 (B), SW1.2 (C)
VBUS_5V: D3.2 (A), J2.A4 (VBUS), J2.A9 (VBUS), J2.B4 (VBUS), J2.B9 (VBUS), Q1.1 (G), R14.2; also elsewhere on the board

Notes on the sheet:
LED Power Indicator

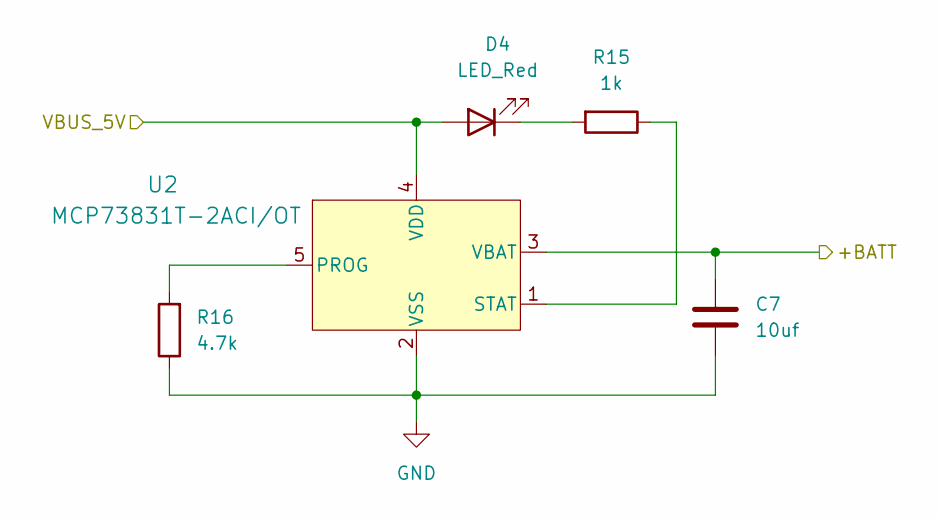
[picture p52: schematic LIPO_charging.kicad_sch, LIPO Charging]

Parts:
C7: 10uf; C_0805_2012Metric_Pad1.18x1.45mm_HandSolder
D4: LED_Red; LED_0805_2012Metric_Pad1.15x1.40mm_HandSolder
R15: 1k; R_0805_2012Metric
R16: 4.7k; R_0805_2012Metric
U2: MCP73831T-2ACI/OT; SOT95P280X145-5N

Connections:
+BATT: C7.1, U2.3 (VBAT); also elsewhere on the board
unnamed: D4.1 (K), R15.2
unnamed: R16.2, U2.5 (PROG)
unnamed: R15.1, U2.1 (STAT)
VBUS_5V: D4.2 (A), U2.4 (VDD); also elsewhere on the board

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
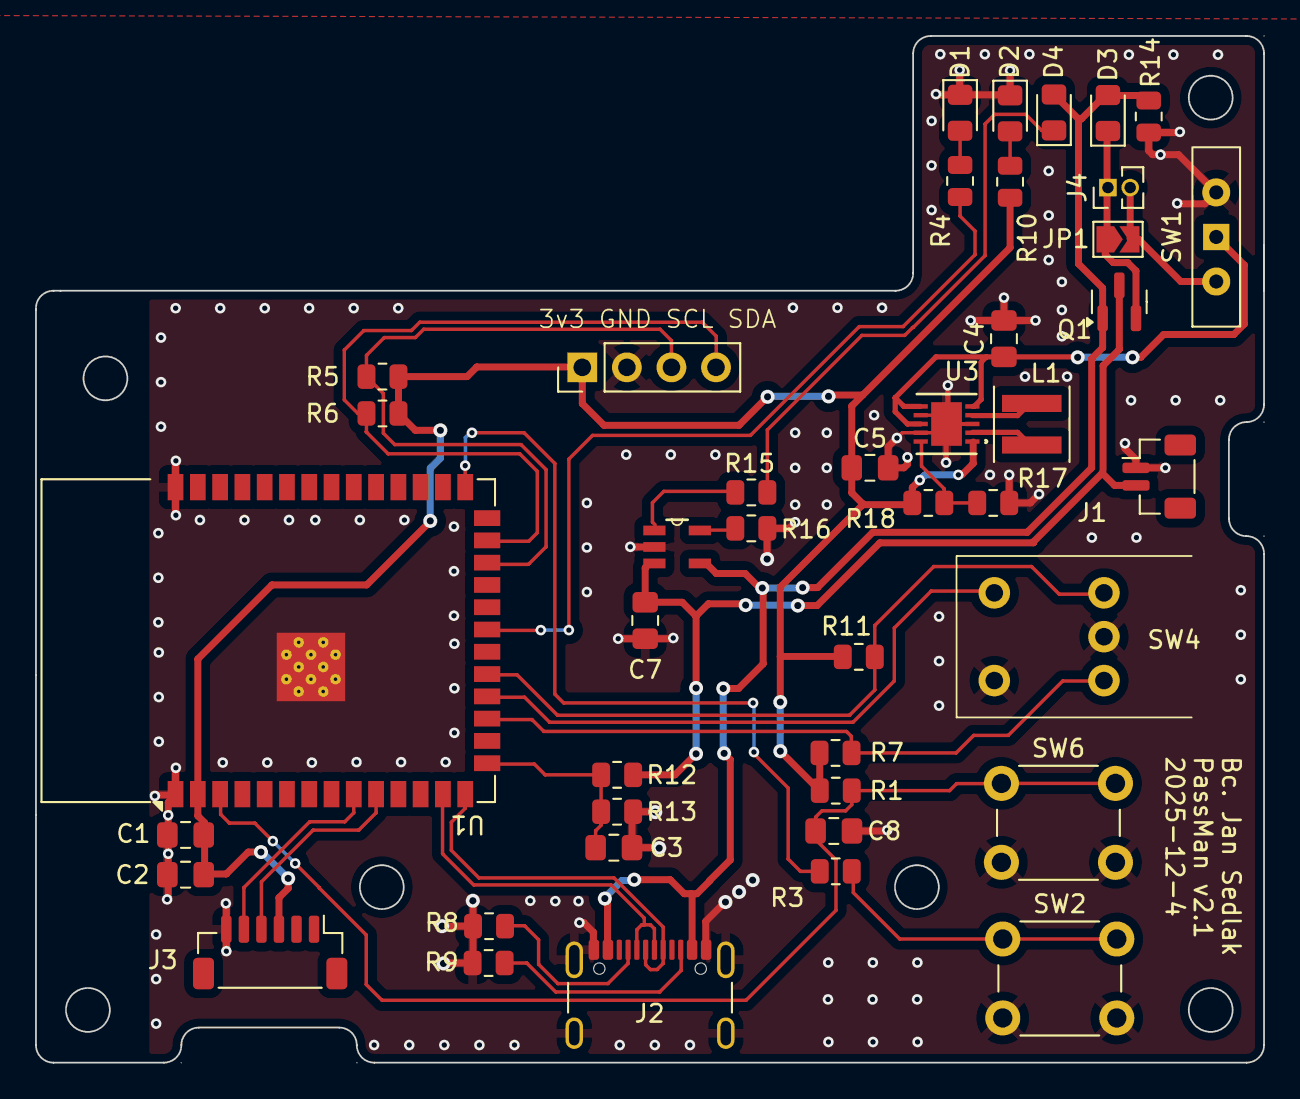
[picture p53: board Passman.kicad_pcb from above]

Board: 2 copper layers, 70.0 x 58.5 mm, 43 parts (0 on the bottom side), 31 nets.

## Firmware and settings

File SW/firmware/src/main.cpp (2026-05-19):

#include <Arduino.h>
#include "rotary.h"
#include "oled.h"
#include "fpcheck.h"
#include "database.h"
#include "encryption.h"
#include "authentication.h"

#define BAUDRATE 115200
#define USERLED 13 // blue user led definition

/* HELLO */

/* Global variables */
int uploadHandler = 0;     // Handles upload action
int connectionHandler = 0; // Handles connection to the app
int downloadHandler = 0;   // Handles download action
int dbLength = 0;          // Updates database legth

void setup()
{
  /* OLED display init */
  display_setup();
  display.clearDisplay(); // init clearence

  Serial.begin(BAUDRATE);

  /* User LED setup */
  pinMode(USERLED, OUTPUT);

  /* Battery level setup */
  pinMode(3, INPUT);

  /* Rotary encoder init */
  rotary_setup();

  /* Finger Print sensor init */
  fpSetup(); // Sets up fp sensor

  /* Unlock Procedure */
  unlockProcedure();

  /* Init SPIFFS */
  init_spiffs_db();

  /* update db length */
  dbLength = updateDbLength();
}

void loop()
{
  // BASIC MENU
  if (rotaryEncoder.readEncoder() == 1) // Database
  {
    menuPage1();
    if (rotaryEncoder.isEncoderButtonClicked(300))
    {
      rotaryEncoder.setEncoderValue(0);
      rotaryEncoder.setBoundaries(0, dbLength - 1, false); // update boundaries to db lenght
      while (!rotaryEncoder.isEncoderButtonClicked())
      {
        databasePage(rotaryEncoder.readEncoder()); // show database
      }
      rotaryEncoder.setBoundaries(1, 6, false); // update boundaries to db lenght
    }
  }

  // Connect to APP
  else if (rotaryEncoder.readEncoder() == 2) // Upload
  {
    menuPage2();

    // Initialize Serial port
    if (!Serial)
    {
      Serial.begin(115200); // Start Serial communication at 115200 baud rate
      delay(100);           // Short delay to ensure Serial is ready
    }

    if (rotaryEncoder.isEncoderButtonClicked(300)) // When encoder is clicked
    {
      // Open the JSON file
      FILE *file = fopen("/spiffs/device.json", "r");
      if (!file)
      {
        Serial.println("Failed to open device.json");
        return;
      }

      // Read the file into a buffer
      char buffer[256];
      size_t bytesRead = fread(buffer, 1, sizeof(buffer) - 1, file);
      buffer[bytesRead] = '\0'; // Null-terminate the buffer
      fclose(file);

      // Parse the JSON data
      StaticJsonDocument<512> doc;
      DeserializationError error = deserializeJson(doc, buffer);
      if (error)
      {
        Serial.print("Failed to parse JSON: ");
        Serial.println(error.c_str());
        return;
      }

      // Extract device information
      JsonObject deviceInfo = doc["deviceInfo"];
      const char *deviceName = deviceInfo["device Name"];
      const char *fwVersion = deviceInfo["FW Version"];
      const char *hwVersion = deviceInfo["HW Version"];
      const char *serialNumber = deviceInfo["SN"];

      // Send device information to the app
      Serial.println("Device Information:");
      Serial.println((String) "Name: " + deviceName);
      Serial.println((String) "FW: " + fwVersion);
      Serial.println((String) "HW: " + hwVersion);
      Serial.println((String) "SN: " + serialNumber);

      // Turn on USER LED to indicate connection
      connectionHandler = 1;
      digitalWrite(USERLED, HIGH);
      //  Serial.println("Command: upload");
      while (connectionHandler == 1)
      {
        digitalWrite(USERLED, HIGH);
        // load command
        if (Serial.available() > 0)
        {
          String message = Serial.readStringUntil('\n');
          message.trim(); // Remove any trailing whitespace or newline characters
          if (message == "load")
          {
            Serial.println("data");
            for (int i = 0; i < dbLength; i++)
            {
              Serial.printf("%s;%s;%s\n", encrypt_data(db.id[i].c_str()).c_str(), encrypt_data(db.username[i].c_str()).c_str(), encrypt_data(db.password[i].c_str()).c_str());
            }
          }
          // Download command
          else if (message == "download")
          {
            // Read the database length from the next line
            while (Serial.available() == 0)
            {
              // Wait for data
            }
            String lengthLine = Serial.readStringUntil('\n');
            lengthLine.trim();
            int newDbLength = lengthLine.toInt();
            dbLength = newDbLength; // update db length

            for (int i = 0; i < newDbLength; i++)
            {
              while (Serial.available() == 0)
              {
                // Wait for data
              }
              String dataLine = Serial.readStringUntil('\n');
              dataLine.trim();                // Remove any trailing whitespace or newline characters
              parseAndStoreData(dataLine, i); // data are being decrypted in this function
              dataLine = "";
            }
          }
          // Handle info command
          else if (message == "info")
          {
            // Send device information to the app
            Serial.println("Device Information:");
            Serial.println((String) "Name: " + deviceName);
            Serial.println((String) "FW: " + fwVersion);
            Serial.println((String) "HW: " + hwVersion);
            Serial.println((String) "SN: " + serialNumber);
          }
          // Handle "disconnect" command
          else if (message == "disconnect")
          {
            connectionHandler = 0;
            Serial.println("Disconnected from app.");
            digitalWrite(USERLED, LOW); // Turn off USER LED

            Serial.end(); // Turn off Serial communication
            break;
          }
        }
      }
    }
  }

  // ADD FP
  else if (rotaryEncoder.readEncoder() == 3) // Reboot
  {
    menuPage3(); // You may want a dedicated menu page for Reboot
    if (rotaryEncoder.isEncoderButtonClicked())
    {

      Serial.println("Ready to enroll a fingerprint!");
      Serial.println("Please type in the ID # (from 1 to 127) you want to save this finger as...");
      int id;
      rotaryEncoder.setBoundaries(1, 10, false);
      rotaryEncoder.setEncoderValue(1);
      while (!rotaryEncoder.isEncoderButtonClicked())
      {
        id = rotaryEncoder.readEncoder();
        getID(id);
      }
      rotaryEncoder.setBoundaries(1, 6, false);
      if (id == 0)
      { // ID #0 not allowed, try again!
        return;
      }
      Serial.print("Enrolling ID #");
      Serial.println(id);

      while (!getFingerprintEnroll(id))
        ;
    }
  }

  // SAVE DATABASE
  else if (rotaryEncoder.readEncoder() == 4) // Save
  {
    menuPage4(); // You may want a dedicated menu page for Save
    if (rotaryEncoder.isEncoderButtonClicked())
    {
      save_spiffs_db();
    }
  }

  // DELETE ALL DATABASE
  else if (rotaryEncoder.readEncoder() == 5) // Delete All
  {
    menuPage5(); // You may want a dedicated menu page for Delete All
    if (rotaryEncoder.isEncoderButtonClicked())
    {
      delete_spiffs_db();
    }
  }
  // SHOW DEVICE INFORMATION
  else if (rotaryEncoder.readEncoder() == 6) // Settings
  {
    menuPage6();
    if (rotaryEncoder.isEncoderButtonClicked())
    {
      while (!rotaryEncoder.isEncoderButtonClicked())
      {
        deviceInfo();
      }
    }
  }
}

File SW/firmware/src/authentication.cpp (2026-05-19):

#include "authentication.h"

#define PINSIZE 4

/* Pin instance */
int pin[4] = {1, 9, 2, 9};

int comparePins(int setPin[], int insertedPin[])
{
    int ok = 1; // help variable to resolve inf inserted pin is correct

    for (int i = 0; i < PINSIZE; i++) // handles if each of inserted pin digits match
    {
        if (!(setPin[i] == insertedPin[i]))
        {
            ok = 0;
            Serial.println("Digit " + (String)i + " is incorrect!");
            delay(250);
        }
        else
        {
            Serial.println("Digit " + (String)i + " is correct!");
            delay(250);
        }
    }

    if (ok == 1)
    {
        Serial.println("Pin inserted successfully...");
        return 1;
    }
    else
    {
        Serial.println("Pin does not match....");
        return 0;
    }
}

/*
    @brief This function is the first step authentication, insert 4-digit pin
*/
void insertPin(int fail)
{
    uint8_t currPos;
    uint8_t unlock = 0; // 0 device locked, 1 device unlocked
    int insertedPin[4];

    // set encoder boundaries to <0;9>
    rotaryEncoder.setBoundaries(0, 9, true);
    currPos = 0;

    while (unlock == 0)
    {
        switch (currPos)
        {
        case 0:
            /* Handle 1st digit */
            display.setCursor(35, 5); // set cursor position
            display.println((String) "INSERT PIN");
            display.setCursor(35, 30);                            // set cursor position
            display.println((String)rotaryEncoder.readEncoder()); // display current value of the encoder
            display.setCursor(35, 38);
            display.println((String) "-");
            display.display();
            delay(10);
            display.clearDisplay();

            if (rotaryEncoder.isEncoderButtonClicked())
            {
                insertedPin[currPos] = rotaryEncoder.readEncoder(); // assign curr value of the encoder to a pin variable
                currPos++;                                          // interate current position
                rotaryEncoder.setEncoderValue(0);                   // reset encoder value
            }
            break;

        case 1:
            /* Handle 2nd digit */
            display.setCursor(35, 5); // set cursor position
            display.println((String) "INSERT PIN");
            display.setCursor(35, 30);                                                            // set cursor position
            display.println((String)insertedPin[0] + "  " + (String)rotaryEncoder.readEncoder()); // display current value of the encoder
            display.setCursor(53, 38);
            display.println((String) "-");
            display.display();
            delay(10);
            display.clearDisplay();

            if (rotaryEncoder.isEncoderButtonClicked())
            {
                insertedPin[currPos] = rotaryEncoder.readEncoder(); // assign curr value of the encoder to a pin variable
                currPos++;                                          // interate current position
                rotaryEncoder.setEncoderValue(0);                   // reset encoder value
            }
            break;

        case 2:
            /* Handle 3rd digit */
            display.setCursor(35, 5); // set cursor position
            display.println((String) "INSERT PIN");
            display.setCursor(35, 30);                                                                                            // set cursor position
            display.println((String)insertedPin[0] + "  " + (String)insertedPin[1] + "  " + (String)rotaryEncoder.readEncoder()); // display current value of the encoder
            display.setCursor(71, 38);
            display.println((String) "-");
            display.display();
            delay(10);
            display.clearDisplay();

            if (rotaryEncoder.isEncoderButtonClicked())
            {
                insertedPin[currPos] = rotaryEncoder.readEncoder(); // assign curr value of the encoder to a pin variable
                currPos++;                                          // interate current position
                rotaryEncoder.setEncoderValue(0);                   // reset encoder value
            }
            break;

        case 3:
            /* Handle 4th digit */
            display.setCursor(35, 5); // set cursor position
            display.println((String) "INSERT PIN");
            display.setCursor(35, 30);                                                                                                                            // set cursor position
            display.println((String)insertedPin[0] + "  " + (String)insertedPin[1] + "  " + (String)insertedPin[2] + "  " + (String)rotaryEncoder.readEncoder()); // display current value of the encoder
            display.setCursor(89, 38);
            display.println((String) "-");
            display.display();
            delay(10);
            display.clearDisplay();

            if (rotaryEncoder.isEncoderButtonClicked())
            {
                insertedPin[currPos] = rotaryEncoder.readEncoder(); // assign curr value of the encoder to a pin variable
                currPos++;                                          // interate current position
                rotaryEncoder.setEncoderValue(0);                   // reset encoder value
            }
            break;

        case 4:
            /* Handles if Pins match */
            unlock = comparePins(pin, insertedPin); // if unlock = 1, while cycle should break
            if (unlock == 0)
            {
                currPos = 0;
                if (fail == 3)
                {
                    fail++;
                }
                else
                {
                    while (1)
                    {
                        display.setCursor(25, 25); // set cursor position
                        display.println((String) "DEVICE BLOCKED");
                        display.display();
                        delay(1000);
                        display.clearDisplay();

                        unsigned long startTime = millis();
                        while (millis() - startTime < 30000)
                        {
                            display.setCursor(25, 25); // set cursor position
                            display.println((String) "WAIT 30 SECONDS");
                            display.display();
                            delay(1000);
                            display.clearDisplay();
                        }
                        break;
                    }
                }
            }
            else
            {
                // Show Tick when succesfully logged in
                unlockSuccessfull(13);
                rotaryEncoder.setEncoderValue(1);
                break;
            }
        }
    }
}
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

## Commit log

2025-06-01 added esp32 documentation
2025-06-15 Firmware directory initialization, oled and rotary drivers added
2025-07-22 added oled i2c finder utility
2025-07-22 init fingerprint function - fpcheck, this function contains basic func to handle fp sensor operations
2025-07-27 added fingerprint sensor and featured utilities
2025-10-17 new repo structure
    [OLED_1_3INCH_I2C.step, pcb_sketch_v10.dxf, pcb_sketch_v2 v9.dxf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]
2025-10-17 update 17/10/2025
    Added section for the first prototype with an image.
2025-10-18 added pcb 3D model to HW
2025-10-18 updated pcb img
2025-10-22 updated schematic_v2
2025-10-22 device-to-app communication, load database from device
2025-10-23 added Load db and Upload db buttons
2025-10-23 updated schematic
2025-10-24 Updated device-app comm
2025-10-24 added buttons, list of db entries
2025-10-25 fully functional communication device-app
2025-11-06 functional Device -> App encrypted communication of one entry, decrypted in app and saved
2025-11-07 added Delete ALL button - deletes entire database
2025-11-07 added psw visibilit toggle button, new list layout
2025-11-28 added pcb parts placement
2026-01-19 own pcb v2.1 alivegit status! encoder TBD
2026-01-19 update rotary encoder
2026-02-14 added device.json
2026-02-17 adde new features to app-device exp
2026-02-21 connection toggle button added
2026-02-22 new toggle button
2026-02-25 added battery read function
    [OLED_1_3INCH_I2C.step, pcb_sketch_v10.dxf, pcb_sketch_v2 v9.dxf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]
2026-03-13 added pin function
2026-03-13 Added feature with pin unlock and block timer after 4 fails
    [authentication.cpp, fpcheck.cpp, main.cpp]
2026-03-13 5 tries, battery lvl adjustment
2026-03-24 add fingerprint function added
2026-05-19 Revert "Merge pull request #12 from SedlJa/feature/newmenu"
    This reverts commit 42eee86a80cdcba1802b2d28394379cd1a876b0e, reversing
    changes made to 6937fb5cfae5ef343e6ff9fafa659c53ed70236d.
    [app.py, encryption.cpp, encryption.py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]
2026-05-19 Revert "Merge feature/newmenu into main"
    This reverts commit 6937fb5cfae5ef343e6ff9fafa659c53ed70236d, reversing
    changes made to 4d8194ec5ef69cebd220a0963e4b2b26cc86caff.
    [OLED_1_3INCH_I2C.step, pcb_sketch_v10.dxf, pcb_sketch_v2 v9.dxf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]
2026-05-19 Replace main with feature/newmenu content
    [OLED_1_3INCH_I2C.step, pcb_sketch_v10.dxf, pcb_sketch_v2 v9.dxf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]
2026-05-20 upload pcb docs
    [EDI2CAP.CFG, FP_sensor.kicad_sch, LIPO_charging.kicad_sch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]
